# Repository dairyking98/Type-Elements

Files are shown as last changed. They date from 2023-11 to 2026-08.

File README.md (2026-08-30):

# 3D Printed Type Elements for Typewriters

Type elements (shuttles, wheels, typeballs, slugs) for antique
typewriters, generated to order and 3D printed.

The project has three generations. **`v4/` is where active development
happens**; `v2/` and `v1/` are the OpenSCAD lineage it was ported from,
and both still open and render exactly as before.

## v4 (current): Python pipeline + interactive tuner

A Python/`manifold3d` pipeline rather than OpenSCAD - the draft taper is
a real Minkowski sum, every assembly step is a real boolean, and each of
the **15 supported machines** is driven by its own config YAML with an
interactive TUI (`tune.py`) for editing and live-previewing it.

- **[Live documentation site](https://type-elements.leonardchau.com)**
- [`v4/README.md`](v4/README.md) - setup, usage, architecture
- [`v4/LAYOUT_TRANSCRIPTION.md`](v4/LAYOUT_TRANSCRIPTION.md) - how the
  keyboard layouts were transcribed from real manufacturer type catalogs
- [`v4/SESSION_LOG.md`](v4/SESSION_LOG.md) - full development history
- [`v4/CLAUDE.md`](v4/CLAUDE.md) - the conventions and hard-won
  invariants that keep the pipeline correct

Machines: Blickensderfer, Postal, Mignon, Bennett, Helios Klimax,
Hammond, Hammond Split, Selectric I/II, Selectric III, Selectric
Composer, and the Type Slug family (Type Slug, Vogue Slug, Gauge Slug,
Oliver Slug, Lumi Slug).

## v1 / v2 (OpenSCAD): usage

The rest of this file covers the original OpenSCAD workflow. `v2/` is
the shared-library refactor of `v1/`; see
[CHANGELOG.md](CHANGELOG.md) for what moved where.

## Download OpenSCAD snapshot
Download a development snapshot of [OpenSCAD](https://openscad.org/downloads.html#snapshot).

## Open SCAD file
Open an OpenSCAD file. Use the Customizer on the right to create elements and adjust parameters.

## Creating a custom element
1. Install font for all users (right-click the font file > Install for all users).
2. Open an element file.
3. Preview the element and adjust parameters in the Customizer.

## Render and export
Preview → Render → Export STL.

### Meanings
- debug / no minkowski: render element without embossing (faster)
- preview / render / export: typical OpenSCAD workflow

## Documentation

- [Machine specifications](docs/machine-specs.md) — all dimensions and calibrated values per machine
- [Glyph pipeline](docs/glyph-pipeline.md) — how characters are rendered, draft angles, platen cutout, CharLegend
- [Text centering & dead space](docs/text-centering.md) — how `halign="center"` actually centers glyphs, why narrow characters can sit off-center in their slot, and options to correct it
- [Resin support systems](docs/resin-supports.md) — CutGroove, rod geometry, per-machine support placement
- [Resin selection](docs/resin-selection.md) — material choice: glyph fidelity, dimensional stability over time, current printer/slicer/profile setup
- [Calibration procedures](docs/calibration.md) — sweep tests, debugging symptoms, procedure order
- [IBM Composer](docs/ibm-composer.md) — proportional unit system, hemisphere mapping, Composer vs Selectric
- [Refactoring plan](docs/refactoring-plan.md) — shared library architecture, extraction order, old vs new code style (executed as of v2.0, see [CHANGELOG.md](CHANGELOG.md))

## License

Dual-licensed. Which license applies depends on whether a file is
software or design data — [`NOTICE`](NOTICE) has the full breakdown.

| | License | Covers |
|---|---|---|
| **Software** | [GPL-3.0-or-later](LICENSE) | All source — the v4 Python pipeline and tuner, the v1/v2/v3 OpenSCAD files, scripts, site templates |
| **Designs** | [CC BY-NC-SA 4.0](LICENSE-DESIGNS) | Machine dimension/calibration configs, published STLs, renders, documentation |

In plain terms:

- **Print type elements for yourself** — yes, freely. That's what this
  project is for. Give them to other people too, as long as no money
  changes hands.
- **Sell prints** — no. Commercial sale is reserved to the copyright
  holder. If you want to sell them, [ask](https://leonardchau.com) — a
  separate license can be granted.
- **Fork and modify the software** — yes. Keep it open, publish your
  changes under the GPL, keep the attribution.

The split is deliberate: the output of a GPL program isn't covered by
the GPL, so licensing only the code would let anyone regenerate the STLs
and sell them. Licensing the machine data separately is what actually
reserves that.

IBM Selectric geometry was developed jointly with **Otto Koponen**, with
reference material from **[Selectric Rescue](https://selectricrescue.org/)**.
See [`NOTICE`](NOTICE) for full attribution, third-party dependencies,
and a note on fonts.

Contributions are welcome — see [`CONTRIBUTING.md`](CONTRIBUTING.md).

## v2.0: shared library files
`v2/` holds the current, actively-developed set of machine files — a shared
`lib/` (glyph pipeline, resin support, core/shaft, layouts) plus one thin
file per machine. See [CHANGELOG.md](CHANGELOG.md) for what moved where and
which machines share the pipeline. Every v1 file below is untouched and
still opens/renders exactly as before.

- [lib/glyph_pipeline.scad](v2/lib/glyph_pipeline.scad)
- [lib/resin_support.scad](v2/lib/resin_support.scad)
- [lib/core_shaft.scad](v2/lib/core_shaft.scad)
- [lib/testing.scad](v2/lib/testing.scad) — shared calibration-sweep array generator
- lib/layouts/ — [blick](v2/lib/layouts/blick_layouts.scad), [bennett](v2/lib/layouts/bennett_layouts.scad), [mignon](v2/lib/layouts/mignon_layouts.scad), [ibm](v2/lib/layouts/ibm_layouts.scad), [hammond](v2/lib/layouts/hammond_layouts.scad) (postal.scad's single fixed layout stays inline, no separate file)
- [blickensderfer.scad](v2/blickensderfer.scad)
- [postal.scad](v2/postal.scad)
- [bennett.scad](v2/bennett.scad)
- [mignon.scad](v2/mignon.scad)
- [heliosklimax.scad](v2/heliosklimax.scad)
- [ibm.scad](v2/ibm.scad)
- [hammond.scad](v2/hammond.scad)
- [hammond_split.scad](v2/hammond_split.scad)

## v1 SCAD files by directory
The following directories (now under `v1/`) contain the original machine-specific type elements:
- Bennett
  - [BennettElement.scad](v1/Bennett/BennettElement.scad)
  - [BennettLayouts.scad](v1/Bennett/BennettLayouts.scad)
- Blickensderfer
  - [Blickensderfer2.scad](v1/Blickensderfer/Blickensderfer2.scad)
  - [BlickensderferElement.scad](v1/Blickensderfer/BlickensderferElement.scad)
  - [HebrewBlickensderferElement.scad](v1/Blickensderfer/HebrewBlickensderferElement.scad)
- Hammond
  - [GalgolicHammondShuttle.scad](v1/Hammond/GalgolicHammondShuttle.scad)
  - [HammondIndex.scad](v1/Hammond/HammondIndex.scad)
  - [HammondShuttle.scad](v1/Hammond/HammondShuttle.scad)
  - [HammondSplitShuttle.scad](v1/Hammond/HammondSplitShuttle.scad)
  - [HammondSplitShuttle2.scad](v1/Hammond/HammondSplitShuttle2.scad)
- HeliosKlimax
  - [HeliosKlimaxElement.scad](v1/HeliosKlimax/HeliosKlimaxElement.scad)
  - [HeliosKlimaxTester.scad](v1/HeliosKlimax/HeliosKlimaxTester.scad)
  - [imagetest.scad](v1/HeliosKlimax/imagetest.scad)
- IBM
  - [IBM2.scad](v1/IBM/IBM2.scad)
- Mignon
  - [MignonCylinder.scad](v1/Mignon/MignonCylinder.scad)
  - [MignonIndex.scad](v1/Mignon/MignonIndex.scad)
  - [MignonIndexLayouts.scad](v1/Mignon/MignonIndexLayouts.scad)
- Postal
  - [Postal.scad](v1/Postal/Postal.scad)

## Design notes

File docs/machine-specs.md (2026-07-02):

# Machine Specifications

All measured dimensions and calibrated values per machine. Values in the `.json` Customizer preset files are the authoritative source; this document is the summary reference.

---

## Coordinate conventions

**Z=0** is the drive-pin / reference face (seats against machine stop). `charBaselines` and `platenBaselines` are **negative offsets from Z=cylHeight** (the clip end). Absolute Z from reference = `cylHeight + charBaselines[row]`.

> Warning: the scad files are inconsistent. Blick/Postal use negative-from-clip-end. Bennett stores baselines as positive values from the bottom face. Helios stores them as positive from bottom. Reconcile when refactoring into shared library.

---

## Blickensderfer No. 5/7/9

**Active file:** `Blickensderfer/Blickensderfer2.scad`

| Parameter | Value | Notes |
|---|---|---|
| Element OD (`cylOD`) | 34 mm | Fixed |
| Text OD | 35 mm | Fixed |
| Element height (`cylHeight`) | **17.15 mm** | Evolved: 16.75→17.05→17.15 |
| Shaft ID (1/8" nominal) | 3.175 mm | Fixed |
| Shaft bore offset (`coreIDOffset`) | **0.14 mm** | Calibrated |
| Platen OD | 32.258 mm | Fixed |
| Rows × cols | 3 × 28 | Fixed |
| Char baselines from clip end | **[-4.0, -10.3, -16.1] mm** | Stable |
| Platen baselines from clip end | **[-2.55, -8.66, -14.45] mm** | See history below |
| Speed holes | 8 × ⌀5.568 mm at r=11.25 mm | Fixed |
| Drive pin width | 3.737 mm + offset 0.15 mm | New style |
| Drive pin radial | 10.9 mm | Calibrated (from 11.25 mm) |
| Drive pin style | 0 (new) | 1 = old style for early machines |
| Clip height | 3 mm, bite 0.7 mm | Settled |
| Clip wire OD | 0.554 mm | Fixed |
| Wall min thickness | 1.5 mm | Fixed |
| Char protrusion | 0.5 mm | Fixed |
| Draft angle | 55° | Fixed |
| Core grooves | 16 × ⌀0.6 mm | Toroidal bore grooves |

**Platen baseline calibration history:**

| Preset | Row 0 | Row 1 | Row 2 |
|---|---|---|---|
| jan 18 (first) | -2.60 | -8.66 | -14.60 |
| hebrew jan21 | -2.55 | -8.66 | -14.60 |
| MMS2 4/5 | -2.55 | -8.66 | -14.55 |
| MMS3 4/6 / 4/6 Leo | -2.55 | -8.66 | -14.50 |
| **tmp 4/12 → current** | **-2.55** | **-8.66** | **-14.45** |

**Fonts used:** FreeMono (3.0mm), Alma Mono (2.4mm), Souvenir Mono Rg (2.6mm), Clack (3.0mm), True_Vogue (3.3mm), Comic Mono (3.0mm), LTCRemingtonTypewriterW10 (2.6mm), custom scripts.

**Layouts:** DHIATENSOR (default), QWERTY, SCANDI, HEBREW_ENGL, CHARIENSTU_DE.

**CharLegend** (keyboard→element column mapping):
```
[13,12,11,10,9,8,7,6,5,4,3,2,1,0, 27,26,25,24,23,22,21,20,19,18,17,16,15,14]
 ← right half, reversed →          ← left half, reversed →
```

---

## Postal Model 3 (SN 14550)

**Active file:** `Postal/Postal.scad`

| Parameter | Value | Notes |
|---|---|---|
| Element OD | 32.8 mm | Fixed |
| Text OD | 34.1 mm | Fixed |
| Element height | 17.4 mm | Fixed |
| Shaft ID | 3.175 mm (1/8") | Fixed |
| Shaft bore offset | **0.20 mm** | Higher than Blick |
| Platen OD | 31.9 mm | Fixed |
| Rows × cols | 3 × 28 | Fixed |
| Char baselines from clip end | **[-3.6, -10.0, -15.7] mm** | Evolved from [-3.8,-10.2,-15.7] |
| Platen baselines from clip end | **[-2.65, -9.1, -14.5] mm** | Evolved from [-3.4,-9.8,-15.3] |
| Speed holes | 8 × ⌀5.2 mm at r=10.3 mm | Fixed |
| Drive pin width | 2.5 mm | Fixed |
| Drive pin radial | 11.5 mm | Calibrated |
| Clip bite | 0.7 mm | Calibrated |
| Char protrusion | 0.65 mm | Fixed |
| Draft angle | 55° | Fixed |
| Core grooves | 16 × ⌀0.6 mm | Same as Blick |

**Platen baseline history:** [-3.40,-9.80,-15.30] → [-3.00,-9.50,-14.50] → **[-2.65,-9.10,-14.50]**

---

## Bennett

**Active file:** `Bennett/BennettElement.scad`

| Parameter | Value |
|---|---|
| Element OD | 31.9 mm |
| Element height | 18.65 mm |
| Shaft dia | 3.483 mm |
| Platen OD | 30 mm |
| Min char OD | 32.9 mm |
| Rows × cols | 3 × 28 |
| Baselines (**from bottom**) | [15.35, 9.2, 2.75] mm |
| Platen baselines (**from bottom**) | [16.35, 10.65, 4.50] mm |
| Speed holes | 8 × ⌀6.1 mm at r=10.801 mm |
| Countersink top | ⌀23.4 mm, depth 1.85 mm |
| Countersink bottom | ⌀23.4 mm, depth 0.9 mm |
| Positioner pin | ⌀2.6 mm at r=4.813 mm |
| Alignment holes | ⌀2.0 mm, depth 2.4 mm (at every char position on OD) |
| Shell thickness | 1.0 mm |

**Unique:** alignment holes at every character position on the outer diameter face.

---

## Mignon (AEG Mignon 2/3/4)

**Active file:** `Mignon/MignonCylinder.scad`

| Parameter | Value |
|---|---|
| Cylinder OD | 18.64 mm |
| Cylinder height | 40.5 mm (43.5 mm Tallen/Plakatschrift variant) |
| Top shaft OD | 7.3 mm |
| Bottom mounting boss OD | 14.6 mm |
| Platen OD | 26.5 mm |
| Min char OD | 19.4 mm |
| Rows × cols | 7 × 12 |
| Baselines | [2.25, 7.55, 12.75, 17.8, 22.8, 28, 32.8] mm |
| Platen baselines | [2.7, 8.25, 13.6, 18.7, 23.7, 28.7, 33.6] mm |
| Top chamfer | ⌀10.5 mm at offset 3 mm |
| Pin | 1.8 mm height × 1.7 mm wide × 1.0 mm depth |

Layouts: 32+ languages via `MignonIndexLayouts.scad`.

---

## Helios Klimax

**Active file:** `HeliosKlimax/HeliosKlimaxElement.scad`

| Parameter | Value |
|---|---|
| Element OD | 27.15 mm |
| Element height | 18.7 mm |
| Shaft dia | 4.16 mm |
| Platen OD | 30 mm |
| Min char OD | 28.19 mm |
| Rows × cols | 4 × 21 |
| Baselines (**from bottom**) | [3.0, 7.8, 12.5, 17.3] mm |
| Platen baselines (**from bottom**) | [2.5, 7.3, 12.0, 16.8] mm |
| Square shaft hole | 4.10 × 2.88 mm at r=8.92 mm |
| Clip | height 3 mm, dia 7 mm |
| Indicator hole | ⌀2.0 mm at r=10 mm |

Layout: GERMAN (WERTUION keyboard, 4 rows).

---

## Hammond Multiplex

**Active file:** `Hammond/HammondSplitShuttle2.scad`

Prints in two mirror-image halves that slide onto a central folder tube.

| Parameter | Value |
|---|---|
| Anvil OD | 75 mm |
| Arc thickness | 1.6 mm |
| Arc height | 13.26 mm |
| Arc height offset | -2.62 mm |
| Glyph height | 0.8 mm |
| Rows | 3 (Normal), 4 (Math) |
| Chars per row | 30 |
| Degrees per char | 3.75° (=360/96) |
| Folder OD | 21 mm |
| Folder ID clearance | 12 + 0.4 mm |
| Folder thickness | 9.525 mm |
| Pin hole dia | 1.92 mm |
| Pin holes at | 68.27°, 109.97° |
| Pin radial | 7.95 mm |
| Rib OD | 46.8 mm, thickness 2.6 mm |
| Spoke count | 5, extent 45° |
| Left tube OD | 6.6548 mm |
| Right tube OD | 5.842 mm |
| Baselines from rib | [-1.9, 2.825, 7.55] mm |

Layouts: Ideal (default), QWERTY.

---

## IBM Selectric I/II and Composer

**Active file:** `IBM/IBM2.scad` (collaborative with Otto Koponen)

| Parameter | Value |
|---|---|
| Sphere OD | 33.4 mm |
| Max char OD | 34.9 mm |
| Sphere center to top flat | 11.0 mm |
| Top flat thickness | 3.5 mm |
| Inside ID | 28.15 mm |
| Shaft ID | 8.8 mm |
| Boss OD | 11.6 mm |
| Rows | 4 (at ±0°, ±16.4°, ±32.8° longitude) |
| Chars per row | 22 per hemisphere = 44 total |
| Char spacing | 16.36°/char |
| Drive notch | 1.06 mm wide × 2.2 mm tall |
| Platen OD (Composer) | 43 mm |
| Platen OD (Selectric I/II) | 36 mm |
| Snoot droop compensation | 0.42 mm |

**Modes:** `RENDER_MODE=0` = IBM Composer 88-char; `RENDER_MODE=1` = Selectric I/II 88-char.

**Calibrated values:** `PLATEN_LONGITUDE_OFFSETS=[-1.05, -1.05, -1, -1.05]` (one per row).

See `docs/ibm-composer.md` for the proportional spacing system.

---

## Type Slugs

**Files:** `Type Slugs/TypeSlug.scad` and variants (Vogue, Oliver, Lumitype).

Flat individual slugs for conventional typebar machines (not type elements). Two characters per slug (upper/lower case). Parametric wing curve for typebar slot, platen cutout, Minkowski draft angle on glyph faces. Default body: 2.75 × 12.0 × 5.0 mm.

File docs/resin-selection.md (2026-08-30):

# Resin Selection

Notes on resin material choice for printing type elements, as distinct from
`resin-supports.md` (which covers support *geometry*, not material). Kept here
because the choice is really a legibility/durability tradeoff specific to
glyph faces, not a general printing note.

---

## Priorities for this use case

Type elements are graded on one thing above all: **glyph face fidelity**.
Sharp serifs, clean stroke edges, and legible small type at the scale these
elements print at matter more than surviving a drop or a hard strike. The
elements sit in a machine and take repeated but low-energy impact against a
ribbon/platen — not the kind of abuse a handled miniature takes. That reframes
the usual "detail vs. durability" resin tradeoff: durability past a fairly low
bar is wasted margin here, and buys real fidelity loss.

The exception is thin structural features that aren't glyph faces — support
necks, drive pins, boss walls (see `resin-supports.md`) — which take bending/
torque loads, not impact, and can still snap if a resin is too brittle at a
thin cross-section. Detail-vs-durability trades off against glyph sharpness;
it doesn't excuse ignoring wall thickness at those specific spots.

**Dimensional stability over time is a co-equal priority**, added after the
fact — see its own section below. It is not in tension with fidelity; both
point away from the same family.

---

## Current setup

Recorded 2026-08-29 by reading the actual installed state, not from memory.
The rig lives on the **laptop's Windows partition** (`/media/lchau/Windows`,
user `leona`), not in this repo and not on the Windows desktop box.

| | |
|---|---|
| Printer | Anycubic Photon Mono 4K — 3840x2400, 35 um pixel pitch, 132.9 x 80 x 165 mm |
| Slicer | Anycubic Photon Workshop 4.1.8 |
| Also installed | UVtools (generated the exposure tests below); Bambu Studio (FDM, unrelated) |
| Rejected | Lychee Slicer — requires an account and network access; installed 2026-07-26, uninstalled the same day |

**Active resin profile** (`active_resins` in Photon Workshop's `.pwsp`):

    Elegoo ABS-Like 3.0
    0.05 mm layer - 3.0 s exposure - 30 s bottom x 6 layers
    lift 5 mm @ 1.33 mm/s - retract 3.5 mm/s - 0.5 s rest

Sourced from Elegoo's official settings spreadsheet, **Mars 3 row** — Elegoo
publishes no Anycubic rows at all, and the Mars 3 is the closest analog
(also 4K mono at 35 um). The 3.0 s figure is corroborated by a second
cross-brand chart; the 30 s bottom is the top of Elegoo's verified band
rather than the 35 s an unverified PDF gave. These are **vendor-chart
starting values, not measured on this machine** — see the open exposure
test below.

Profile files, for anyone repeating this:

- `%LOCALAPPDATA%\ANYCUBIC\AnycubicPhotonWorkshop_V4.1.8\machine_type\Anycubic Photon Mono 4K.pwsp`
  — the real parameter sets (`user_resins`, `active_resins`)
- `...\resin_type\custom_resin_names.json` — the picker's index; name/brand/
  density/price only, no exposure values
- Backups: `Documents\PhotonWorkshop_profile_backup` (2026-07-26)

Siraya Tech's full 37-profile catalog is imported alongside the Elegoo entry
(38 custom profiles total). That was a bulk vendor-pack import for
convenience, **not** a shortlist of considered resins — don't read the
contents of that picker as a selection history.

---

## Resins tried

| Resin | Verdict | Notes |
|---|---|---|
| Generic ABS-like | Reasonable middle ground | Good general toughness, but not what maximizes satisfaction here — leaves detail on the table without buying anything this use case needs. |
| Siraya Tech Blu (tough/ABS-like family) | Too strong for this purpose | Genuinely tough, cool resin to work with, but that same toughness (added elastomeric content, higher viscosity) made it hard to get fine glyph details right — soft/blurred edges on small type. |
| Siraya Tech ABS-Like Gray ("Fast" line) | Owned; no results recorded | Official values 1.6 s / 20 s bottom. Was the original target of the 2026-07-26 profile work before switching to the Elegoo. |
| Elegoo ABS-Like 3.0 | Owned; **currently active**; no results recorded | Profile above. No print results, measurements, or glyph-fidelity notes exist for it yet. |

**Takeaway:** the strength these tough resins add isn't spent on anything the
type elements need, and it's actively traded against the one thing that is
needed (sharp glyphs). Note that **every resin in the table is ABS-like** —
including both currently owned. The family has never actually been left.

---

## Dimensional stability over time

Added 2026-08-29. Prior resin work here optimized entirely for exposure
accuracy and plate adhesion; long-term dimensional drift was never
considered, and the resins on hand are the worst available choice for it.

Why it matters for this project specifically: character pitch on a ball or
wheel is a hard constraint. On a 33.4 mm Selectric sphere, 0.5 % of drift is
~0.17 mm of position error — enough to visibly misalign a strike.

### Two distinct phenomena, often conflated

**Cure shrinkage** — 1–8 % volumetric, during print plus post-cure. One-time
and compensable with a scale factor. This is what a `shrinkage_multiplier`
is for.

**Long-term drift** — the actual concern. Three mechanisms:

1. **Dark cure.** Unreacted monomer keeps polymerizing for weeks to months.
   The largest contributor, and mostly a *process* problem rather than a
   material one — under-cured parts keep shrinking.
2. **Physical aging and creep.** The glassy network relaxes. Strongly
   dependent on service temperature *relative to Tg*: a resin with Tg near
   room temperature creeps continuously; one with Tg well above it barely
   moves.
3. **Residual monomer as plasticizer.** Incompletely washed parts stay soft
   and creep for their whole service life.

### What resists it

The two specs that predict stability are **glass transition temperature
(Tg/HDT)** and **filler content**. High Tg plus filler is stable. This
inverts the usual intuition:

- **"Tough" / "ABS-like" / flexible resins are the worst case.** They buy
  toughness by lowering crosslink density and Tg — exactly the properties
  that produce creep. This is the family both currently-owned resins belong
  to.
- **Filled resins** (glass/ceramic) shrink and creep proportionally less
  because the filler does neither. Formlabs Rigid 10K / Rigid 4000 and
  Forward AM Ultracur3D RG are the engineering-grade examples.
- **High-Tg engineering resins** — e.g. Liqcreate Strong-X, Phrozen's
  high-temp lines — are marketed on exactly this property.
- **Cationic epoxy / epoxy-acrylate hybrids** shrink ~1–2 % instead of 5–8 %
  and age far better, but are slow-curing, humidity-sensitive, and largely
  industrial.

Treat specific product names as leads to verify rather than settled facts —
vendors reformulate under unchanged product names, and datasheets rarely
disclose that shrinkage is anisotropic (Z differs from XY).

### Process matters at least as much as brand

Wash thoroughly (residual monomer is the enemy), dry fully before curing,
post-cure warm (40–60 °C) and long — ideally water-submerged to defeat oxygen
inhibition — then store away from UV and heat. Ambient UV keeps crosslinking
parts for years: they shrink and embrittle on the shelf.

### How this interacts with the fidelity-first framing above

It mostly **agrees**. Standard/high-detail resins have higher crosslink
density, higher Tg, and no elastomeric content, so moving off the
ABS-like/tough family improves sharpness *and* stability together. The
"Resins to try next" list below is not in conflict with this section.

The one genuine tension is **filled** resins: filler is the strongest lever
on creep, but raises viscosity and scatters light, which is the exact
mechanism that blurs small type. If a filled resin is ever tried here, glyph
fidelity has to be re-checked from scratch rather than assumed.

### Compensation support in the codebase

Only Hammond has a shrinkage-compensation knob —
`config/hammond.yaml`'s `element.shrinkage_multiplier` (a v2 inheritance,
currently `1.00`, i.e. off). **No other machine has any global scale
compensation.** If a real per-resin shrinkage figure is ever measured, there
is currently nowhere to apply it on the cylinder or spherical families; that
is an open design decision, not an oversight to silently patch.

---

## Direction: trade strength for detail

Standard/high-detail resins are lower-viscosity and scatter less light during
cure, which is what actually produces sharp small-scale type — not a
side effect but the direct mechanism. Moving off the ABS-like/tough family
into this category should be a straight upgrade for glyph fidelity, at a
durability cost this use case mostly doesn't need to pay.

**Resins to try next:**

- **Phrozen Aqua-Gray 8K** — formulated specifically for high-res 8K/12K mono
  LCD screens rather than repurposed general-use resin. Matte grey finish is
  a practical bonus: glyph legibility is easy to inspect straight off the
  plate, no primer needed.
- **Phrozen TR250 LV** ("Low Viscosity") — same high-resolution-screen intent
  as Aqua-Gray, explicitly marketed for fine engraved text. Also a high-Tg
  formulation, so it is the one entry on this list that serves both the
  fidelity and the stability priority.
- **Siraya Tech Fast** (or a plain "Standard", non-ABS) — if the jump to
  full detail-resin brittleness feels too far, this is the middle-ground
  fallback: tougher than Aqua-Gray/TR250, softer edges than either, but
  still meaningfully sharper than the ABS-like/Blu family. **Caveat:** Siraya
  markets its ABS-Like Grey *as* the "Fast" line, so this entry and the
  Siraya ABS-Like Gray in the table above may be the same product. Confirm
  the exact SKU before treating this as a change of family rather than a
  relabel.

---

## Open items

- **The exposure calibration was generated but never run.** Five sliced
  files at 2.0 / 2.5 / 3.0 / 3.5 / 4.0 s sit in
  `Desktop\ExposureTest_ABSLike3\` (2026-07-26): ~0.62 mL and ~13 min each,
  40 layers at 0.05 mm, carrying a glyph strip, a bullseye target, graded
  bar grids, and the settings embossed on the part. Read them by picking the
  *lowest* exposure where the glyph strip stays crisp and the bullseye rings
  stay separated. **Do this before any shrinkage measurement** —
  over-exposure causes its own dimensional bloat and would confound the
  result.
- **No shrinkage baseline exists.** A coupon with known-length features,
  printed per candidate resin and measured at 24 h / 1 week / 1 month /
  6 months, would beat any datasheet — and would give the anisotropy that
  datasheets omit. The calibration infrastructure in v4
  (`CalibrationElement` / `CalibrationTextRing`, see `calibration.md`) is
  the obvious place to build it from.
- Does Aqua-Gray/TR250 brittleness cause snapping at the support-neck /
  boss-wall features documented in `resin-supports.md`, given those already
  take bending load rather than impact? Watch the IBM boss two-tier support
  and Hammond fence joints specifically — thinnest cross-sections in the
  current support systems.
- Record actual glyph-edge results here once a batch is printed in
  Aqua-Gray/TR250, alongside which printer/pixel-size it was printed on
  (see machine notes on printer shortlist — pixel geometry and resin
  viscosity both affect edge sharpness, worth separating the two variables).
- Older resin profiles from before this rig ("profiles ive used in the
  past") were wanted for cross-reference on 2026-07-26 but were not
  accessible then, and have not been located since. If they turn up, the
  "Resins tried" table is where they belong.

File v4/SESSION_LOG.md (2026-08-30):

# v4 session log

Chronological record of this session's work, for resuming later. See
`README.md` for the architecture/usage reference of the *current* state;
this file is the history and the "what's next."

## Where things stand right now (latest session, branch `v4-tui`)

- **`tune.py`, an interactive `textual` TUI, was built essentially from
  scratch this session** and now covers the entire config: Font &
  Alignment, Type Test, Resin, Gauge, Build, Layout, Quality, Logo,
  Element tabs, a master/running/saved config-tier system, a real file
  browser (`textual-fspicker`) for font paths and Save, and an f3d
  auto-launch/raise integration for live preview. See README's
  "Interactive tuner" section for the current-state reference; this log
  section (part 7 below) has the blow-by-blow.
- **Critical correctness fix: struck characters were never mirrored.** A
  struck type element must carry a mirror image of the printed glyph
  (same reason a stamp/slug is cut reversed) - v2's `TwoDText` does this
  (`mirror([1,0,0])`), v4 never did until this session. Fixed in
  `build_glyph()`; also resolved the previously-reported "x offset wrong
  direction" bug as a side effect (same missing mirror). See README's
  "Character mirroring" section.
- **Shaft Gauge Test ported from v2** (`GaugeTestSet` and its whole
  supporting cast) - a standalone calibration print for finding
  `element.core_id_offset`, plus its own Gauge config section and tuner
  tab. See README's "Shaft Gauge Test" section.
- **Draft angle is now config-driven** (`build.draft_angle_deg`, default
  55 - the real machine value) instead of a fixed `glyph_poc.py` constant.
  Exposed on tune.py's Font & Alignment tab.
- Everything from the previous session (the real-Minkowski-sum draft
  rewrite, the real platen cutout, the facet-count/preview config
  expansion) is unchanged and still the current mechanism - see "Where
  things stood" below (renamed from "right now") and parts 1-6 for that
  history.

## Where things stood at the end of the previous session

- **Branch at the time: `v2-refactor`.** The draft taper mechanism had
  just been completely rewritten: `build_glyph` in `lib/glyph_poc.py`
  builds it via a real Minkowski sum (`manifold3d.Manifold.
  minkowski_sum`), replacing the per-vertex outline-offset approach (and
  its self-union patch, added and then removed again that same session -
  see below) entirely. That old code is gone, not kept behind a flag.
- Every character that was broken at any point that session - `H`, `e`,
  `m`, `^`, `M`, `A`, `i`, `o`, `0` - was confirmed clean: watertight,
  winding-consistent, `is_volume=True`, no self-intersection possible by
  construction, correct platen scallop on both curvy and straight-stroke
  letters.
- **Real cost accepted: generation time.** A boolean CSG call replaces
  plain coordinate math. ~60-70s for the full 84-character ring + assembly
  at the config's default quality (`points_per_mm=15`, `cone_segments=16`),
  ~16-35s at faster settings (`--points-per-mm 8 --cone-segments 12` or
  lower) with only minor visual quality loss - see README's "Performance"
  section.
- **Known-accepted, still open, unrelated to the draft mechanism:** 61
  inter-character collisions at `separation_mm=2.0` (confirmed real via
  direct boolean intersection, sitting at the embedded root end - not
  visible from outside), and the `HollowSpace` margin flag (flickers
  `True`/`False` run to run from floating-point noise at a razor-thin
  boundary - documented, not new).
- **`separation_mm=1.0` still NOT reapplied.** Earlier in that session it
  was found to eliminate the inter-character collisions entirely (at the
  cost of less embedding-depth margin) - undone by the full revert (see
  "The detour" below) and never reintroduced. Config still has
  `separation_mm=2.0`, still 61 collisions. `logo.radial_offset_mm` WAS
  reapplied (see part 6 below), but at the real v2 value (1.5), not the
  earlier session's tuned value for the now-reverted `separation_mm=2.0`
  near-miss investigation - re-check if that near-miss matters again.
- **Real platen cutout + facet-count/preview config expansion (part 6,
  most recent work) landed on top of all of the above** - see that
  section for the current state of `quality.*`/`logo.radial_offset_mm`/
  `build.minkowski_enabled`.

## 1. Started from last session's resume point: the naive-offset baseline

Picked up with the per-vertex draft offset (`make_back`/
`orthogonal_offset_vertex`/`join_front_back`) still in its accepted,
detection-only state (self-intersection on tight glyphs, not repaired).
Investigated a visible artifact on the ring: the `H` self-intersecting
fold, first suspected to be caused by `LogoText`'s "Leonard Chau 2025"
engraving crossing the DHIATENSOR `k`/`K`/`_` column (a real, separate,
near-miss - the logo character `a` in "Leonard" landed within 0.17deg of
that column's angle, only 0.37mm of Z clearance) - fixed by adding a
`logo.radial_offset_mm` knob and re-sweeping it against both the character
band and `SpeedHoles` clearance.

But the fold on `H`/`k`/`K` turned out to be a separate, pre-existing
issue: the same self-intersecting-draft-offset limitation documented in
`README.md`, just grown large enough to be visually obvious once
`DEFAULT_SEPARATION_MM` had been bumped from the real 0.5mm to 2.0mm in an
earlier session (for embedding-depth margin - see the code comment history
for why). Swept `separation_mm` from 0.5 to 2.0 and confirmed the fold's
*magnitude* scales with it (expansion width = `separation_mm *
tan(27.5deg)`), even though the underlying self-intersection is present at
every value tested, even the real 0.5mm.

This led to checking the actual physical tradeoff directly:
`embedding_depth_mm = separation_mm - Char_Protrusion` - at the real
0.5mm value, the character root lands EXACTLY on the main cylinder's own
surface radius, zero embedding. Confirmed the self-intersecting fold
becomes visually obvious somewhere between `separation_mm=0.6` and `0.7`.

## 2. Gated self-union repair - implemented, then found to be unsafe

Implemented a loop-type-aware self-union repair in `build_glyph`:
classify each outline loop as outer-island vs. hole using the *un-offset
front loop's* signed area (a severely self-intersecting hole, like `e`'s,
can flip its own post-offset signed area, so classification has to happen
before the offset is applied) - self-union only when every non-simple loop
is an outer island, never a hole (confirmed earlier: self-union caps a
hole with a spurious flat membrane instead of fixing it). This cut
unresolved self-intersection from 71/84 to 11/84 at `separation_mm=0.5`.

User found this had NOT actually fixed everything - `^` still showed a
visible artifact. Investigation found the real problem: `manifold3d`'s
`mesh.union(mesh)` on a MULTI-ISLAND glyph (a disjoint dot separate from
its stem - `i`, `j`, `;`, `?`) doesn't reliably keep the islands separate;
it can weld them together and lose real volume (confirmed on `i`:
12.47+3.25=15.72mm3 of real islands before repair, only 10.85mm3 survived
after, replaced by zero-volume debris). Also found manifold3d's boolean
routinely produces dozens of disconnected zero-volume debris slivers even
on genuinely single-island repairs (36/48 repaired characters, up to 94
slivers on `8`) - harmless to `watertight`/`is_volume` checks but real
debris in the final STL.

Fixed both: gated self-union to single-island glyphs only (multi-island
non-simple glyphs, 4/84, stay detection-only), and stripped near-zero-
volume components after any self-union. Net result at that point: 44
auto-repaired, 27 genuinely unrepaired (down from 71 broken originally).

## 3. The detour: "completely reapproach this at a different angle"

Tried `separation_mm=2.0` (the original, most-broken setting) with the
gated self-union repair active - 48 auto-repaired, 23 still unrepaired,
watertight throughout. But then `m` still showed a visible fold even with
the repair in place, and the user called for a full stop: "characters
still fucking up... undo all measures we did." Reverted `config/
blickensderfer.yaml`, `lib/blickensderfer.py`, `lib/glyph_poc.py` to the
last commit (`67ea8d4`) - back to the naive-offset baseline, detection-
only, no self-union, none of the separation/logo-radius tuning above.

Discussed real alternatives instead of continuing to patch the per-vertex
technique: (1) resume the unfinished `shapely.buffer()`-based lofted taper
on the (still-preserved) `v4-real-offset` branch, or (2) check whether a
REAL Minkowski sum via `manifold3d` (which this whole project originally
avoided for performance reasons) is viable now. Checked - `manifold3d`
exposes `Manifold.minkowski_sum`/`Manifold.cylinder` directly. Prototyped
it on `H`/`e`/`m`/`o`/`i`/`^` (the hardest failures): all watertight,
winding-consistent, `is_volume=True`, zero self-intersection by
construction - including `e` and `m`, which nothing in the naive-offset
line of work had ever fully resolved. Measured cost: ~16-66s for the full
ring depending on quality settings, vs. ~3-6s before. Decided to build
this in as the real replacement.

## 4. Building the real Minkowski-sum draft mechanism

Rewrote `build_glyph` in `lib/glyph_poc.py`: extrude the flat glyph into a
thin prism, `Manifold.cylinder()` for the draft cone, `minkowski_sum()`,
convert back to `trimesh`. Removed the now-dead `back_loops_are_simple`/
`classify_back_loops`/self-union machinery entirely (kept `make_back`/
`orthogonal_offset_vertex`/`join_front_back`/`make_front`, since
`build_flat_text` - `LogoText`'s flat-engrave pipeline - still uses them
with zero offset, which never had a self-intersection problem). Wired a
new `cone_segments` knob through `TextRing`/`Additive`/`FullElement`/
`ResinPrint`/`generate.py`/the config, alongside `points_per_mm`. Updated
`TextRing`'s reporting to drop the now-impossible self-intersection
checks, keeping only inter-character collision detection (a genuinely
separate, placement-driven issue).

Found and fixed three real, separate bugs while building this, in order:

**Bug 1 - doubled depth.** First version extruded the prism to the full
`separation_mm` height AND gave the cone its own full `separation_mm`
height. Minkowski sum ADDS extents in each dimension, so the result came
out `[0, 2*separation_mm]`, not `[0, separation_mm]` (confirmed: `H`'s
z-range was `[0, 4.0]` at `separation_mm=2.0`). Fixed by shrinking the
prism to a thin sliver (`tip_h`, ~0.01mm) sitting at the tip end, letting
the cone alone carry (almost) the full depth.

**Bug 2 - cone origin/dilation direction reversed.** User caught this:
"the minkowski cone shape origin is wrong, the origin should be at the
tip." `manifold3d`'s `cylinder()` places its local origin at the
`radius_low` end - the first fix attempt flipped `radius_low`/
`radius_high` AND translated, which canceled out and put the dilation
back at the TIP instead of the root (confirmed directly: tip came out
wider than root, exactly backwards - `watertight`/`is_volume` don't catch
a reversed-but-still-valid draft, only checking cross-section width at
`z=0` vs. `z=separation_mm` does). Fixed by keeping the cone's original
wide-at-bottom/apex-at-top construction and only translating the whole
cone by `-cone_height`, landing the apex exactly at the origin. Verified:
root width minus tip width = exactly `2*expansion_width_mm`.

**Bug 3 - manifold3d's raw triangulation noise.** User spotted "facet
angles are inconsistent... like a poorly done minkowski" on straight
edges (`M`'s strokes). Confirmed: a single straight wall came out as ~24
near-coplanar micro-triangles with normals wobbling by a fraction of a
degree - real CSG-algorithm noise, not a geometry error (face-normal
check on the wall showed the wobble directly; `Manifold.simplify()`
collapsed 2918 triangles down to 182 at even 0.0005mm tolerance, into a
single flat face per straight run). Added `simplify_tolerance_mm` (default
0.005mm, config + CLI knob) applied to the `minkowski_sum` result.

User also asked whether reducing the prism's height ("just do a slice of
the curved part") would speed up the Minkowski call. Tested directly:
face count (and timing) is unaffected by `tip_h` - a straight extrusion's
face count depends on its 2D cross-section, not its Z-thickness. The real
cost driver is `points_per_mm` (already exposed), and the cap
triangulation is already minimal (`triangle_args='p'`, no added Steiner
points) - no free win available there.

## 5. Bug 4 - platen curve applied in the wrong order

User: "are you doing minkowski first, then adjusting the top surface for
platen curvature? ... the draft angle loses angle spec after adjustment."
Correct diagnosis. The version at that point warped only the SWEPT
RESULT's top ring into the platen parabola, after the Minkowski sum -
meaning the cone's own geometry (and therefore the realized draft angle)
was only ever valid for a flat tip; nudging just the final ring left the
walls built as if the tip were still flat. Visible specifically on
horizontal runs far from `radius_y_offset` (the platen's tangent point) -
`M`/`A`'s bottoms, not `L`/`I`'s mostly-vertical runs which stay close to
it. Confirmed this also matches how the real `v2/lib/glyph_pipeline.scad`
avoids the problem: `PlatenCutout()` is subtracted from the base
extrusion BEFORE the `minkowski()` call there, never patched onto the
result after.

Fixed by moving the platen Z-warp to the PRISM's top cap, before the
Minkowski sum, instead of the swept result's top ring after. Verified
numerically (root width minus tip width still exactly
`2*expansion_width_mm` - the warp doesn't disturb the dilation amount)
and visually (`M`/`A`'s bottoms now match `L`/`I`'s clean quality, no
faceting).

Also had to re-verify the earlier `simplify()`-before-warp ordering bug
from step 4 didn't reappear: `simplify()` must run on the CURVED result
now (after the prism warp + Minkowski sum), not on a still-flat
intermediate, or it aggressively over-collapses large flat regions before
they're curved (confirmed: straight-stroke letters lost platen-curve
fidelity while curvy letters looked fine only because their outline's own
curve-driven vertex density happened to survive). Final order per
character: warp prism top cap -> Minkowski sum -> simplify.

## 5.5. Checkpoint, then a real assembly bug found by inspection

Committed and pushed the Minkowski rewrite (README/SESSION_LOG rewritten
to match). Then, from exporting every character to its own STL for visual
inspection (`export_glyphs.py`, new this round - real per-row config
values, not generic defaults, so what you see matches the actual
element), user noticed no clean edge forms where a character meets the
main cylinder in their viewer.

Root cause: `TextRing()`/`Additive()` were the only two assembly functions
in `lib/blickensderfer.py` using `trimesh.util.concatenate()` to combine
parts - everything else (`Subtractive`, `SpeedHoles`, `DrivePin`,
`ResinSupport`, ...) already used `sp.union_all()` (a real `manifold3d`
boolean). `concatenate()` just merges vertex/face arrays with zero
boolean resolution, so wherever a character's embedded root overlapped
the main `Cylinder()` (by design - that's what "embedded" means) or two
characters overlapped each other (61 confirmed pairs), both surfaces
stayed fully intact and superimposed - no new edge formed at the actual
intersection. Confirmed via volume: concatenating measured 1148mm3 MORE
than a real union of the same parts (the double-counted overlap).

Fixed both call sites to use `sp.union_all()`. Also switched
`union_all()`'s own implementation from a sequential `trimesh.union()`
fold to `manifold3d`'s native `Manifold.batch_boolean()` - ~30x faster on
the real 86-part case (2.43s -> 0.08s, identical volume), since the fix
now unions far more parts than `union_all`'s original ~12-part use cases.
Committed and pushed separately from the Minkowski rewrite.

## 6. Real platen cutout + facet-count/preview config expansion

User: "the parabola should be a cylinder like blickensderfer" - confirmed
the platen mechanism was still taking the flat glyph's top-face vertices
and moving each one's Z by the small-angle-approximation formula (a
vertex nudge, not a real swept surface), and asked for the real thing.
Also asked for several new config knobs: `logo.radial_offset_mm` back
(reverted in "the detour", never reapplied), a `minkowski_enabled`
toggle for fast previews, and separate facet-count (`_fn`) knobs per
surface family instead of the existing `surface_fn` catch-all - clarified
in conversation: inner shaft (`cyl_fn`, unchanged) and outer cosmetic
body should be SEPARATE knobs (not merged), both may be set to 360; the
platen cutout needs its own `platen_fn` once it's a real cylinder.

**Real platen cutout**: `platen_radius_mm` (the existing small-angle
approximation coefficient, `1/(2*Rp)`) is inverted to recover the real
platen radius `Rp` - no new parameter needed. Built as an actual
`Manifold.cylinder()` (axis along X via `.rotate([0,90,0])`, tangent to
the tip plane at `y=radius_y_offset`), boolean-subtracted
(`Manifold.__sub__`) from the glyph block BEFORE the Minkowski sum - same
ordering lesson as part 5, just with a real cylinder instead of a warp
now. Verified the construction directly (cylinder bounds/tangent-point
sampled and checked against the exact circle formula, then a synthetic
carved-block test checked point-by-point against `z = sep + Rp -
sqrt(Rp^2-(y-off)^2)`) before wiring it into `build_glyph` - a synthetic
test with too-small margin caught a real design requirement along the
way: the block must be tall enough, PER GLYPH, that the cylinder reaches
every Y this specific glyph spans, or the corners farthest from
`radius_y_offset` survive uncut (still flat) instead of following the
real curve. Margin is now computed per-glyph from the exact bulge formula
(`Rp - sqrt(Rp^2 - dy_max^2)`), not a fixed guess.

Confirmed the real cylinder's own axis position/radius depend only on
`radius_y_offset`/`Rp` - both per-ROW constants - so it's identical for
every character in a row by construction, addressing a design question
raised mid-session about keeping node/curve consistency across a row
without needing to explicitly force it.

Verified: `z_max` values match the old parabola approximation to within
0.0006mm (expected - the parabola IS that circle's small-angle
approximation), same watertight/`is_volume`/volume figures as before,
visually clean on `H`/`M`/`A`/`e` (the platen-order failure cases from
part 5). Per-character timing actually improved slightly (no more
per-vertex Python loop).

**`minkowski_enabled` toggle**: when `false`, `build_glyph` skips the
Minkowski sweep entirely and returns the scalloped-but-undrafted block -
correct platen curve and placement, no taper. Full ring + assembly in
~3s vs. ~22-70s depending on quality settings - verified end-to-end via
`generate.py --no-minkowski`.

**Facet-count reorganization** (`quality:` in the config): added `body_fn`
(main visible cylinder body - `Cylinder`/`ClipCylinder`, was incorrectly
sharing `surface_fn` with unrelated detail surfaces), `platen_fn` (the
new real cutout cylinder), and renamed the Minkowski cone's segment count
from `build.cone_segments` to `quality.minkowski_fn` (grouped with the
other four `_fn` knobs now) - old `build.cone_segments` key still works
as a fallback for configs that haven't been updated. `cyl_fn` (inner
shaft/core) and `surface_fn` (other structural detail) are unchanged.

**`logo.radial_offset_mm` reapplied** at the real v2 value (1.5mm) - NOT
the earlier session's tuned value (which was specific to the
now-reverted `separation_mm=2.0` near-miss investigation in part 1). Real
value confirmed via the config comment to still land within ~0.4mm of a
DHIATENSOR column at this exact text/spacing - not currently an issue,
worth re-checking if either changes.

## 7. Building `tune.py`, an interactive config TUI (new session, branch `v4-tui`)

Started from a request to stop hand-editing YAML between test renders.
Built `tune.py` (`textual`) incrementally, tab by tab, fixing real bugs
found along the way:

**Core structure.** A generic `SECTIONS`/`FIELDS` table drives most tabs
(`(yaml_key, [path, into, cfg], type, label, help_text)` tuples), so most
new config fields only need one table entry to get compose/collect/
save/reload behavior for free - used for the later Gauge and draft-angle
additions. A few tabs (Layout, Build, Type Test) are bespoke since they
need dropdowns/switches/multi-line text rather than plain fields.

**Config tiers.** Editing the master YAML directly risked losing the
"known-good, matches v2" reference file to exploratory tuning. Built a
three-tier scheme instead: master is read-only from the TUI's
perspective; all edits/saves go to a gitignored `*.running.yaml` scratch
copy, auto-created and auto-migrated (`_migrate_running_config` backfills
missing top-level AND nested keys from master into a stale running copy
without touching customizations) on load; an explicit Save writes the
running copy out to wherever you choose via a real file browser
(`textual-fspicker`'s `FileSave`/`FileOpen`, added after a plain
`Input`-based path field proved error-prone for font paths especially).

**Workflow buttons and f3d integration.** Iterated through several designs
for "how do I see what I just changed": an initial manual "launch f3d"
button, then auto-launch/raise on Render (`_ensure_f3d_after_build()` -
starts f3d fresh if not running, or `wmctrl -a f3d` to raise an existing
window), then a dedicated Top View camera for text preview specifically
(`f3d_top_view_cmds.txt`'s `set_camera top`, via f3d's `--command-script`
flag - found by `strings`-ing `libf3d.so` for camera-related command
names after a hand-derived `--camera-direction=0,0,-1` guess came out
rotated 90° wrong, confirmed by direct user testing) plus
`--camera-orthographic`. f3d is killed on quit/terminal-close so it
doesn't accumulate zombie windows across tuning sessions.

**Type Test tab.** A flat, non-cylindrical CPI/LPI-spaced text preview
(`type_test.py`) for instant font/legibility iteration, independent of
the real element pipeline - persists its own text/CPI/LPI to
`type_test:` in the config. Later given the same modified-left/right
alignment handling as the real `TextRing`, so what you see here actually
matches final placement.

**Bug: quit didn't save.** Plain `q` never fires while any Input/TextArea
has focus (Textual consumes it as literal typed text, not a binding) -
easy to hit by accident after typing in a field and hitting `q` out of
habit. Fixed by adding `ctrl+q` as a second, reliable binding (needed
`loop.add_signal_handler`, not plain `signal.signal()` - the latter was
found to leave signals unfired for seconds while the event loop is
blocked) and having both quit paths save first (`_save_before_exit`).

**Bug: `Select.BLANK` crashes on mount.** In the installed `textual`
version, `Select.BLANK` is aliased to the plain boolean `False`, not the
real "no selection" sentinel (`Select.NULL`) - using it as a value
crashes `Select`'s own mount-time validation. All usages (Layout tab's
preset dropdown) fixed to `Select.NULL`. Discovered while testing the
Gauge tab, only surfaced once the real config's `layout.rows` first
became genuinely "custom" (non-matching any preset).

**Layout tab: preset editor with a live read-only preview + unlock.** A
dropdown of presets (QWERTY, DHIATENSOR, ...), 3 read-only rows previewing
whichever preset is currently selected, and a "Modify glyphs" switch that
reveals 3 editable rows (seeded from whichever preset was showing when
unlocked) whose hand-edited content is what actually gets saved to
`layout.rows` - not the preset dropdown's value - whenever the switch is
on (`layout.modify_glyphs: true` in the config, matching how the running
config already looked from earlier hand-editing).

**Bug: Layout tab's read-only preview stopped updating on dropdown
change.** Root cause: the preview-row helper
(`_display_rows_for_preset()`) derived "the current preset" from
`self.cfg` (disk state, only refreshed on save/reload), not the
dropdown's own live in-widget value - so browsing the dropdown without
saving left the preview frozen on whatever was last saved. Fixed by
adding a second helper, `_rows_for_layout_select_value(value)`, that
takes the live value directly and is used by both `on_select_changed`
(browsing) and `on_switch_changed` (seeding the editable rows on unlock)
instead of the disk-state-based one - `_display_rows_for_preset()` itself
is unchanged and still correct for its own remaining callers
(`compose()`/`_refresh_widgets_from_cfg()`, where `self.cfg` and the
dropdown are legitimately in sync). Verified via direct headless tests; a
first test run gave a false negative from a `True -> True` no-op Switch
reassignment (the real config already had `modify_glyphs: true`), which
looked like the fix hadn't worked until re-tested with a genuine
`False -> True` transition.

**Build tab: iterated to a dropdown + independent checkbox.** First pass
was a 3-option dropdown (Element Only / Element Resin Print / Shaft
Gauge, `build.target` string) added alongside the new Gauge tab port
(next item). Simplified per direct feedback to a 2-option dropdown
(Element / Shaft Gauge) plus a separate "Resin supports" checkbox,
independent of which target is selected - Element uses the checkbox to
choose `FullElement()` vs `ResinPrint()`; Shaft Gauge always builds with
its own resin supports built in regardless of the checkbox, since a gauge
print can't stand on its own. `_refresh_widgets_from_cfg` maps any stale
`target: "resin"` value (from the first-pass 3-option version) back to
`"element"` for backward compatibility with configs saved during that
window.

**Gauge tab: ported v2's `[Shaft Gauge Test]` feature.** `GaugeTestSet`
and its supporting module (`CylinderGauge`, `GaugeResinSupport`,
`GaugeResinSupportsRaft`, `RevolverSolid`, `GaugeText`,
`GaugeTestSubtractive`) added to `lib/blickensderfer.py`, ported closely
from `blickensderfer.scad`. `RevolverSolid()` (hull of the 6 gauge-pocket
cylinders) uses `trimesh.util.concatenate(...).convex_hull`, matching the
existing `CoreEllipses()` pattern, since trimesh has no hull-of-solids
primitive. Found and fixed a real porting bug: `GaugeText()`'s
`sp.scad_transform` had rotate/translate in the wrong order relative to
v2's source (`translate() rotate([0,90,0])`, translate outermost) -
caught because the text mesh's own Z-center bounds came out at ~-2.57
instead of the expected 11.325; fixed by reordering to
`("translate", [...]), ("rotate", [0, 90, 0])`. New tuner tab added with
`Gauge_Offset_Start`/`Gauge_Offset_Int` fields and an explanatory banner
about the calibration workflow (print, test-fit each numbered pocket on
the real machine, set `core_id_offset` to whichever fits).
Tab order was also changed to Font & Alignment, Type Test, Resin,
**Gauge**, Build, Layout, Quality, Logo, Element per direct request.

**Progress output during Render.** `generate.py`'s stdout is piped (not a
TTY) when run as a subprocess from `tune.py`'s Render button, so Python
defaults to full block buffering - without explicit `flush=True`,
progress wouldn't appear live in the TUI's log pane at all until the
whole process finished. Added `flush=True` throughout the pipeline's
prints, plus new per-character progress lines in `TextRing()`
(`"TextRing: [n/total] building 'x' (row R, col C)... 0.42s"`) so a ~60s
render shows visible incremental progress instead of a long silent pause.

**Critical fix: struck characters were never mirrored.** User noticed
printed characters were coming out backwards. Root cause: v2's
`TwoDText` wraps every struck glyph in `mirror([1,0,0])` (a struck type
element must carry a mirror image of the printed glyph, the same reason
a rubber stamp or hot-metal slug is cut in reverse) - `build_glyph()`
never did this. Fixed by negating X on the already-shifted contours,
applied AFTER `x_shift` (matching v2's translate-then-mirror order):
`contours_mm = [c * np.array([-1.0, 1.0]) for c in contours_mm]`. This
also mathematically resolved the previously-reported "x offset applied in
the wrong direction" bug as a side effect (verified:
`printed_x = -(-(x_local + x_shift)) = x_local + x_shift`, matching Type
Test's already-correct convention) - both bugs were the same missing
mirror. Deliberately scoped to `build_glyph()` (struck characters) only -
`build_flat_text()` (`LogoText`, Type Test) is untouched, since that text
is read directly and must never be mirrored.

**Draft angle made configurable.** `glyph_poc.py`'s `MINK_DRAFT_ANGLE`/
`DRAFT_HALF_ANGLE_RAD` were fixed module constants with no override.
Added `DEFAULT_DRAFT_ANGLE_DEG` + a `draft_angle_deg` parameter to
`build_glyph()`, threaded through `configure()`/`TextRing`/`Additive`/
`FullElement`/`ResinPrint`, a new `build.draft_angle_deg: 55.0` config
field, a `--draft-angle-deg` CLI flag, and a tuner field on Font &
Alignment (right after the modified-left/right offset fields). Verified
via a direct `build_glyph()` comparison (55° vs 30° producing correctly
different, both-watertight geometry), a save round-trip test, and a full
`generate.py` regression run.

**Investigated but found to already be correct:** a report that "Render
Test Text" wasn't persisting past the Font/Type Test tabs turned out to
already work as intended (the button lives outside `TabbedContent` in the
`#buttons` panel, visible from every tab) - likely a stale-process
artifact on the reporting end, not a real bug; left as-is.

**Explored but not yet started: shared-module split + Postal port.**
Research phase complete - an Explore agent compared `postal.scad` against
`blickensderfer.scad` and confirmed Postal is a strict simplification of
the same cylinder-machine family (same `TextRing`/`LetterPlacement`
radial-wrap scheme, same four shared v2 lib includes); the only
code-level (not just parameter-value) divergence found is the
`HollowSpace`/`DrivePin`/`ResinSupport` "drive pin trio" - Blickensderfer
has 2 selectable drive-pin styles plus a countersink, Postal has one
plain rectangular extrude, no countersink. Everything else differs only
in parameter values (many already config-driven in v4). Design sketched
but not validated or implemented: a new `cylinder_machine.py` shared
module that each machine's `configure()` populates via a globals-dict
sync (`cylinder_machine.__dict__.update({k: v for k, v in g.items() if
not k.startswith("__")})`) so shared functions can call
machine-overridden functions (like `HollowSpace`) as ordinary bare
names - directly mirroring OpenSCAD's own dynamic
redefinition-across-includes behavior. Per this project's established
refactor convention (see memory: build new files, don't edit originals
in place), the plan is `cylinder_machine.py` + `postal.py` as new files
alongside `blickensderfer.py`, not edits to it. Not started.

## 8. Shared-module split + Postal port, implemented

Validated the part-7 design via a Plan agent before writing code (see
that agent's report for the full reasoning) - core verdict: the
globals-sync dispatch mechanism is sound (a function's `__globals__` is a
live reference to its defining module's dict, not a snapshot, so
`cylinder_machine.__dict__.update(...)` really does reproduce OpenSCAD's
"last include wins"), with two refinements: filter the sync to
uppercase-leading keys only (`k[:1].isupper()`, avoiding leaking stray
imports like `np`/`trimesh` into `cylinder_machine`'s namespace - plus one
explicit exception, the lowercase epsilon constant `z`, found the hard
way when `ClipCylinder()` immediately `NameError`'d on first test run),
and an `_active_machine` guard against a future script configuring two
machines in one process (not a real risk today - `generate.py`/
`export_glyphs.py` each configure exactly once and exit; `tune.py` never
imports these modules, only shells out to `generate.py`). The validation
pass also caught a second real code-level divergence the original
research had missed: `BottomSlopedSpace()`'s floor-Z literal is `0` in
Blickensderfer, `-z` in Postal (both files' own comment: "to help with z
fighting") - added as a third machine-set global,
`Bottom_Sloped_Space_Floor_Z`.

**Extraction**: moved everything structurally shared (`Cylinder`,
`ClipCylinder`, `TextRing`, `Additive`, `Core`, `SpeedHoles`,
`BottomSlopedSpace`, `TopMinkCleanup`, `WireBite`, `SecondaryCore`,
`CoreGrooves`, `CoreChamfer(Shape)`, `CoreEllipses`, `LogoText`,
`Subtractive`, `FullElement`, the whole resin-support helper family,
`ResinPrint`, the whole Gauge family) into new `lib/cylinder_machine.py`.
`lib/blickensderfer.py` now holds only `configure()` and its own
`HollowSpace`/`DrivePin`/`ResinSupport` (the countersink versions),
re-exporting `FullElement`/`ResinPrint`/`GaugeTestSet` from
`cylinder_machine` so `generate.py`'s existing `bd.FullElement(...)` etc.
calls needed zero changes.

**Regression-verified the extraction didn't change Blickensderfer's
output at all**: ran `generate.py config/blickensderfer.running.yaml
--no-minkowski --no-core-groove` before the refactor (via `git stash`) and
after - byte-identical vertex/face counts, volume, and watertight/
winding/is_volume flags in both the plain-element and `--gauge` build
paths.

**Postal port**: `lib/postal.py` ports v2/postal.scad's `HollowSpace()`
(plain revolve, no countersink at all), `DrivePin()` (a single centered
box, no sink cylinder unioned on - v2's `DrivePin(Offset)` takes an
unused `Offset` param, dropped in the port since nothing calls it with
one), and `ResinSupport()` (no per-style ternary, plain-pin half-extents).
`config/postal.yaml` populated from `v2/postal.scad`'s own values -
`layout.rows` computed programmatically from v2's
`Keyboard_Layout_Array`/`Element_Layout_Array_Map` (`Physical_Layout`,
postal.scad:271-274) rather than hand-transcribed, to avoid a 28-character
transcription error. Two known placeholders flagged in the config's own
comments: font paths (v2's real Postal fonts, "Alma Mono"/"FreeMono:
style=Bold", are system font family names, not `.ttf` file paths v4
needs - reusing Blickensderfer's font files until real replacements are
sourced) and `quality.body_fn` (v2's Postal uses DIFFERENT Fn values for
`Cylinder()` vs `ClipCylinder()` - `Cyl_Fn`/`Surface_Fn` respectively -
but v4's shared `Body_Fn` knob only has one value; set to Postal's
`Cyl_Fn`, making `Cylinder()` exact and `ClipCylinder()` harmlessly
over-faceted).

Added a `machine:` config key (`generate.py`/`export_glyphs.py` peek it
before import, default `"blickensderfer"` for zero-touch backward compat
with existing configs) and dispatch via `importlib.import_module`.

**Verified end-to-end**: `generate.py config/postal.yaml` (plain element,
`--gauge`, and via `export_glyphs.py`) all produce watertight/
winding-consistent/`is_volume` output with no code errors (one character,
'%', skipped for a missing glyph in the placeholder font - expected, not
a bug). Also directly verified the `_active_machine` guard fires
(`RuntimeError`) when a test script configures Blickensderfer then Postal
in the same process.

**Explicitly out of scope for this pass, flagged as follow-up**:
`tune.py` support for Postal - its `SECTIONS` table is hardcoded to
Blickensderfer's exact field set (e.g. the "Element" tab's
`drive_pin_countersink_depth`/`drive_pin_style`/etc, none of which exist
in Postal's schema) and would `KeyError` immediately if pointed at
`config/postal.yaml`. Needs a per-machine `SECTIONS` variant chosen from
the config's `machine:` key - orthogonal UI work, not started. Sourcing
real Postal font files is also a prerequisite content task, not a code
problem.

## 9. `tune.py` support for Postal

Closed out part 8's flagged follow-up. Split the module-level `SECTIONS`/
`FIELDS`/`LAYOUT_PRESETS` into `SECTIONS_BY_MACHINE`/`LAYOUT_PRESETS_BY_MACHINE`
(Postal's Element field list drops the 5 drive-pin-countersink keys that
don't exist in its config, everything else shared) and made
`TuneApp.SECTIONS`/`.FIELDS`/`.LAYOUT_PRESETS` instance attributes, fixed
once at startup from the launch config's `machine:` key. All method-level
references updated to `self.SECTIONS`/etc (a bulk regex pass, then fixed
a `self.self.` double-prefix bug the regex introduced on the two lines it
was defining, caught immediately via `grep`).

Deliberately scoped to NOT support hot-swapping between machines within
one running session - `compose()` only builds each tab's widgets once, so
a config for a different machine has a structurally different Element tab
(different KEYS, not just different values) that would need real widget
teardown/rebuild, not just repopulation. Added a guard in
`_switch_master_config` that peeks the target config's `machine:` key and
refuses the switch (clear log message pointing at relaunching directly)
if it doesn't match the machine tune.py was launched for.

Fixed `config/postal.yaml` missing a `type_test:` section (tune.py's Type
Test tab unconditionally reads `self.cfg["type_test"]["text"/"cpi"/"lpi"]`
- crashed on first boot test with a real `KeyError`, not a hypothetical
one). Also fixed a real hardcoded-machine-name bug found in the same
pass: `action_save`'s suggested STL filename was always
`f"blickensderfer_{timestamp}.stl"` regardless of which machine was
actually being tuned - now `f"{self.machine}_{timestamp}.stl"`.

Postal's Layout tab has an empty preset dropdown (v2/postal.scad has only
one physical layout, no preset-switching menu like Blickensderfer's 6) -
confirmed Textual's `Select` tolerates a genuinely empty options list
fine (tested directly, no crash) with `allow_blank=True` and a
machine-aware prompt string ("no named presets for this machine" instead
of "custom - not a known preset").

**Verified via headless `App.run_test()` boot tests** (not just visual
screenshots) against both configs: correct per-machine field counts (73
total/32 Element fields for Blickensderfer, 68/27 for Postal), correct
initial values, a save round-trip on a Postal-only-relevant field
(`drive_pin_radial`), and the cross-machine switch guard actually
refusing (confirmed `app.machine` stays `"postal"` and
`app.master_config_path` stays on `postal.yaml` after attempting to
switch to `blickensderfer.yaml`).

**Investigated the Postal font placeholders**: the user's local font
library DOES have real `Alma Mono.otf` and `FreeMono-Bold.otf` files
(found via `find`) - but checking their outlines directly via FreeType's
point tags confirmed both use CFF/cubic curves, not TrueType/quadratic -
exactly the silent-failure case documented in README's "Known
limitations" (`FreeMono-Bold.otf` was literally named there as the
confirmed example). Flagged this to the user rather than silently wiring
in known-broken fonts or guessing a substitute.

## 10. Cubic-curve (CFF/OpenType) outline support

User asked directly: "wait so my thing is not otf support?" - clarified
that OTF is just a container (can hold either TrueType/quadratic `glyf`
outlines, which already worked, or CFF/cubic outlines, which didn't) and
that the real gap was cubic Bezier support in `contour_to_points`
(`lib/glyph_poc.py`), not anything about the `.otf` extension itself.
User asked for the real fix rather than a font substitute.

**Root cause**: `contour_to_points` only checked FreeType's on-curve bit
(`tag & 1`) - every off-curve point was treated as a lone quadratic
control point via the TrueType "implied midpoint" convention. A CFF
outline's off-curve points come in PAIRS (two consecutive cubic control
points before the next on-curve point) - misreading them as quadratic
produced a plausible-looking but geometrically wrong curve, with no error
raised (the exact bug already documented, now actually understood at the
curve-math level instead of just observed as an OTF/TTF divide).

**Fix**: added `cubic_bezier()` (mirrors the existing `quadratic_bezier()`)
and a second per-point classification, `is_cubic = (tag & 0x3) == 2`
(FreeType's `FT_CURVE_TAG` macro - 0=quadratic off-curve, 1=on-curve,
2=cubic off-curve), checked before falling through to the existing
quadratic path. Cubic spans consume 3 points (this control + the
guaranteed-paired second control + the on-curve endpoint) instead of 1-2.

**Verified in layers**: (1) raw contour extraction against real
`Alma Mono.otf` - every character's contours are valid simple polygons
with sane, character-distinct ink dimensions (e.g. 'e' 1.5x1.53mm, 'M'
1.5x2.1mm, '.' 0.43x0.38mm at 3mm font size - not a degenerate
all-identical artifact); (2) full `build_glyph()` through the real
Minkowski pipeline on both the CFF font and a TrueType font side by side -
both watertight/winding-consistent/`is_volume`, different (correct)
per-character bounds; (3) `generate.py config/blickensderfer.running.yaml`
re-run to confirm the TrueType/quadratic path is completely unaffected -
byte-identical vert/face/volume numbers to before this change; (4) the
full `generate.py config/postal.yaml` pipeline (element and `--gauge`,
both fonts - `Alma Mono.otf` for the element, `FreeMono-Bold.otf` for
`LogoText`/`GaugeText`) end-to-end, watertight/winding-consistent/
`is_volume`, 0 characters skipped (previously 1, on the placeholder
font's missing glyph).

`config/postal.yaml`'s font paths were then switched from the TrueType
placeholders to the real `Alma Mono.otf`/`FreeMono-Bold.otf` files, since
the limitation blocking them is now fixed.

## 11. Machine picker on startup + Postal's QWERTY-only layout

User's explicit request: a machine-picker screen shown on startup
(closing out part 9/resuming-item-6's deferred "master GUI"), plus a
"Change Machine" button on the tuner form's status row that returns to
it, and Postal's Layout tab restricted to a single "QWERTY" preset (its
one real physical layout) instead of the empty dropdown from part 9.

**Considered a full Textual `Screen`-stack rewrite** (separate
`MachineSelectScreen`/`TunerScreen` classes, `push_screen`/
`switch_screen`) and rejected it as far more invasive than needed - nearly
every one of `TuneApp`'s ~40 methods reference `self.query_one(...)`,
and moving compose() to a Screen subclass raises real ambiguity about
whether `self.query_one` on the App still resolves against the active
screen's content (untested assumption, not worth risking on a 1200-line
file). Used Textual's `App.recompose()` instead (confirmed available in
the installed 8.2.8 - removes all mounted children and re-runs
`compose()`): `compose()` now branches on `self.machine is None` (picker)
vs. not (the existing tuner form, extracted unchanged into
`_compose_tuner_ui()`), and switching states is just setting
`self.machine`/calling `_load_machine()` then `await self.recompose()`.
Zero changes needed to any of the ~40 existing action/query methods -
they all still just call `self.query_one(...)`, now finding whichever
widgets the current `compose()` branch actually built.

**`_load_machine(config_path)`**: the master/running config bootstrap +
per-machine `SECTIONS`/`FIELDS`/`LAYOUT_PRESETS` setup that used to be
inline in `__init__` (part 9) is now its own method, callable both from
`__init__` (backward-compat direct CLI launch, `python3 tune.py
config/x.yaml` - still supported, skips the picker) and from the new
`_select_machine(machine_key)` (the picker's button handler). `MACHINES`
(new module dict, `{"blickensderfer": (label, config_path), "postal":
(...)}`) is the picker's source of truth and the only place a future
third machine needs to be registered.

**"Change Machine" button**: saves the current form first (reused
`_save_before_exit()` - same courtesy as quitting, so in-progress edits
aren't silently lost on a machine switch), then `self.machine = None;
await self.recompose()` - which is exactly what shows the picker again.
`_switch_master_config`'s existing cross-machine guard (part 9) is now
pointed at this button in its log message instead of "relaunch tune.py",
since there's now a proper in-app path for that.

**Postal's QWERTY preset**: `LAYOUT_PRESETS_POSTAL = {"QWERTY": [...]}`
(the same 3 rows already computed for `config/postal.yaml` from v2's
`Keyboard_Layout_Array`/`Element_Layout_Array_Map` in part 8 - reused
verbatim, not recomputed) replaces part 9's empty `{}` for Postal in
`LAYOUT_PRESETS_BY_MACHINE`. `_compose_layout_tab`'s help text made
properly machine-aware (checks `self.machine` directly now, not just
"are there any presets") since the old "no presets" branch no longer
applies but the Blickensderfer-specific "Ported from
v2/lib/layouts/blick_layouts.scad" text would have been wrong for
Postal's one preset too.

**Verified via headless `App.run_test()` + `pilot.click()`** (clicking
real buttons, not just calling methods directly): picker shows both
machines on a no-arg launch; clicking Postal recomposes into a
Postal-scoped form with the Layout tab's dropdown correctly
auto-selecting "QWERTY" (matches `config/postal.yaml`'s rows exactly, via
the existing `_current_layout_preset()` match-detection); clicking
"Change Machine" returns to the picker; picking Blickensderfer afterward
correctly rebuilds with its own full field set; direct CLI launch still
skips the picker entirely; a save round-trip works correctly on
freshly-recomposed widgets (confirming `self.inputs` isn't holding stale
references from a previous machine's form). Also confirmed visually via
screenshot (converted SVG->PNG with `convert`) - centered picker layout,
correct status text ("machine: Postal | master: config/postal.yaml"), all
three status-row buttons fit on one row.

## 12. Unified `resin.raft` toggle (was a silent per-machine divergence)

User caught a real issue: Postal's resin support didn't look "damn near
identical" to Blickensderfer's like everything else in the shared module -
Postal was growing one big continuous raft plate. Root cause: v2's two
machines genuinely differ here - Blickensderfer's `CutGroove()` ring sits
right at the wall (`Cut_Groove_Inner_X=0`) and each rod grows its own
small raft (`Resin_Rod_Raft=true`); Postal's `Cut_Groove_Inner_X=-14.9`
pushes the ring's inner profile point all the way to the element's center
axis, forming one continuous plate, and its rods grow no individual raft
of their own (`Resin_Rod_Raft=false`) - this was ported faithfully in
part 8, correctly reproducing each machine's real v2 behavior, but never
surfaced as an intentional *choice* - just two silently-diverging
per-machine config defaults.

User's fix, exactly as specified: a single "Continuous raft" checkbox on
the Resin tab - off (now the default for BOTH machines) = Blickensderfer's
original individual-raft behavior, on = Postal's original continuous-plate
behavior - available for EITHER machine now, not Postal-exclusive.

**Implementation**: added `cylinder_machine.resin_raft_config(
element_diameter, wall_min_thickness, raft_enabled)` - a real shared
function (not per-machine copy-paste) that derives both
`Resin_Rod_Raft`/`Cut_Groove_Inner_X` from the one boolean, called from
both `blickensderfer.py` and `postal.py`'s `configure()`. Removed the raw
`resin.rod_raft`/`resin.cut_groove_inner_x` YAML keys entirely (fully
derived now, not independently settable) and replaced with `resin.raft:
false` in both config files - `config/blickensderfer.yaml` and
`config/postal.yaml`'s `resin:` sections are now identical in shape.
tune.py's Resin tab field table (already shared between machines, part 9)
swapped its `cut_groove_inner_x` float field for a `raft` bool field
(automatic `Switch` widget via the existing generic FIELDS mechanism, no
special-casing needed).

**Verified all 4 combinations** (each machine x both settings) via direct
`generate.py --resin-support` runs: Blickensderfer `raft:false` (default)
reproduces the EXACT pre-change `ResinSupport` vert/face counts
(13648/27196); Postal `raft:true` reproduces Postal's exact pre-change
numbers (15851/31698) - confirming the derivation is mathematically
exact, not just visually similar; Postal `raft:false` (new default) and
Blickensderfer `raft:true` (a combination that never existed in v2) both
produce new, watertight/winding-consistent/`is_volume` geometry. Also
verified the new checkbox in tune.py (`Switch` widget, correct initial
value, save round-trip) via headless `App.run_test()`.

**Self-caught mistake**: an early headless test instantiated `TuneApp`
directly against the user's REAL master config paths (`config/
blickensderfer.yaml`) to check the new checkbox's default value, then
saved during the same test - this went through the real master/running
migration + save path and actually flipped `raft: true` in the user's
live, gitignored `config/blickensderfer.running.yaml` scratch file
(their real working config, with real customizations). Caught immediately
by checking `git status`/grepping the file after the test, fixed by hand
(set `raft: false` back, and removed the now-dead migrated-in
`rod_raft`/`cut_groove_inner_x` lines the same migration had left
behind) - the user's actual settings were otherwise untouched. Lesson for
future headless tests that exercise save paths: use a scratch copy of a
config, not the user's real master/running files, even for read-only-
seeming checks - `TuneApp.__init__` itself performs a real migration
side-effect on the running file as soon as it's constructed.

## 13. Matched Blickensderfer's and Postal's remaining resin values

Follow-up to part 12's `raft` unification - user asked to go further and
match the actual remaining resin VALUES too, not just the raft toggle.
First pass (wrong direction, corrected same turn): changed `config/
blickensderfer.yaml`'s `min_rod_height`/`raft_od`/`raft_thickness`/
`bottom_support_fractions`/`bottom_support_inner_angle_offset` to
Postal's values, on the assumption "match A to B" meant "make A become
B" without a stated target. User corrected immediately: "you made it
match up to postal, i wanted blickensderfer to be the standard" -
Blickensderfer's ORIGINAL v2 values are the standard both machines
unify against, not Postal's. Reverted `config/blickensderfer.yaml` back
to its original v2 numbers (`min_rod_height: 4.0`, `raft_od: 2.0`,
`raft_thickness: 1.0`, `bottom_support_fractions: [0.2]`,
`bottom_support_inner_angle_offset: 0.5`) and instead changed `config/
postal.yaml`'s values to match THOSE. The two files' `resin:` sections
are still byte-identical when parsed (`yaml.safe_load(...)['resin'] ==`
the other's) - just anchored to the opposite machine's original numbers
than the first pass.

Regression-verified both directions against the master config files
directly (not the user's real running copies - see part 12's lesson,
applied both times): fully watertight/winding-consistent/`is_volume` in
both passes. Final state's `ResinSupport` counts: Blickensderfer
13648/27196 (exactly its original pre-any-of-this-session's-changes
number, confirming the revert is exact), Postal 13719/27322 (now close
to Blickensderfer's, small remaining gap expected from the two machines'
different `Element_Diameter`/`Wall_Min_Thickness`/etc, not a bug).

## Resuming later

1. **Reapply or re-decide on `separation_mm=1.0`** (see "Where things
   stood" above) - `logo.radial_offset_mm` is back (part 6), but
   `separation_mm` is still the reverted `2.0`, still 61 collisions.
2. **Inter-character collisions** (61 at `separation_mm=2.0`) - no
   automatic fix short of redoing placement/size, or accepting the
   `separation_mm=1.0` tradeoff (verified to eliminate them, at the cost
   of embedding-depth margin).
3. **Performance** - if ~60-70s at full quality becomes annoying,
   `points_per_mm`/`quality.minkowski_fn` are the main levers, or
   `build.minkowski_enabled: false` for a ~3s undrafted preview - all
   wired through config + CLI (`--no-minkowski`).
4. Alignment offsets - the mechanism is built and now in real use (see
   the running config's `modified_left_offset_mm`/
   `modified_right_offset_mm`), but the base `center_offset_mm`/
   `left_offset_mm` knobs are still untouched at their 0.0 defaults.
5. `platen_fn`/`body_fn` are both set to 360 right now (per earlier
   direction, "may both be set at 360") - 720 was floated for `platen_fn`
   if the scallop needs to be smoother; not tested.

## 14. Roadmap: branch merged to main, next is Calibration then Mignon/Bennett/Helios

`v4-tui` was fast-forward merged into `main` and pushed (40 commits,
clean linear history, no divergence). New branch `v4-models` created off
`main` for the next phase: user's stated order is Mignon next (should
reuse a lot from `cylinder_machine.py`), then Bennett, then Helios (both
also cylinder-machine-family) - but the **Calibration feature** needs to
land FIRST, before diving into more machine ports, since every future
machine will want it too.

**Explicitly NOT started yet** - user is about to run out of credits,
asked for a plan only, will say "start" when ready to resume. This
section is that plan, written here specifically so it survives a
context/credit gap.

### What "Calibration" actually is (traced from v2, not guessed)

`v2/lib/testing.scad` (`testSweepArray(start, interval, count)` - a
trivial linear sweep, `[start + interval*n for n in 0..count-1]`) +
`v2/lib/glyph_pipeline.scad`'s `TextRing()`/`TextRingDebug()` (~line
407-451) implement a real, already-designed mechanism, not something to
invent from scratch:

- `Test_Layout` (bool): every position renders the same `Test_Char`
  instead of the real per-position character.
- `Cutout_Test` / `Baseline_Test` (bool, independent - test one variable
  at a time in practice): when on, adds a PER-COLUMN swept offset
  (`Cutout_Test_Array[col]` / `Baseline_Test_Array[col]`, each a 28-long
  `testSweepArray(start, interval, 28)`) onto that row's platen-cutout or
  character-baseline value - so each of the 28 physical positions around
  the ring gets a DIFFERENT offset of whichever variable is under test.
- Whenever any of the three is on, `TextRingDebug()` echoes one line per
  position: `"character keyboard key 'k' (rendered as 'X') on lowercase
  row at the 7 oclock position with platen cutout at 0.15mm and character
  baseline at 0mm"` - refChar (the real keyboard key physically at that
  slot) vs char (what's actually rendered, `Test_Char` under
  `Test_Layout`) are tracked separately for exactly this reason.
- Blickensderfer/Postal both default `Cutout_Test_Start=0`/
  `Cutout_Test_Int=.05` (Blick) or `.7`/`-.05` (Postal) - `testing.scad`'s
  own comment notes Bennett/Mignon/Helios/Hammond use a fixed literal
  offset array instead of a uniform sweep for this, since they already
  have measured values - not a blocker for v4's first pass (a uniform
  start+interval sweep, matching what the user asked for: "specified
  intervals of adjustment").

### v4 implementation shape (design, not yet built)

- **Shared, not per-machine**: `TextRing`/placement already live in
  `lib/cylinder_machine.py` (see part 8) - a `CalibrationElement()`-style
  function belongs there too, so it's automatically available to
  Mignon/Bennett/Helios the moment they're configured, not something
  reimplemented per machine.
- **Config**: new `calibration:` section (parallel to the existing
  `gauge:` section) - `test_char` (str), `variable` ("baseline" |
  "cutout"), `start` (float), `interval` (float). Both
  `config/blickensderfer.yaml` and `config/postal.yaml` need it added
  (shared schema, like `resin:`/`gauge:` already are).
- **Build dispatch**: extends the existing Build tab pattern (Element /
  Shaft Gauge) with a third option, Calibration - mirrors how Gauge was
  added (part 8's `GaugeTestSet`/`--gauge` precedent): a
  `--calibrate` flag on `generate.py`, a `CalibrationTextRing()` (or a
  `test_layout`/`test_variable` kwarg threaded through the existing
  `TextRing()`) that applies the swept per-column offset and forces
  `Test_Char` everywhere.
- **Console output**: reuse the already-established
  `print(..., flush=True)` pattern (part 7/8) - one line per position,
  same content as v2's `TextRingDebug` echo (keyboard key, row label,
  o'clock position, the actual cutout/baseline value used at that
  position).
- **tune.py**: new "Calibration" tab (test char field, a variable
  dropdown "baseline"/"cutout", start/interval fields) - added to
  `SECTIONS_COMMON` (shared between machines, like Resin/Gauge already
  are) so it's free for every future machine too. Build tab's dropdown
  gains "Calibration" as a third option.
- **Saved `.txt` mapping**: user's explicit ask - "when saving a test
  element, it also outputs a .txt of the keyboard mapping to set
  variable." `action_save()` (tune.py) already writes an STL + a `.yaml`
  sidecar per save (see the module docstring's Save explanation) - add a
  third sidecar, a `.txt` with the same per-position lines the console
  already printed, when `self._last_build_info["kind"] == "calibration"`
  (mirrors the existing `_last_build_info` tracking used for the STL/YAML
  metadata header).
- **No new "reference layout" abstraction needed** - v2's
  `Reference_Physical_Layout` (a keyboard-key-labels-vs-content-layout
  split, used by Blickensderfer/Bennett/Mignon for language/layout
  testing) has no v4 equivalent yet and isn't needed for a first pass -
  the "keyboard key at this position" in the console/`.txt` output can
  just be whatever `layout.rows`/`DHIATENSOR` currently has configured at
  that row/col (same source TextRing already reads), matching what
  Postal/Helios/Hammond do in v2 anyway (no reference override - refChar
  == char's position source).

### After Calibration lands

Mignon, then Bennett, then Helios, each following the extraction
playbook already proven twice (part 8's Blickensderfer/Postal split,
part 9's tune.py per-machine SECTIONS, part 12/13's shared resin
config) - read the real v2 file, diff it against `cylinder_machine.py`'s
existing shared functions to find genuine code-level divergences (not
just parameter values, per part 8's methodology), port only the
machine-specific pieces, add `config/<machine>.yaml`, regression-verify
against the master configs directly (not the user's running copies - see
part 12's lesson).

## 15. Calibration feature implemented (per part 14's plan)

User said "start plan" - implemented part 14's design as written, no
deviations from the mechanism (v2's `Cutout_Test`/`Baseline_Test`/
`Test_Layout` traced through `lib/testing.scad` + `lib/glyph_pipeline.
scad`'s `TextRing`/`TextRingDebug`).

**`lib/cylinder_machine.py`** (shared, per part 14's reasoning - free for
Mignon/Bennett/Helios later): `place_on_cylinder()` gained an optional
`baseline_mm=None` param (overrides `BASELINE_ROW[row]` when calibrating
that variable; `None`, every other caller, preserves the exact prior
behavior - zero risk to the real element path). New
`CalibrationTextRing()`/`CalibrationAdditive()`/`CalibrationElement()`
(mirroring `TextRing`/`Additive`/`FullElement`'s structure exactly) sweep
`start + interval*col` onto either `Cutout_Row[row]` or `Baseline_Row[row]`
per physical column, force `calibration.test_char` everywhere, and print
one line per position - keyboard key, o'clock-equivalent, and the exact
cutout/baseline values used.

**One deliberate deviation from v2, explained in both the code comment
and README**: the position label uses the REAL physical placement angle
(`PLACEMENT_MAP[col]` * `LATITUDE_INT`, matching `place_on_cylinder`'s own
angle formula) instead of v2's raw content-order `col`. Traced why: v2's
`TextRingDebug` computes o'clock from the loop's raw `col` (content-order
index into `Physical_Layout`), which only equals the true physical
position for machines with an IDENTITY `Placement_Map` (Postal - "no
Placement_Map override... the lib defaults Placement_Map to identity").
Blickensderfer's real `placement_map` is NOT identity
(`[13,12,11,...]`), so porting v2's formula literally would have
mislabeled every position for Blickensderfer specifically - decided this
was worth deviating on (with the reasoning documented) rather than
faithfully reproducing what looks like a latent v2 quirk.

**Config**: new `calibration:` section (`test_char: "X"`,
`variable: "cutout"`, `start: 0.0`, `interval: 0.05`) added to both
`config/blickensderfer.yaml` and `config/postal.yaml` identically (shared
schema, matching `gauge:`/`resin:`).

**`generate.py`**: `--calibrate` flag (+ `--calibration-char`/
`-variable`/`-start`/`-interval` overrides), mirrors `--gauge`'s
early-return structure. Writes the STL, then a `<stem>_mapping.txt`
sidecar with the same per-position lines the console printed - the
user's explicit ask ("when saving a test element, it also outputs a .txt
of the keyboard mapping").

**`tune.py`**: new shared "Calibration" tab (`test_char` input,
`variable` dropdown - added as a second special-cased Select alongside
the existing `mode` one, `start`/`interval` inputs), Build tab dropdown
gained a third "Calibration" option, `_run_build` dispatches `--calibrate`
(Minkowski forced the same way as a normal element build, since
Calibration DOES go through the real draft/placement pipeline unlike
Gauge). `action_save` now copies the `_mapping.txt` sidecar alongside the
saved STL too, gated on `self._last_build_info.get("target") ==
"calibration"` (reusing the existing `_last_build_info` tracking, same
pattern as the `.yaml` metadata sidecar).

**Verified thoroughly, at every layer**: direct `generate.py --calibrate`
on both machines (Blickensderfer default cutout-sweep AND Postal with
`--calibration-variable baseline`) - all 84 positions built, fully
watertight/winding-consistent/`is_volume`, `.txt` sidecar content spot-
checked (clean, correctly formatted, matches console output exactly).
Headless `tune.py` tests against SCRATCH COPIES of the configs (not the
user's real master/running files - part 12's lesson applied from the
start this time): Calibration tab fields/values, Build dropdown's third
option, a full save round-trip, AND the complete `_run_build` worker path
(real subprocess `generate.py` invocation via the Preview button) -
confirmed the STL and mapping `.txt` both get written and
`_last_build_info["target"] == "calibration"` is set correctly for
`action_save`'s new logic to key off.

## Resuming later

1. **Mignon, then Bennett, then Helios** - see part 14's extraction
   playbook. Calibration (this part) is done, so all three get it for
   free via `cylinder_machine.py`.
2. Everything in part 14's own original "Resuming later" list (the
   pre-existing backlog: `separation_mm`, inter-character collisions,
   performance, alignment offsets, `platen_fn`/`body_fn`) is still
   open - unrelated to Calibration, not touched this pass.

## 16. Two Calibration follow-up fixes from real usage

**Bug: Calibration Element ignored `--minkowski`/`--no-minkowski`.**
User: "right now, pressing preview renders it with minkowski." Root
cause: `generate.py`'s `--calibrate` branch parsed
`--minkowski`/`--no-minkowski` (and every other build-quality flag -
`--points-per-mm`/`--separation-mm`/`--cone-segments`/
`--simplify-tolerance-mm`/`--platen-fn`/`--draft-angle-deg`) but never
actually passed any of them to `CalibrationElement()` - so tune.py's
Preview button (which sends `--no-minkowski`) had zero effect; every
calibration build silently used the config's default (minkowski on),
the same ~36s path as Render regardless of which button was pressed.
Fixed by threading all of them through, matching the normal
`build_fn(...)` call exactly. Confirmed: `--no-minkowski` now takes
~1.4s (was ~36s regardless of the flag before the fix) - verified both
via direct CLI timing AND through `tune.py`'s actual `_run_build` worker
path (a real subprocess call, not just unit-testing the arg parsing).
Also renamed the Build tab's "Calibration" dropdown option to
"Calibration Element" (all UI text/docstrings quoting the old label
updated to match).

**Redesign: `calibration.variable` (single baseline-or-cutout choice)
replaced with two independent checkboxes.** User: "have checkboxes for
vary baselines, and vary cutouts. usually youll only have 1 checked at a
time." This is actually a MORE faithful port of v2 than the original
single-choice design - v2's `Cutout_Test`/`Baseline_Test` really are two
separate booleans (confirmed by re-reading part 14's own research), not
a single enum; the original single-`variable` implementation was an
unnecessary simplification. Replaced `calibration.variable: "cutout"`
with `calibration.vary_baseline: false`/`vary_cutout: true` (same net
default) in both config files, in `CalibrationTextRing`/`Additive`/
`Element`'s signatures (`vary_baseline`/`vary_cutout` bools instead of a
`variable` string), in both machines' `configure()`, and in
`generate.py`'s CLI (`--calibration-vary-baseline`/
`--calibration-no-vary-baseline` + the `-cutout` pair, mirroring the
`--minkowski`/`--no-minkowski` tri-state pattern). tune.py's Calibration
tab: the `variable` field's Select special-case removed entirely (two
plain `bool` fields get `Switch` widgets automatically via the existing
generic FIELDS mechanism - no special-casing needed, simpler than what
it replaced). Both CAN be checked together (moves baseline and cutout by
the same shared offset simultaneously) or both off (no sweep, every
position identical) - not just the "usually 1" case, though that's still
the expected normal usage the user described.

Verified all four on/off combinations (default cutout-only, baseline-only
override, both-on, both-off) via direct `generate.py --calibrate` runs -
all watertight/winding-consistent/`is_volume`, `.txt` mapping output
spot-checked to confirm baseline/cutout values actually move independently
per combination (both-on: both columns' values change together;
both-off: cutout stays pinned to its row's fixed value across every
column). tune.py's two `Switch` widgets verified via headless test
against a scratch config (not the user's real files) - correct initial
values, save round-trip.

## 17. `layout.baseline_row`/`cutout_row` exposed on the Element tab

User asked why calibration's cutout/baseline values print negative -
explained the coordinate convention (these arrays are "distance below the
clip end," not absolute Z - `place_on_cylinder`'s
`BASELINE_Z_OFFSET (=Element_Height) + baseline_mm` is what converts them
into an absolute position; the console/`.txt` output deliberately mirrors
the raw config value so it can be pasted straight back in). Immediate
follow-up: "missing the values to place baselines and cutouts in the
Element tab" - the whole point of Calibration is finding a number to dial
in, and there was no dial to turn without hand-editing the YAML.

`layout.baseline_row`/`cutout_row` are 3-element inline numeric arrays
(one per row) - list-valued, so they never fit the generic FIELDS
mechanism's one-scalar-per-key assumption (same reason `layout.rows`
needed its own bespoke block-list patcher back in the original tune.py
build-out). Added a matching bespoke mechanism for INLINE (not block)
lists: `patch_yaml_list_item(text, key, index, value)` - regex-matches
`key: [...]`, splits on commas, replaces just the one element, rejoins -
leaves everything else in the file untouched, same "surgical patch, not a
round-tripped YAML dump" philosophy the other patchers already use.

6 new bespoke `Input` fields (`baseline_row_0/1/2`, `cutout_row_0/1/2`,
labeled "Baseline row 0 (lowercase)" etc.) appended to the bottom of the
Element tab specifically (`_compose_section_tab` calls
`_compose_baseline_cutout_fields()` when `section == "Element"`) - not
folded into `SECTIONS_COMMON["Element"]` since they need
`patch_yaml_list_item` instead of `patch_yaml_value`, same reasoning
`BASELINE_CUTOUT_KEYS` (a module-level set of their 6 `self.inputs` keys)
exists for: `_collect_values`/`_save_to_yaml` both check membership to
route them to the list-item patcher instead of the generic scalar one,
and `_refresh_widgets_from_cfg` repopulates them explicitly (same pattern
Layout's custom rows and Type Test's fields already use for their own
bespoke widgets).

Verified: `patch_yaml_list_item` unit-tested directly against a
representative YAML snippet (patches only the targeted index, leaves
surrounding keys/formatting untouched); full headless round-trip against
a scratch config (initial values populate correctly, edit+save persists
correctly, a genuinely invalid value is rejected with an error log and
`None` return, matching every other field's error-handling convention);
visually confirmed via screenshot (renders cleanly at the bottom of the
scrollable Element tab, correct labels/values); `generate.py`'s normal
build path re-confirmed unaffected (byte-identical `ResinPrint` output).

## 18. Fixed Calibration's reference sourcing (was a real moving-target bug) + sweep defaults

User: "what is the reference baseline/cutout, is it sourced from the
running config, or default/master config - we would want to use a fixed
value, probably master because if we change config and use that as
reference, we could be chasing a value that is always changing after we
updated our config." Checked: `CalibrationTextRing` used the module
globals `BASELINE_ROW`/`CUTOUT_ROW`, set by `configure()` from whatever
config the process was given - for a real tune.py Preview/Render, that's
`self.config_path`, the RUNNING copy. Combined with part 17's new Element
tab fields (which write to that same running copy), this was a genuine
bug the user caught before it bit anyone: dial in a value from one
calibration pass, hit Preview again, and the sweep would silently
re-center on your just-saved edit instead of staying anchored - each
pass chasing the previous one's result instead of converging on a fixed
target.

**Fix**: `CalibrationTextRing`/`Additive`/`Element` gained
`reference_baseline_row`/`reference_cutout_row` parameters, defaulting to
the `BASELINE_ROW`/`CUTOUT_ROW` globals when not given (preserves exact
prior behavior for direct/CLI callers with no override). New
`generate.py --calibration-reference-config PATH` flag loads
`layout.baseline_row`/`cutout_row` from a SEPARATE file and passes them
in explicitly; `tune.py`'s `_run_build` always passes
`self.master_config_path` here for calibration builds. Also added a
summary print at the start of every `CalibrationTextRing` run
(`test_char=... vary_baseline=... vary_cutout=... start=...mm
interval=...mm - reference baseline_row=[...] cutout_row=[...]`) so which
reference is actually in effect is never ambiguous from the log - this
was as much the user's real question ("what is the reference... sourced
from") as it was a bug report, so making it visible closes the loop
properly instead of just fixing the code silently.

**Verified the fix is real, not just plausible**: built a scratch
"running" config with `baseline_row[0]` hand-edited to `-4.5` (simulating
an already-dialed-in value) against the real unmodified master
(`baseline_row[0]=-4`) - confirmed via direct CLI that
`--calibration-reference-config <master>` reports `reference
baseline_row=[-4, ...]` and produces `baseline=-4.7mm` at column 0
(`-4 + start(-0.7)`), NOT `-5.2mm` (what `-4.5 + -0.7` would give);
confirmed the opposite (no reference flag) correctly falls back to
whatever config was passed, for backward compat. Then reproduced the
exact real-world scenario end-to-end through `tune.py`'s actual
`_run_build` worker (real subprocess, scratch config, not the user's
real files): set `baseline_row_0` to `-4.5` via the Element tab widget,
ran Preview (which saves the running copy first, confirmed via `grep` -
the running file really did get `-4.5`), and the resulting `.txt` mapping
still showed `baseline=-4.0000mm` at column 0 (master's original,
untouched value) - the moving-target bug is gone.

**Sweep default changed**: user also asked for `calibration.start`'s
default to be `-0.7` (was `0.0`) "so we tet above and below the set
reference" - `0.0` only ever swept upward from the reference (0 to
`+interval*27`); `-0.7` (interval unchanged at `0.05`) now spans -0.7mm
to +0.65mm across the 28 columns, testing both directions. Changed in
both config files and both machines' `configure()` fallback defaults.

## 19. Mignon ported (first non-"cylinder machine")

User: "lets proceed with the roadmap. the next elements. slightly
different in that theres no gauge for them but there is calibration."
Dispatched an Explore agent for the same function-by-function comparison
methodology used for Postal (part 8) - the result was a much bigger
divergence than expected: unlike Postal (one drive-pin-trio difference),
**Mignon shares almost nothing structural with `cylinder_machine.py`** -
only the glyph placement pipeline (`TextRing`) and the Calibration
mechanism are genuinely reusable as-is. Confirmed directly from
`v2/mignon.scad`: no `Core`/`ClipCylinder`/`WireBite`/`SpeedHoles`/
`core_shaft.scad` family at all (plain `rotate_extrude()` shaft bore), a
12-sided polygon body instead of round, a stepped-boss+chamfer top
instead of a wire clip, a plain cut-through alignment keyway instead of a
countersunk drive pin, top+bottom Minkowski cleanup instead of top-only,
and fully bespoke resin-support placement (raft ring + rods at two radii,
none of `CutGroove`/`SpeedHoleSupport`/`DrivePinSupport`/
`BottomSupports`). Also: 7 physical rows/12 columns, not 3/28 - and no
Shaft Gauge Test at all (confirmed via `v2/mignon.scad:30`'s own comment,
also true for Bennett/Helios Klimax per their own files).

**Two shared, backward-compatible `cylinder_machine.py` changes** (both
regression-verified byte-identical against Blickensderfer/Postal):
1. `TextRing`/`CalibrationTextRing`'s hardcoded `for row in (0,1,2):` ->
   `range(len(DHIATENSOR))` - Mignon's 7-row `Baseline_Regular`/`Cutout`
   arrays needed this; reduces to the identical 3-row loop for the
   existing machines' configs.
2. `place_on_cylinder()` gained optional `placement_protrusion`/
   `angle_half_step` params (`None` = the exact prior hardcoded
   `Char_Protrusion`/`0.5` behavior) - v2's own documented optional-
   override mechanism (`lib/glyph_pipeline.scad`'s
   `Letter_Placement_Protrusion`/`Angle_Half_Step`, already designed for
   exactly this - Bennett/Mignon/Helios override both to 0). Verified
   `build_glyph()` itself needs NO Mignon-specific changes -
   `Letter_Extrude_Offset`/`Letter_Extrude_Depth` (v2's manual per-vertex
   depth tuning) have no v4 equivalent, since v4's real-Minkowski-sum
   architecture already auto-computes margin per-glyph.

**`lib/mignon.py`** (~380 lines, new file) reimplements the rest locally:
`PolygonCylinder`/`ElementChamfer`/`ElementLabel`/`MinkCleanup`/
`CenterShaft`/`HollowBody`/`AlignmentPin`/`ResinSupport`, plus its own
`Additive`/`FullElement`/`ResinPrint`/`CalibrationAdditive`/
`CalibrationElement` (can't reuse `cylinder_machine.CalibrationElement` -
it unconditionally builds `Cylinder()+ClipCylinder()`, which would crash
outright on Mignon's missing `Body_Fn`/`Clip_OD` globals). `ElementLabel`
reuses the same "flat, non-drafted" simplification `LogoText()` already
established for Blickensderfer/Postal's logo (v2's real version gets a
small sphere-minkowski rounding, cosmetic only, not the big draft-cone
struck characters get) - explicitly flagged as a known simplification,
not silently. `ResinPrint()` faithfully ports a genuine v2 quirk that
looked surprising at first: it FLIPS the whole element upside-down before
adding supports (`translate([0,0,Element_Height]) rotate([0,180,0])`,
`v2/mignon.scad:438-439`) - the label/chamfer end ends up facing the
build plate, the shaft/mechanical end faces away from supports.

`config/mignon.yaml`: real font found locally (`Iosevka Etoile.ttf` -
already genuine TrueType, no cubic-curve concern). Physical layout
(German 4 / `Layouts[5]`, 7 rows x 12 columns) computed programmatically
from `v2/lib/layouts/mignon_layouts.scad`'s `DEUTSCH4` array through
`Char_Legend`'s remap, same as Postal's `layout.rows` derivation - not
hand-transcribed. `resin.support_height`/`support_thickness` and several
`element:` keys are Mignon-only, not shared with Blickensderfer/Postal's
schema.

**`generate.py`**: the `HollowSpace()` character-root-containment check
was Blickensderfer/Postal-specific (Mignon has no `HollowSpace()` at all -
its hollow-out, `HollowBody()`, is a structurally different taper with no
equivalent diagnostic question) - changed to `if hasattr(bd,
"HollowSpace")` instead of assuming every machine has one.

**`tune.py`**: `SECTIONS_COMMON` trimmed to only the two genuinely-
universal tabs (Font & Alignment, Calibration) - Logo/Quality/Resin
split into `*_BLICKPOSTAL` and `*_MIGNON` variants (Mignon's schemas
diverge in all three, not just Element), and Gauge became fully optional
(`GAUGE_FIELDS`, only in `SECTIONS_BY_MACHINE["blickensderfer"/"postal"]`
- `compose()`'s Gauge tab and `_compose_build_tab()`'s "Shaft Gauge"
dropdown option both check `"Gauge" in self.SECTIONS` now instead of
assuming presence). Added `"mignon"` to `MACHINES`.

**One real bug found and fixed via direct visual verification** (not
just numeric watertight checks - rendered actual screenshots at multiple
angles, since a plausible-but-wrong character/column arrangement can
still be watertight): `v2/mignon.scad:120`'s `Latitude_Int=-360/
len(Layout[0])` is NEGATIVE - missed on the first implementation pass
(copied Blickensderfer/Postal's positive `360/columns` formula
literally). Caught by rendering the built element from multiple angles
and cross-checking against a rigorous, non-visual confirmation: exported
a single isolated glyph ('F') and inspected it from the exact "print
face" viewing direction, confirming `build_glyph()`'s existing struck-
character mirror (verified correct for Blickensderfer earlier this
session, and 100% shared/unchanged code - not something Mignon-specific
config could affect) was working exactly as intended the whole time; the
actually-wrong thing was column wrap direction, fixed by hardcoding the
sign flip in `mignon.py`'s own `configure()` (a real, sourced,
machine-specific value, not a `cylinder_machine.py` change).

**Verified thoroughly**: all 84 positions (7x12) build successfully with
`--no-minkowski` (fast path, ~0.7s) AND `--minkowski` (real full-quality
draft, ~53s) - fully watertight/winding-consistent/`is_volume` in both,
plus the resin-support/flip path and the Calibration path (including
`--calibration-vary-baseline` forcing BOTH sweep variables on
simultaneously). Visually confirmed via multiple `f3d` renders (isolated
single-glyph, plain element, full `ResinPrint` with supports) - real
12-sided body, correctly placed/legible-when-struck characters, working
resin support raft+rods. `tune.py` regression-verified for both existing
machines (identical field counts to before: 78/73 total fields including
Calibration's 5, matching the pre-restructuring 73/68 + 5 exactly) and
newly verified for Mignon (50 fields, no Gauge tab mounted, correct
Element/Resin values, save round-trip) via headless `App.run_test()`
against scratch config copies throughout - never the user's real files.
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

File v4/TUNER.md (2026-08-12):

# Interactive tuner (`tune.py`)

Split out of `README.md` to keep it direct - see
[`README.md`](README.md) for setup, usage and the machine list.

## Interactive tuner (`tune.py`)

```
python3 tune.py                              # machine picker first
python3 tune.py config/blickensderfer.yaml   # skip the picker, load directly
```

A `textual` TUI for iterating on the config without hand-editing YAML or
re-running the CLI. Sections are listed down the left-hand side of the
form - **Font & Alignment**, **Type Test**, **Resin**, **Gauge**,
**Build**, **Font Coverage**, **Layout**, **Quality**, **Logo**,
**Element** (the last flagged as advanced - core geometry, not usually
touched), plus whichever of **Character**, **Ticks**, **Calibration**,
**Label**, **Rib** and **Legend** the loaded machine has. Click one, or
arrow through the list, to switch. Every section a machine has is visible
at once; the list is a vertical column rather than a row of tabs because
a machine can have up to 14 of them, and a horizontal bar showed about
five with no hint the rest existed.

A persistent **RENDER TEST TEXT** button (below the sections, always
visible) launches/raises `f3d` in orthographic Top View
(`f3d_top_view_cmds.txt`, `set_camera top` - reverse-engineered from
`libf3d.so`'s own command strings after a hand-derived
`--camera-direction` guess came out rotated 90°) to preview the flat
Type Test text.
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

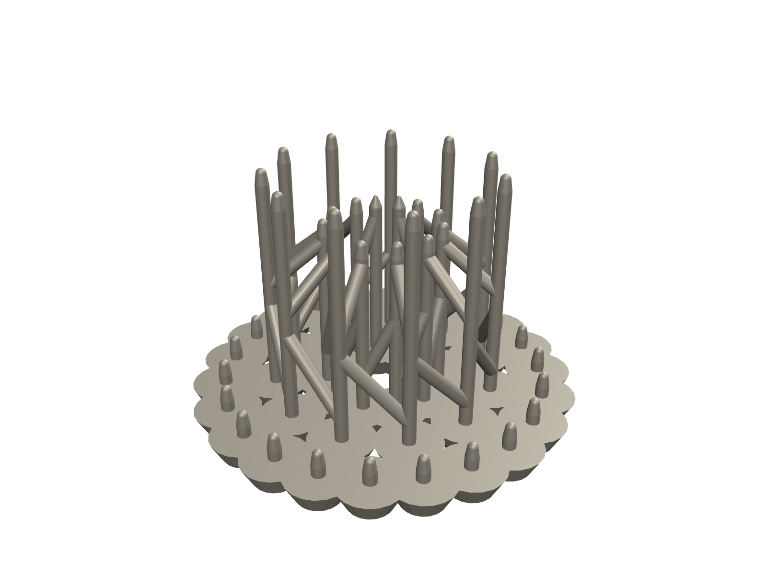
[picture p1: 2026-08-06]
v4/site/assets/thumbnails/resin_support_renders/selectric12_supports.png

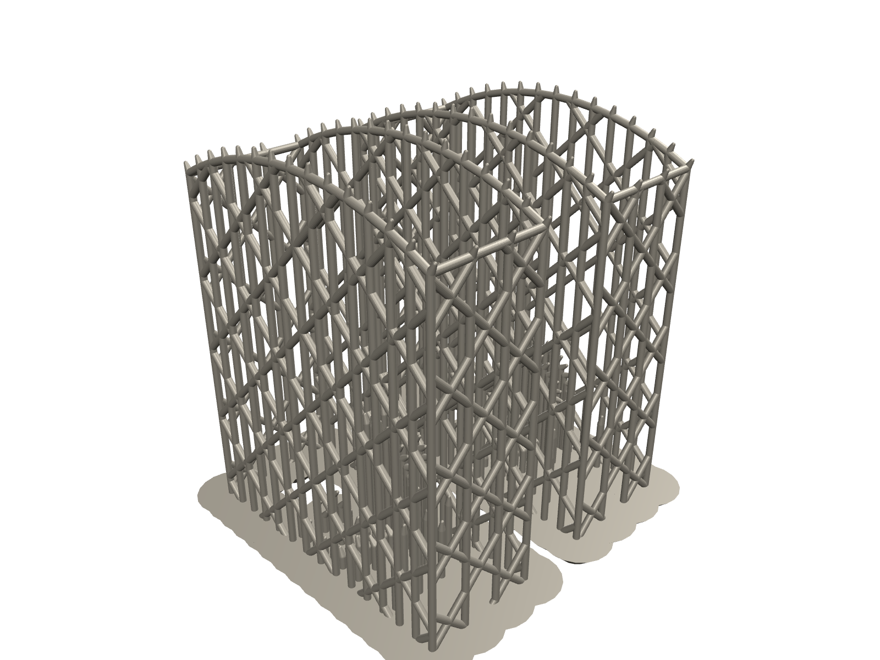
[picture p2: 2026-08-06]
v4/site/assets/thumbnails/resin_support_renders/hammond_split_supports.png

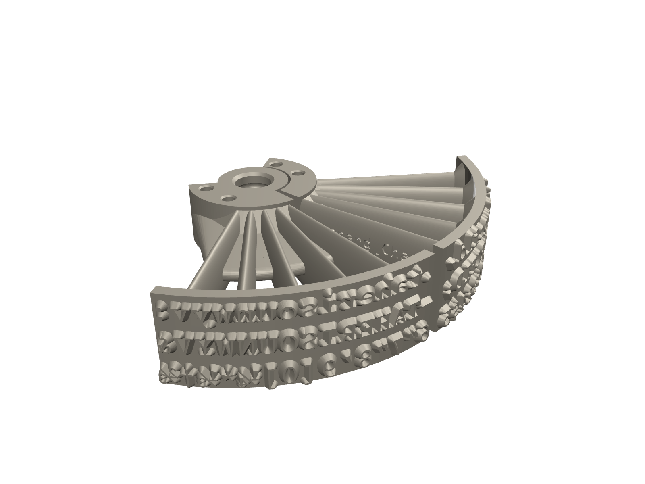
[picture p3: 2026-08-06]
v4/site/assets/thumbnails/hammond-split-shuttle.png

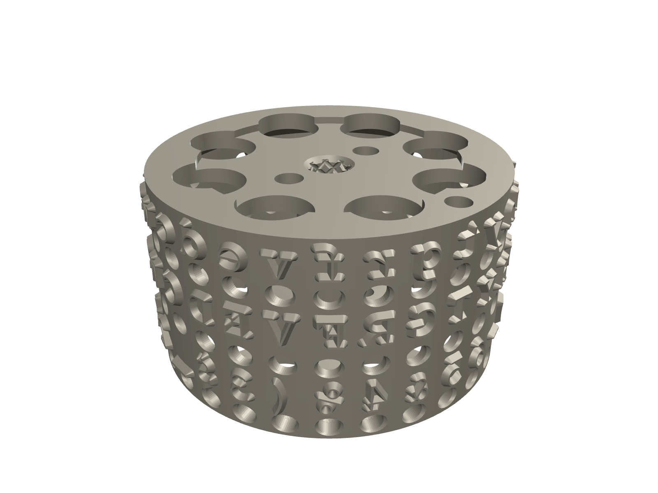
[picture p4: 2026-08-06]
v4/site/assets/thumbnails/bennett.png

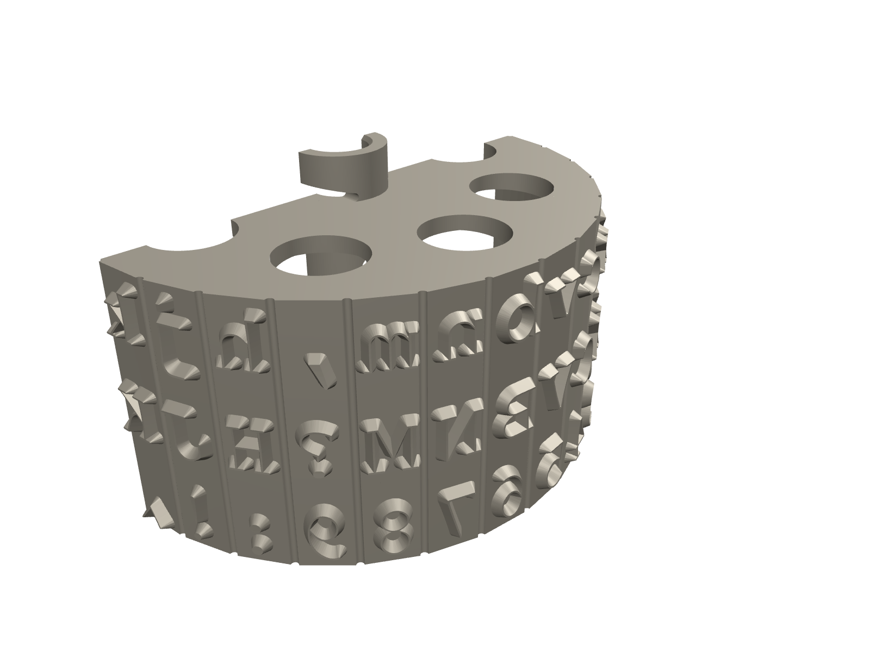
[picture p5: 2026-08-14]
v4/site/assets/thumbnails/blickensderfer_xsection.png

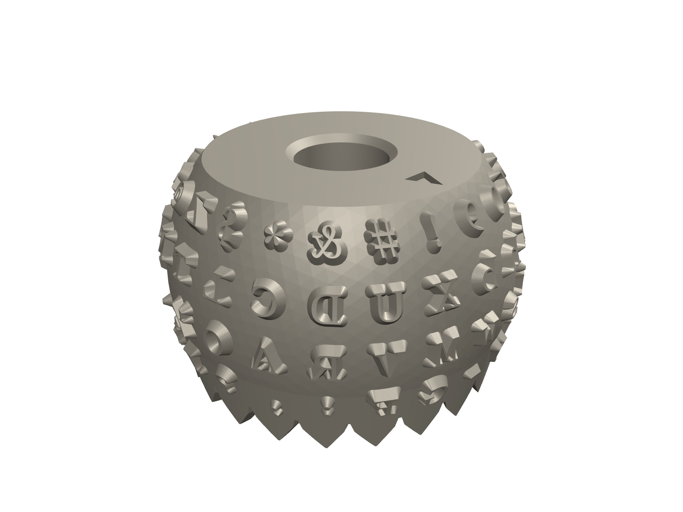
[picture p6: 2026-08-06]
v4/site/assets/thumbnails/selectric-standard.png

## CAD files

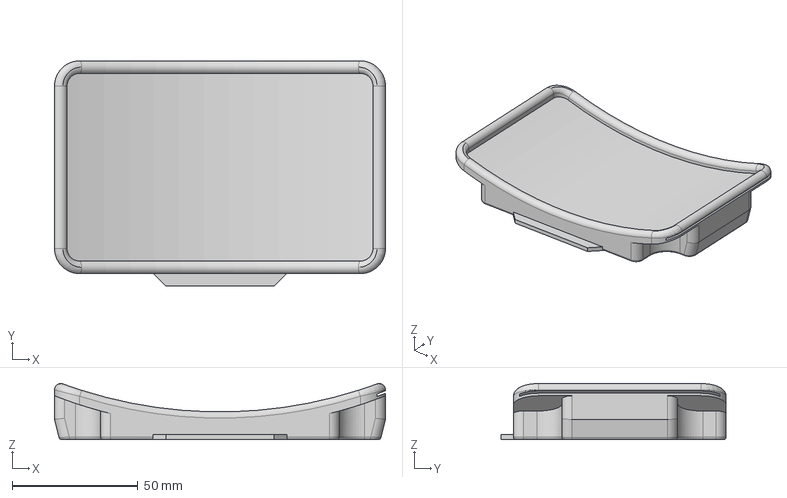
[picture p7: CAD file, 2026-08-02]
v4/docs/mignon_index_holder/Mignon Index Holder v16.stp
131.6 x 89.6 x 22.3 mm

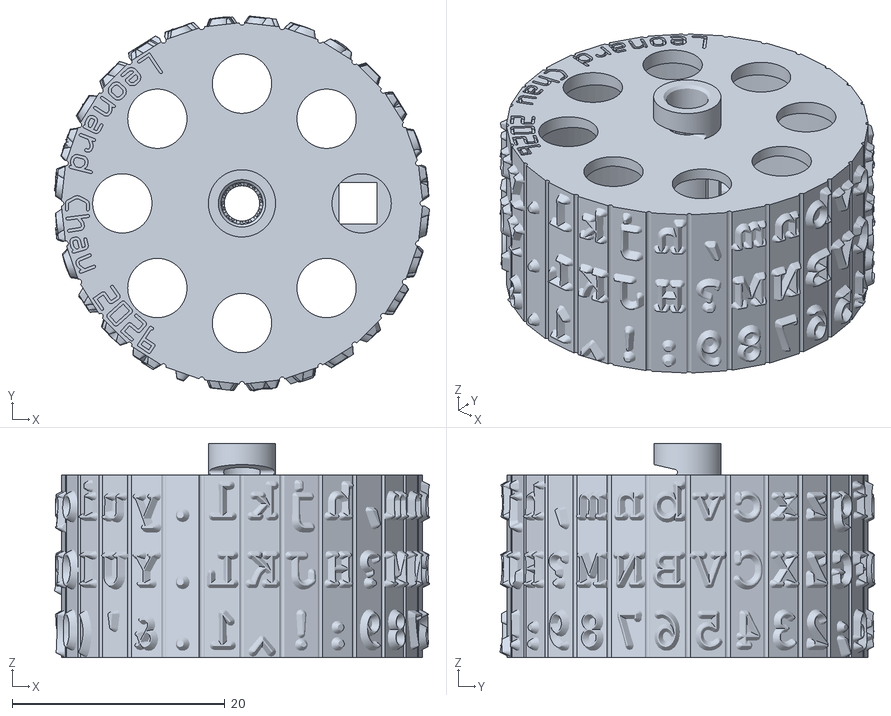
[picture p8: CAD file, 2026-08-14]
v4/example_renders/blickensderfer.stl
35.3 x 35.2 x 20.1

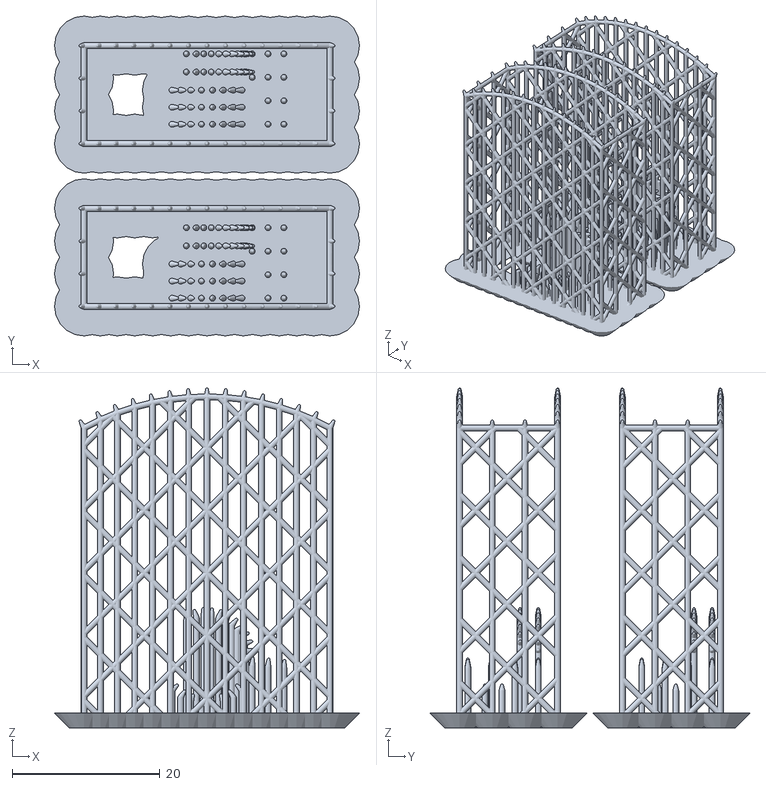
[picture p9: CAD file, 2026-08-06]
v4/example_renders/resin_support_renders/hammond_split_supports.stl
41.3 x 43.3 x 46.0

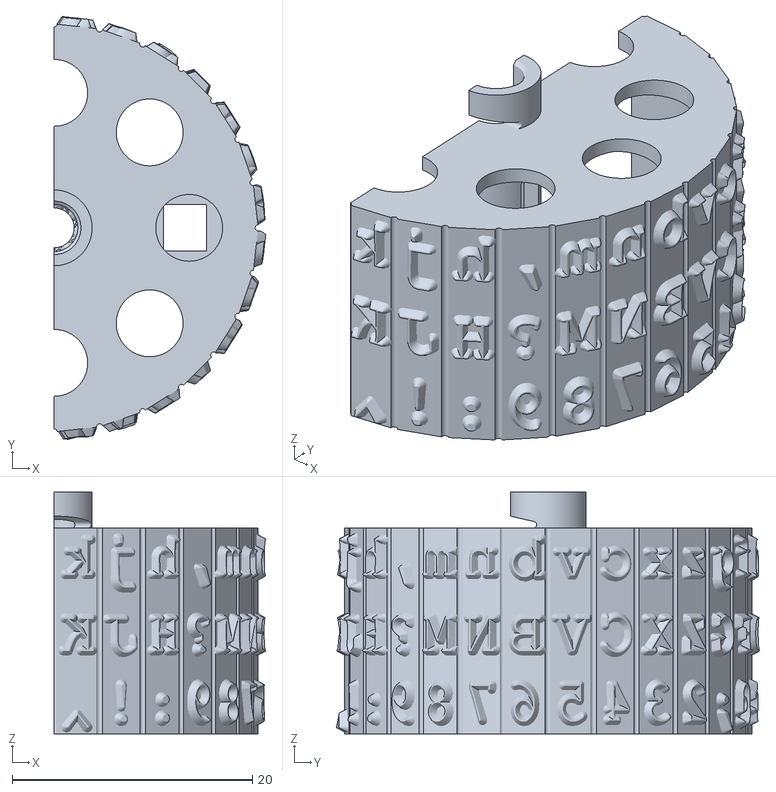
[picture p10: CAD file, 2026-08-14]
v4/example_renders/blickensderfer_xsection.stl
17.6 x 35.2 x 20.1

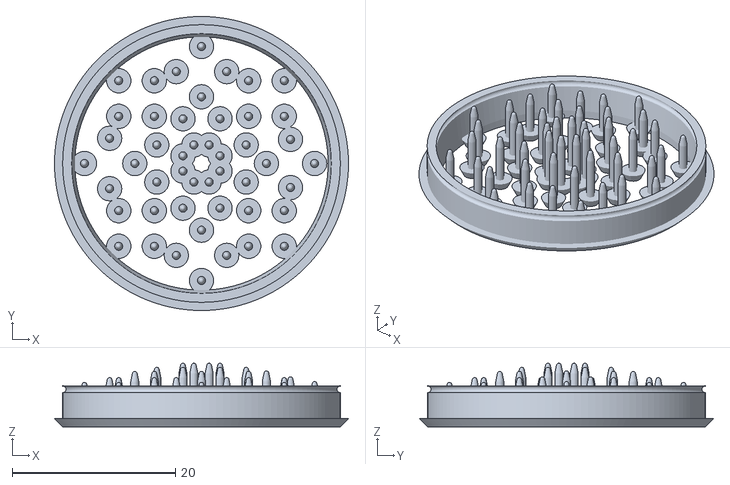
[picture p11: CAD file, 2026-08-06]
v4/example_renders/resin_support_renders/blickensderfer_supports.stl
36.0 x 36.0 x 7.80

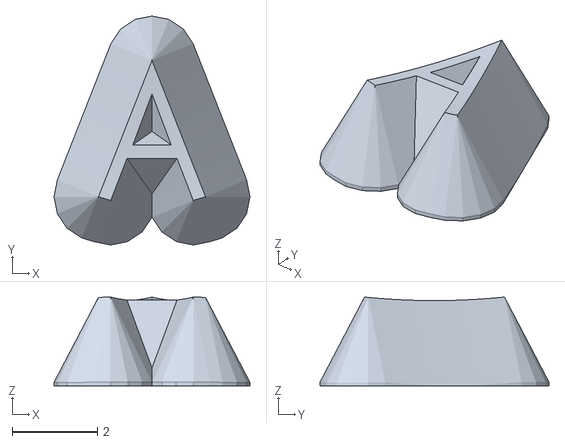
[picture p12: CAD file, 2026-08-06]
v4/example_renders/glyph_A_minkowski.stl
4.59 x 5.36 x 2.08

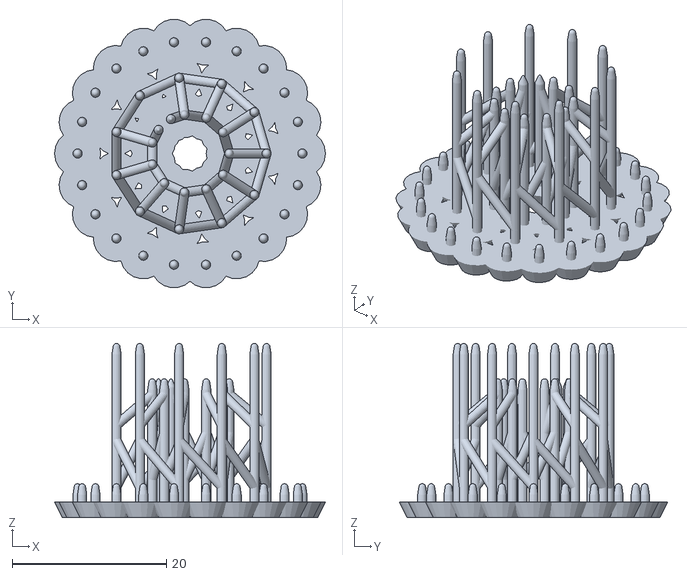
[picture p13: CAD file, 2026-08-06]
v4/example_renders/resin_support_renders/selectric12_supports.stl
35.2 x 34.8 x 22.6

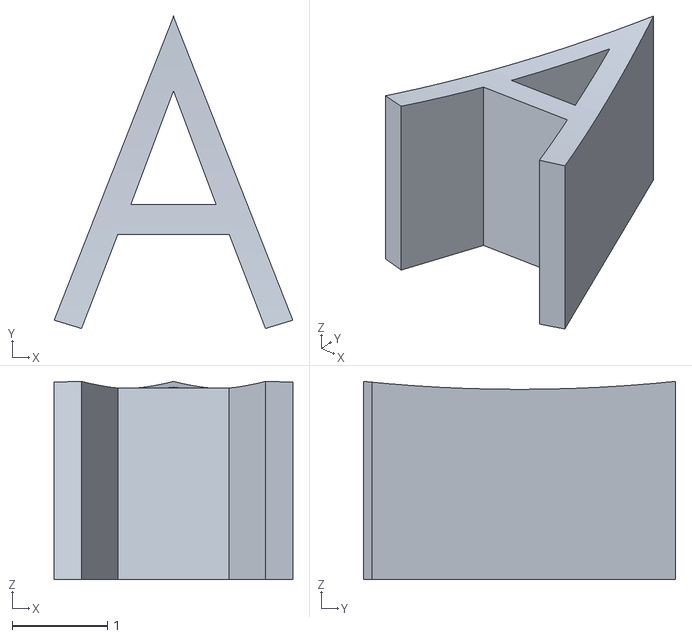
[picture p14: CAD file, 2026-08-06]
v4/example_renders/glyph_A_no_minkowski.stl
2.51 x 3.28 x 2.08

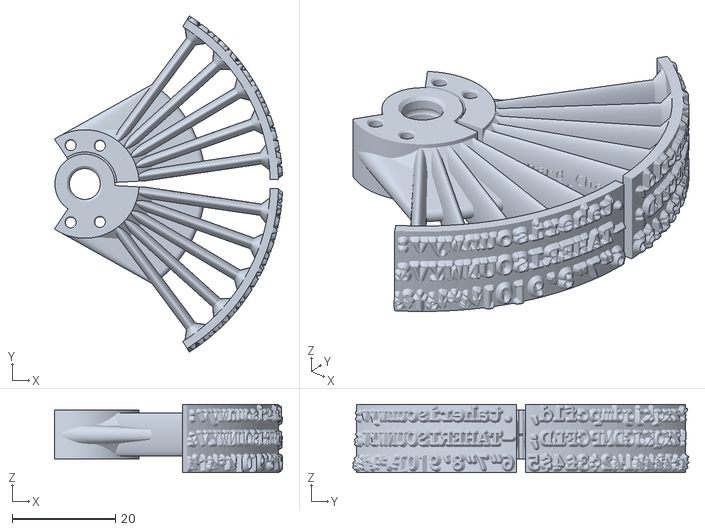
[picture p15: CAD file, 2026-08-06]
v4/example_renders/hammond-split-shuttle.stl
44.2 x 65.1 x 13.3

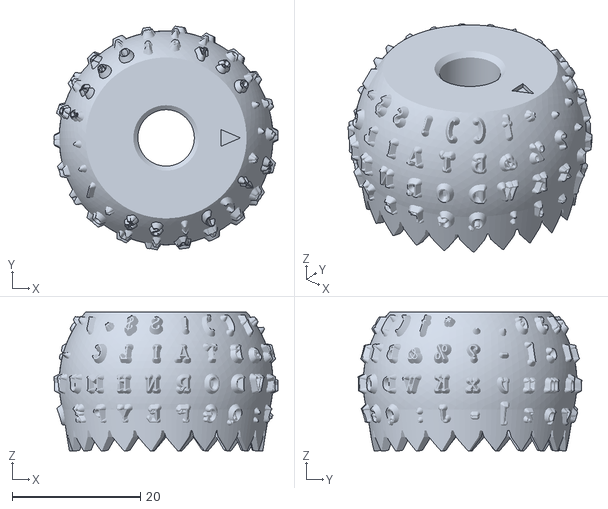
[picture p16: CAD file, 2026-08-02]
v4/example_renders/selectric-composer.stl
35.0 x 34.9 x 21.7

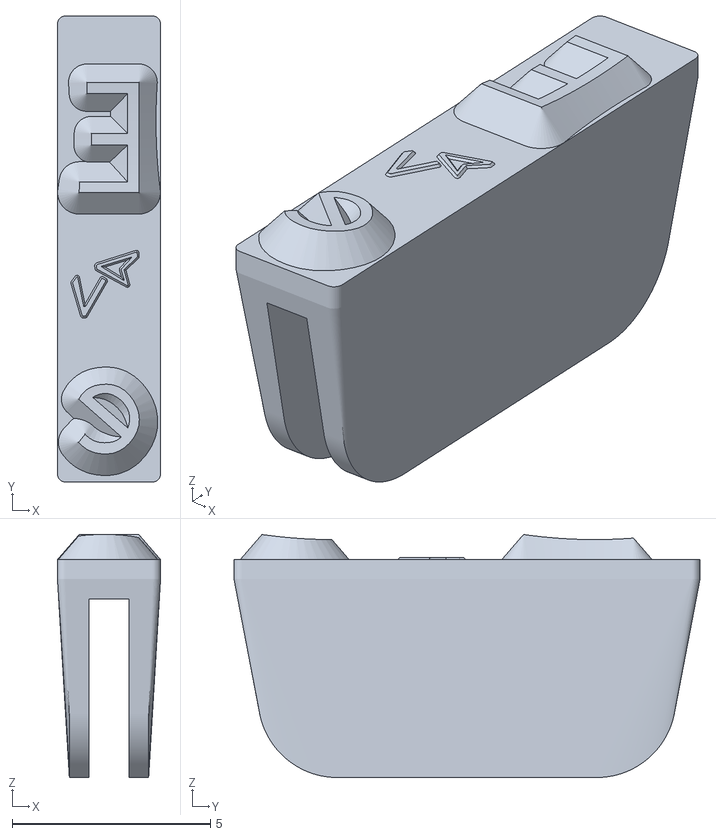
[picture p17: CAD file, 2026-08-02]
v4/example_renders/vogue-slug.stl
2.60 x 11.8 x 6.13

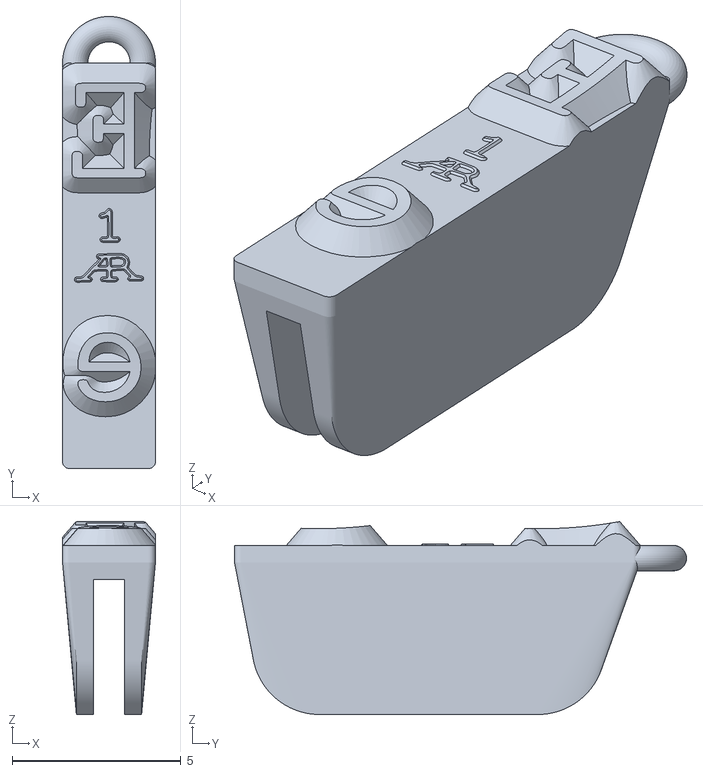
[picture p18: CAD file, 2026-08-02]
v4/example_renders/type-slug.stl
2.75 x 13.4 x 5.71

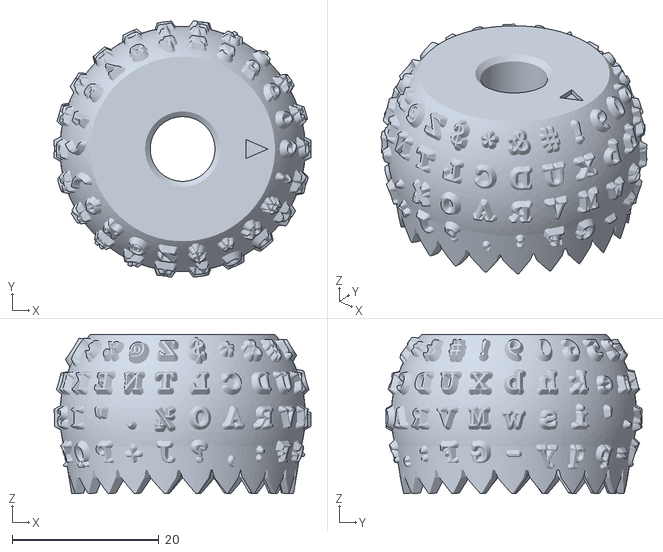
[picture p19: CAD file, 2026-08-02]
v4/example_renders/selectric-standard.stl
35.0 x 34.9 x 21.7

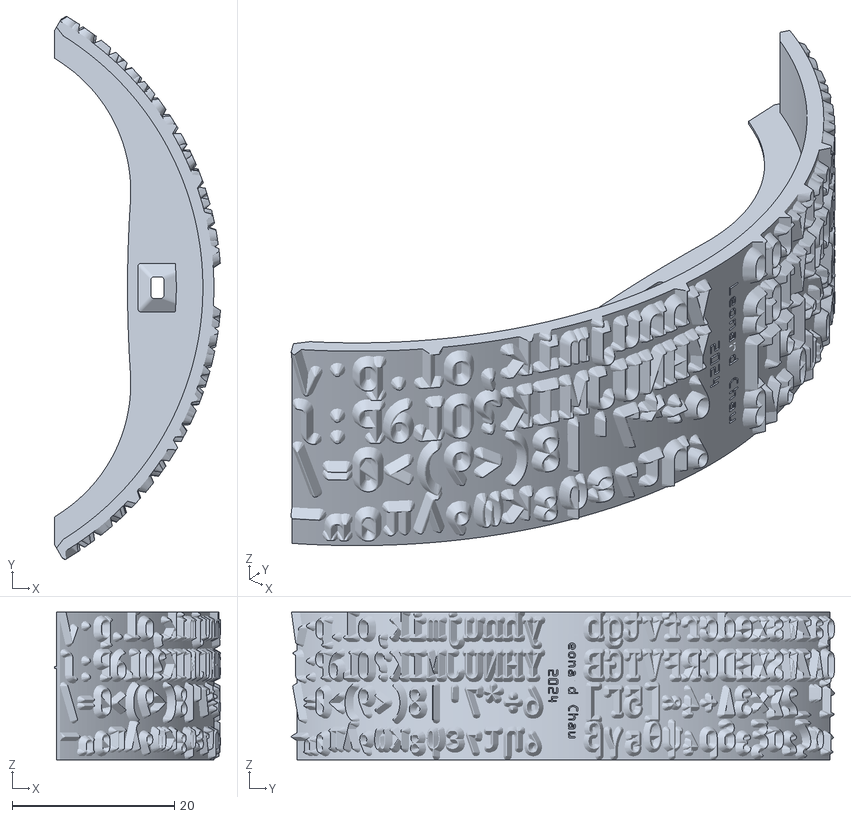
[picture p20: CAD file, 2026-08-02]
v4/example_renders/hammond-shuttle.stl
20.5 x 67.0 x 18.2

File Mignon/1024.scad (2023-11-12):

//Mignon 2, 3, 4 Type Cylinder
//September 13, 2023
//Leonard Chau


//ADD RESIN SUPPORT
/* [Character Details] */
//As Seen on Legend
/*LAYOUT=["'\"%&(£$);:,.",
          "?PFUGQpfugq¼",
        "!VINABvinab½",
        "_LDETMldetm¾",
        "JKOSRZkosrzj",
        "/YCHWXychwx@",
        "#1234567890-"];
LAYOUT=["&():\"!?'äöü_",
        "§PFUGQpfugq;",
        "JVINABvinabj",
        "/LDETMldetm,",
        "%KOSRZkosrz=",
        "¾YCHWXychwx+",
        "½¼23456789.-"];
*/
//Custom Layout
1st_Row="";
2nd_Row="";
3rd_Row="";
4th_Row="";
5th_Row="";
6th_Row="";
7th_Row="";
CUSTOMLAYOUT=[1st_Row,2nd_Row,3rd_Row,4th_Row,5th_Row,6th_Row,7th_Row];
include <IndexLayouts.scad>
CharLegend=[7,8,9,10,11,0,1,2,3,4,5,6];
Layout_Selection=0; //[0:English Unknown, 1:Custom Layout, 2:Deutsch 4, 3:English 4, 4:French 3, 5:International Schreibschrift, 6:Schwedisch 2]
Layout=Layouts[Layout_Selection];
Tallen=false;
//Element Height Increase
Height_Increase=3;


Typeface_="Consolas";//As Installed on PC
Type_Size=3.3;//[1:.05:6]
Debug_No_Minkowski=true;//Speedy Preview and Render with No Minkowski
Horizontal_Weight_Adj=.001;//[.001:.001:.2]
Vertical_Weight_Adj=.001;//[.001:.001:.2]
//0 For subtractive, 1 for additive
Weight_Adj_Mode=0;//[0:None, 1:Subtractive, 2:Additive]
//Individual Character Height Adjustments
Character_Modifieds="_";
Character_Modifieds_Offset=0;//[-.1:.05:.5]
Scale_Multiplier_Text=".";
Scale_Multiplier=1.5;

//Label Text
Cylinder_Label="Label";
//Label Size
Cylinder_Label_Size=0.51*Type_Size;
//Label Font
Cylinder_Label_Font=Typeface_;
//Label Height Offset From Chamfer Base
Cylinder_Label_Height_Offset=.5;
//Spacing Between Characters (Degrees)
Cylinder_Label_Spacing=15;
//Label Offset From Pin (Degrees)
Cylinder_Label_Offset=0;

/* [Cylinder Details] */
//Total Cylinder Height
Cylinder_Height_=40;
Cylinder_Height= Tallen==true ? Cylinder_Height_+Height_Increase : Cylinder_Height_;
//Main Cylinder Diameter
Cylinder_Diameter=16.5; //GET NEW VALUE
//Height Drop From Top
Cylinder_Top_Height_Offset=3;
//Height Drop Chamfer Radius
//Cylinder_Top_Radius=2;
//Height Drop Chamfer Size
Cylinder_Top_Chamfer=1.75;
//Height Drop Diameter
Cylinder_Top_Diameter=10.5;
//Inner Shaft Diameter
Cylinder_Top_Shaft_Diameter=7.3;
//Inner Mounting Diameter
Cylinder_Bottom_Shaft_Diameter=14.6;
//Max Pin Height
Pin_Height=1.8;
//Max Pin Width
Pin_Width=1.7;
//Max Minimum Diameter Across 2 Concave Characters
Min_Final_Character_Diameter=17.4; //GET NEW VALUE
//Platen Diameter
Platen_Diameter=26.5;

/* [Character Placement Details] */
//[1st, 2nd, 3rd, 4th, 5th, 6th, 7th] Baseline Height
Baseline=[2.4, 7.55, 12.7, 17.7, 22.7, 27.7, 32.55];
Baseline_Offset=[0, 0, 0, 0, 0, 0, 0];
Cutout=[3.3, 8.55, 13.7, 18.7, 23.7, 28.7, 33.4];
Cutout_Offset=[0, 0, 0, 0, 0, 0, 0];
echo(Baseline+Baseline_Offset);

echo (Cutout+Cutout_Offset);


/* [Resin Print Support] */
//Generate Print Support?
Generate_Support=true;
//Resin Support Cut Groove Thickness
Resin_Support_Cut_Groove_Thickness=.1;
//Resin Support Height
Resin_Support_Height=4;
//Resin Support Chamfer Size
Resin_Support_Thickness=2;
//Resin Support Cut Groove Diameter
Resin_Support_Cut_Groove_Diameter=.75;
//Resin Support Wire Thickness
Resin_Support_Wire_Thickness=.6;
//Resin Support Contact Point Diameter
Resin_Support_Contact_Point=.2;
Cylinder_fn = $preview ? 360 : 360;
$fn = $preview ? 22 : 44;


module LetterText (SomeElement_Diameter,SomeBaseline,SomeBaseline_Offset,SomeCutout,SomeCutout_Offset, SomeTypeface_,SomeType_Size,SomeChar,SomeTheta,SomePlaten_Diameter,SomeMin_Final_Character_Diameter,SomeCharacter_Modifieds, SomeCharacter_Modifieds_Offset, SomeDebug, SomeHorizontal_Weight_Adj, SomeVertical_Weight_Adj, SomeWeight_Adj_Mode, SomeScale_Multiplier, SomeScale_Multiplier_Text){
    $fn = $preview ? 22 : 44;
    x=search(SomeChar, SomeScale_Multiplier_Text);
    minkowski(){
        difference(){
            translate([cos(SomeTheta)*SomeElement_Diameter/2,sin(SomeTheta)*SomeElement_Diameter/2,SomeBaseline+SomeBaseline_Offset])
            translate([0,0,SomeChar==SomeCharacter_Modifieds ?  SomeCharacter_Modifieds_Offset : 0])
            rotate([90,0,90+SomeTheta])
            mirror([1,0,0])
            linear_extrude(2)
            scale([x==[] ? 1: SomeScale_Multiplier, x==[] ? 1: SomeScale_Multiplier, 1])
            if (SomeWeight_Adj_Mode==2)
                minkowski(){
                    text(SomeChar,size=SomeType_Size,halign="center",valign="baseline",font=SomeTypeface_);
                    scale([SomeHorizontal_Weight_Adj, SomeVertical_Weight_Adj])
                    circle(r=1);
                }
            else if (SomeWeight_Adj_Mode==1)
                difference(){
                    text(SomeChar,size=SomeType_Size,halign="center",valign="baseline",font=SomeTypeface_);
                minkowski(){
                    difference(){
                        square([10, 10], center=true);
                        text(SomeChar,size=SomeType_Size,halign="center",valign="baseline",font=SomeTypeface_);
                    }
                    scale([SomeHorizontal_Weight_Adj, SomeVertical_Weight_Adj])
                    circle(r=1);
                    }
                }
                 else if (SomeWeight_Adj_Mode==0)
            text(SomeChar,size=SomeType_Size,halign="center",valign="baseline",font=SomeTypeface_);
                    
                
            translate([cos(SomeTheta)*(SomePlaten_Diameter/2+SomeMin_Final_Character_Diameter/2),sin(SomeTheta)*(SomePlaten_Diameter/2+SomeMin_Final_Character_Diameter/2),SomeCutout+SomeCutout_Offset])
            rotate([90,0,SomeTheta])
            cylinder(h=5,d=SomePlaten_Diameter,center=true,$fn=$preview ? 60 : 360);
        }
        if (SomeDebug!=true)
            rotate([0,-90,SomeTheta])
            cylinder(h=1.5,r2=.75,r1=0);
    }
}

 module regular_polygon(order,SomeCylinder_Diameter){
     angles=[ for (i = [0:order-1]) i*(360/order) ];
     coords=[ for (th=angles) [SomeCylinder_Diameter/2*cos(th), SomeCylinder_Diameter/2*sin(th)] ];
     polygon(coords);
 }
//Module Cylinder (SomeCylinder_Height,SomeCylinder_Top_Height_Offset,SomeCylinder_Diameter,SomeCylinder_Top_Radius,SomeCylinder_Top)
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

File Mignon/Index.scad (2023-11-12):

//Custom Layout
1st_Row="";
2nd_Row="";
3rd_Row="";
4th_Row="";
5th_Row="";
6th_Row="";
7th_Row="";
CUSTOMLAYOUT=[1st_Row,2nd_Row,3rd_Row,4th_Row,5th_Row,6th_Row,7th_Row];
include <IndexLayouts.scad>

CharLegend=[7,8,9,10,11,0,1,2,3,4,5,6];
//Layout Selection
Layout_Selection=2; //[0:American?, 1:Custom Layout, 2:Deutsch 4, 3:English 4, 4:French 3, 5:International Schreibschrift, 6:Schwedisch 2]
Layout=Layouts[Layout_Selection];
//Index Length
Length=133;
//Index Width
Width=83;
//Fill in Circles on Left
Left_Side_Circle_Fill=true;
//Fill in Background on Right
Right_Side_Background_Fill=true;
//Fill in Background on Left
Left_Side_Background_Fill=false;
//Fill in Circles on Right
Right_Side_Circle_Fill=false;
//Circle Diameter
Circle_Diameter=8;
//Circle Height Offset
Circle_Height_Bump=.8;
//Line Thickness
Line_Width=.3;
//Index Corner Radius
Corner_Radius=9;
//Edge of Index to Column Center
Edge_to_Column=10.5;
//Edge of Index to Row Center
Edge_to_Row=9.5;
//Square Hole Size
Square_Pattern_Size=.5;
//Square Hole Pitch
Square_Pattern_Pitch=.8;
//Apply Checker Border? (slow - do last)
Checker=false;
//Font Name
Typeface_="Consolas";
//Font Size
Type_Size=5;//Type Size
//Horizontal Weight Adjustment
Horizontal_Weight_Adj=.001;//[.001:.001:1]
//Vertical Weight Adjustment
Vertical_Weight_Adj=.001;//[.001:.001:1]
//Weight Adjustment Mode
Weight_Adj_Mode=1;//[0:Subtractive, 1:Additive];
//Weight Adjustment Shape
Weight_Adj_Shape=0;//[0:Circle, 1:Square]
//Individual Character Height Adjustments
Character_Modifieds="_pgqjy()fbldtkh";
//Circle Center to Text Baseline Height
Height_Offset=2.1;
//Underscore Height Offset
Underscore_Offset=1;
//Descenders Height Offset
Descenders_Offset=.4;
//Parentheses Height Offset
Parentheses_Offset=.4;
//Ascenders Height Offset
Ascenders_Offset=-.5;
Character_Modifieds_Offset=[Underscore_Offset,Descenders_Offset,Descenders_Offset,Descenders_Offset,Descenders_Offset,Descenders_Offset,Parentheses_Offset,Parentheses_Offset, Ascenders_Offset, Ascenders_Offset, Ascenders_Offset, Ascenders_Offset, Ascenders_Offset, Ascenders_Offset, Ascenders_Offset];//[-.1:.05:2]
mid_x=(Edge_to_Column+(Edge_to_Column+1*(Length-2*Edge_to_Column)/11))/2;
mid_y=(Edge_to_Row+Edge_to_Row+1*(Width-2*Edge_to_Row)/6)/2;
half_line=Line_Width/2;
mid_xl=Length-2*mid_x;
mid_yw=Width-2*mid_y;

$fn=$preview?30:60;


//for (r=[0:1:6]){
//    for (c=[0:1:11]){
//        xpos=Edge_to_Column+c*(Length-2*Edge_to_Column)/11;
//        ypos=Edge_to_Row+r*(Width-2*Edge_to_Row)/6;
//        translate([xpos, ypos])
//        text(text=Layout[r][c], size=Type_Size, halign="center", valign="center");
//    }
//}
//}

module Text (Length, Width, r, c, Edge_to_Row, Edge_to_Column, Layout, Character_Modifieds, Character_Modifieds_Offset, Height_Offset, Type_Size, Typeface_, Weight_Adj_Mode, Horizontal_Weight_Adj, Vertical_Weight_Adj, Weight_Adj_Shape){
    xpos=Edge_to_Column+c*(Length-2*Edge_to_Column)/11;
        ypos=Edge_to_Row+(6-r)*(Width-2*Edge_to_Row)/6-Height_Offset;
        x=search(Layout[r][c],Character_Modifieds);
        translate([xpos, ypos])
        translate([0, x==[]?0:Character_Modifieds_Offset[x[0]]])
        //text(text=Layout[r][c], font=Typeface_, size=Type_Size, halign="center", valign="baseline");
        if (Weight_Adj_Mode==1)
                minkowski(){
                    text(Layout[r][c],size=Type_Size,halign="center",valign="baseline",font=Typeface_);
                    scale([Horizontal_Weight_Adj, Vertical_Weight_Adj])
                    if (Weight_Adj_Shape==0)
                    circle(r=1);
                    else
                    square([Horizontal_Weight_Adj*2, Vertical_Weight_Adj*2], center=true);
                }
            else if (Weight_Adj_Mode==0)
                difference(){
                    text(Layout[r][c],size=Type_Size,halign="center",valign="baseline",font=Typeface_);
                minkowski(){
                    difference(){
                        square([10, 10], center=true);
                        text(Layout[r][c],size=Type_Size,halign="center",valign="baseline",font=Typeface_);
                    }
                    scale([SomeHorizontal_Weight_Adj, SomeVertical_Weight_Adj])
                    circle(r=1);
                    }
                }
}
//projection()
translate([0,0,-1])
linear_extrude(1)
union(){
    difference(){
        hull(){
            translate([Corner_Radius, Corner_Radius])
            circle(r=Corner_Radius);
            translate([Length-Corner_Radius, Corner_Radius])
            circle(r=Corner_Radius);
            translate([Length-Corner_Radius, Width-Corner_Radius])
            circle(r=Corner_Radius);
            translate([Corner_Radius, Width-Corner_Radius])
            circle(r=Corner_Radius);
        }
        //FIRST CUT:
        //CUT BACKGROUND
        if (Checker==true){
        for (x=[0:Square_Pattern_Pitch:Length]){
            for (y=[0:Square_Pattern_Pitch:Width]){
                translate([x,y])
                rotate([0,0,45])
                square(Square_Pattern_Size);
            }
        }
        }
        //CUT CENTER RECTANGLE
        translate([mid_x, mid_y])
        square([Length-2*mid_x, Width-2*mid_y]);
        
        
        for (r=[0:1:6]){
            for (c=[0:1:11]){
                xpos=Edge_to_Column+c*(Length-2*Edge_to_Column)/11;
                ypos=Edge_to_Row+r*(Width-2*Edge_to_Row)/6;
                translate([xpos, ypos])
                scale([1, (Circle_Diameter+2*Circle_Height_Bump)/Circle_Diameter])
                circle(d=Circle_Diameter);
            }
        }
    }//END CUTTING
    
    //BEGIN LINEWORK
    //BOLDING OUTER CIRCLES
    for (r=[0:1:6]){
        for (c=[0:1:11]){
            xpos=Edge_to_Column+c*(Length-2*Edge_to_Column)/11;
            ypos=Edge_to_Row+r*(Width-2*Edge_to_Row)/6;
            translate([xpos, ypos])
            scale([1, (Circle_Diameter+2*Circle_Height_Bump)/Circle_Diameter]){
            difference(){
            circle(d=Circle_Diameter+Line_Width);
            circle(d=Circle_Diameter-Line_Width);}
            }
        }
    }
    //BORDERING CENTER RECTANGLE
    
    translate([Length/2, Width/2]){
        difference(){
            square([mid_xl+Line_Width, mid_yw+Line_Width], center=true);
            square([mid_xl-Line_Width, mid_yw-Line_Width], center=true);
        }
    }//END LINEWORK
    
    //BEGIN PLACING CHARACTERS
    //PLACE BORDERING CHARACTERS
    for (r=[0,6]){
        for (c=[0:1:11]){
            Text(Length, Width, r, c, Edge_to_Row, Edge_to_Column, Layout, Character_Modifieds, Character_Modifieds_Offset, Height_Offset, Type_Size, Typeface_, Weight_Adj_Mode, Horizontal_Weight_Adj, Vertical_Weight_Adj, Weight_Adj_Shape);
        }
    }
    for (r=[1:1:5]){
        for (c=[0,11]){
        Text(Length, Width, r, c, Edge_to_Row, Edge_to_Column, Layout, Character_Modifieds, Character_Modifieds_Offset, Height_Offset, Type_Size, Typeface_, Weight_Adj_Mode, Horizontal_Weight_Adj, Vertical_Weight_Adj, Weight_Adj_Shape);
        }
    }//END BORDERING CHARACTERS
    
    //FILL HANDLING
    //IF LEFT SIDE FILL = FALSE
    if (Left_Side_Circle_Fill==false){
        for (r=[1:1:5]){
            for (c=[0:1:5]){
                Text(Length, Width, r, c, Edge_to_Row, Edge_to_Column, Layout, Character_Modifieds, Character_Modifieds_Offset, Height_Offset, Type_Size, Typeface_, Weight_Adj_Mode, Horizontal_Weight_Adj, Vertical_Weight_Adj, Weight_Adj_Shape);
            }
        }
    }
    else //IF LEFT SIDE FILL = TRUE
        for (r=[1:1:5]){
            for (c=[1:1:5]){
                xpos=Edge_to_Column+c*(Length-2*Edge_to_Column)/11;
                ypos=Edge_to_Row+(6-r)*(Width-2*Edge_to_Row)/6;
                difference(){
                translate([xpos, ypos])
                scale([1, (Circle_Diameter+2*Circle_Height_Bump)/Circle_Diameter])
                circle(d=Circle_Diameter-Line_Width); 
                Text(Length, Width, r, c, Edge_to_Row, Edge_to_Column, Layout, Character_Modifieds, Character_Modifieds_Offset, Height_Offset, Type_Size, Typeface_, Weight_Adj_Mode, Horizontal_Weight_Adj, Vertical_Weight_Adj, Weight_Adj_Shape);}
            }
        }
    //IF RIGHT SIDE FILL = FALSE
    if (Right_Side_Circle_Fill==false){
        for (r=[1:1:5]){
            for (c=[6:1:11]){
                Text(Length, Width, r, c, Edge_to_Row, Edge_to_Column, Layout, Character_Modifieds, Character_Modifieds_Offset, Height_Offset, Type_Size, Typeface_, Weight_Adj_Mode, Horizontal_Weight_Adj, Vertical_Weight_Adj, Weight_Adj_Shape);
            }
        }
    }
    else //IF RIGHT SIDE FILL = TRUE
        for (r=[1:1:5]){
            for (c=[6:1:10]){
                xpos=Edge_to_Column+c*(Length-2*Edge_to_Column)/11;
                ypos=Edge_to_Row+(6-r)*(Width-2*Edge_to_Row)/6;
                difference(){
                translate([xpos, ypos])
                scale([1, (Circle_Diameter+2*Circle_Height_Bump)/Circle_Diameter])
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

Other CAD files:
v4/example_renders/helios-klimax.stl
v4/example_renders/oliver-slug.stl
v4/example_renders/mignon.stl
v4/example_renders/postal.stl
Mignon/MignonIndex.scad
v1/Template.scad
v1/Bennett/BennettElement.scad
v1/Bennett/BennettLayouts.scad
v1/Blickensderfer/Blickensderfer2.scad
v1/Blickensderfer/BlickensderferElement.scad
v1/Blickensderfer/HebrewBlickensderferElement.scad
v1/FontTester.scad
v1/Hammond/GalgolicHammondShuttle.scad
v1/Hammond/HammondIndex.scad
v1/Hammond/HammondShuttle.scad
v1/Hammond/HammondSplitShuttle.scad
v1/Hammond/HammondSplitShuttle2.scad
v1/HeliosKlimax/HeliosKlimaxElement.scad
v1/HeliosKlimax/HeliosKlimaxTester.scad
v1/IBM/IBM2.scad
v1/Mignon/MignonCylinder.scad
v1/Mignon/MignonIndex.scad
v1/Mignon/MignonIndexLayouts.scad
v1/Postal/Postal.scad
v1/Type Slugs/GaugeTypeSlugSlug.scad
v1/Type Slugs/LumiSlug.scad
v1/Type Slugs/OliverSlug.scad
v1/Type Slugs/TypeSlug.scad
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

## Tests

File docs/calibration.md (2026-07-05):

# Calibration Procedures

**The core challenge:** A printed element must physically fit the machine shaft, engage the drive mechanism correctly, AND strike characters at exactly the right position on paper with the right contact area. Every physical machine is slightly different; values must be found empirically.

---

## Parameters requiring calibration (in order)

| # | Parameter | What it controls | Test |
|---|---|---|---|
| 1 | `coreIDOffset` | Shaft bore sliding fit | Gauge Set |
| 2 | `drivePinWidthOffset` | Drive pin slot fit | Manual fit |
| 3 | `charBaselines[row]` | Character height on element (vertical strike position on paper) | Baseline sweep |
| 4 | `platenBaselines[row]` / `PLATEN_LONGITUDE_OFFSETS[row]` | Platen cutout depth (contact area match) | Cutout sweep |
| 5 | `minkDraftAngle` / `MINKOWSKI_ANGLE` | Character taper angle (IBM only; others use fixed 55°) | Draft sweep |
| 6 | `fontSize` / `fontWeightOffset` | Character size and stroke weight | Type test |

Do not skip to step 4 if step 1 is not done. Each depends on the previous.

---

## Test modes (Blickensderfer2 / Postal)

### `testLayout=true` + `testChar="H"` — single character

Renders the same character at every column (0–27) across all 3 rows. Use `H` — symmetric, has verticals and horizontals, easy to judge impression evenness at any angle.

Use to verify element body geometry before worrying about character layout.

### `cutoutTest=true` — platen cutout depth sweep

```openscad
cutoutTestStart = 0        // starting offset
cutoutTestInt = 0.05       // mm increment per column
// Column n gets: platenBaseline + n * cutoutTestInt
// Column 0 = +0.00 mm, column 27 = +1.35 mm
```

`TestDebug()` prints a console table mapping column → offset.

**Reading result:** Install element, type by cycling through all character positions. The column with the most even ink coverage across the full character face = correct offset. Multiply best column × `cutoutTestInt`, add that to `platenBaselines[row]`.

### `baselineTest=true` — character height sweep

Same sweep pattern, offsets `charBaselines[row]` instead.

**Reading result:** Find column where characters fall at the correct vertical position relative to original element strike position. Apply correction.

### `renderMode=2` — Gauge Set (shaft tolerance)

Six shaft holes side by side, each 25 µm larger than the previous:
```openscad
gaugeOffsetStart = 0
gaugeOffsetInt = 0.025   // 25µm per slot
// Slots at: 0, 0.025, 0.050, 0.075, 0.100, 0.125 mm added to coreIDmm
```

Print, try each hole on shaft. Loosest hole with no lateral play = correct `coreIDOffset`. Typical: `0.14 mm` (Blick), `0.20 mm` (Postal).

### `renderMode=3` — Type Test (2D flat layout)

All characters flat at `testCPI` spacing. Use to verify font/size choices and catch missing characters before printing a full element.

---

## Test modes (IBM2)

IBM2 has 4 sweep tests, each mapping across the 22 latitude positions.

### `CUTOUT_TEST` — platen cutout angle offset sweep

```openscad
CUTOUT_TEST_START = 0
CUTOUT_TEST_ANGLE_INT = 0.05  // degrees per latitude
```

Sweeps the platen cutout longitude angle. `ConsoleCutout()` dumps a full table: character, row, latitude, cutout offset, draft angle. When `CUTOUT_TEST=true`, alignment is forced to center and position offsets are zeroed to isolate this variable.

Final calibrated values: `PLATEN_LONGITUDE_OFFSETS=[-1.05, -1.05, -1, -1.05]`.

### `DRAFTANGLE_TEST` — draft angle sweep

```openscad
DRAFTANGLE_TEST_START = 50
DRAFTANGLE_TEST_INT = 1    // 1° per latitude
```

Sweeps draft angle 50°–71°. Find angle giving clearest impression without smearing.

### `MINK_LONG_OFFSET_TEST` — longitudinal Minkowski offset

Tilts the draft cone longitudinally (toward/away from equator) per row. Final values: `MINKOWSKI_LONGITUDINAL_OFFSETS=[0, 0, 0, 0]`.

### `PLATEN_DIAMETER_TEST` — platen diameter sweep

```openscad
PLATEN_DIAMETER_TEST_START = 30
PLATEN_DIAMETER_TEST_INT = 1   // 1mm per latitude
```

Useful when a machine's platen has been re-covered with different diameter rubber.

### `SELECTIVE_RENDER="sine"` + `SELECTIVE_RENDER_CHARS`

Renders only specific characters. Speeds up render when debugging individual glyphs.

### `XSECTION=true` — cross-section view

Cross-sections the element at angle `XSECTION_THETA`. Verify platen cutout depth, wall thickness, and character protrusion before printing.

---

## Calibration procedure (new element design)

### Step 1: Shaft fit
1. `renderMode=2`, print gauge set
2. Find loosest slot with no play
3. Record and lock `coreIDOffset` in `.json`

### Step 2: Drive pin fit
1. Print test element with `Mink_On=false`
2. Check drive pin slot engages without forcing
3. Adjust `drivePinWidthOffset` (typically 0.10–0.20 mm)

### Step 3: Baseline height
1. `testLayout=true`, `testChar="H"`, `baselineTest=true`
2. Print with supports
3. Install, type across all positions against a ruled reference line
4. Find column with best vertical centering; compute `best_column × baselineTestInt`
5. Apply correction to `charBaselines[row]` for each row

### Step 4: Platen cutout depth
1. `cutoutTest=true`, `testChar="H"` (or all chars)
2. Print and install
3. Look for even ink coverage across character face
4. Find best column; apply `best_column × cutoutTestInt` to `platenBaselines[row]`

### Step 5: Font size and weight
1. `renderMode=3` (type test)
2. Compare against original element typeface sample
3. Adjust `fontSize`, `fontWeightOffset`, `xFontWeightAdj`, `yFontWeightAdj`

---

## Calibration procedure (existing design, new machine instance)

Shaft/drive pin offsets often don't change for the same machine model. Start at Step 3. Check platen diameter if the platen has been re-covered.

---

## Debugging by symptom

| Symptom | Likely cause | Fix |
|---|---|-----|
| Characters print too high | `charBaselines` too high | Baseline sweep, decrease |
| Characters print too low | `charBaselines` too low | Baseline sweep, increase |
| Uneven impression: heavy top, light bottom (or vice versa) | `platenBaselines` offset wrong | Cutout sweep |
| Faint in center, dark at edges | Cutout too deep (over-curved) | Cutout sweep, adjust |
| Faint at edges, dark in center | Cutout too shallow (under-curved) | Cutout sweep, adjust |
| Won't slide onto shaft | `coreIDOffset` too small | Gauge set, increase |
| Wobbles on shaft | `coreIDOffset` too large | Gauge set, decrease |
| Characters smear on upstroke | Draft angle too shallow | Increase draft angle |
| Characters blurry / too wide | Font weight too high or draft too steep | Decrease `fontWeightOffset` / draft |
| Specific character prints badly | Per-char modifier needed | `charMods`, `charModsBaselineOffset`, `Scale_Multiplier` |

---

## Saving calibrated values

**Current practice:** Values live in the `.json` Customizer preset file. Fragile — no machine serial, no date.

**Better practice:**
- One `.json` preset per machine instance (e.g. `Blickensderfer2_SN12345.json`)
- Comment block in the `.scad` listing locked values and their source date
- Include calibration history in comments when a value changes (see machine-specs.md for Blick platen baseline history as example)

Every new machine file should include all test modes from day one. Copy from Blickensderfer2. This costs nothing and prevents re-discovering calibration methodology on every new machine.

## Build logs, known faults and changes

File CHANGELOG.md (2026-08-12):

# Changelog

This file covers the **OpenSCAD generations only** (v1 → v2). v4, the
current Python pipeline, keeps its own far more detailed history in
[`v4/SESSION_LOG.md`](v4/SESSION_LOG.md) — nothing about v4 is recorded
here.

## v2.0 — Shared library refactor

Executes `docs/refactoring-plan.md`'s target architecture. All work lives in
`v2/`; nothing in the original per-machine directories (`Blickensderfer/`,
`Postal/`, `Bennett/`, `Mignon/`, `HeliosKlimax/`, `IBM/`, `Hammond/`) was
modified or deleted — every v2 file names its V1 original in its own header
comment.

### New: `v2/lib/`

- `glyph_pipeline.scad` — the shared `TwoDText`/`WeightAdjShape`/
  `PlatenCutout`/`LetterPlacement`/`LetterText`/`TextRing` pipeline used by
  every cylinder-family machine (Blickensderfer, Postal, Bennett, Mignon,
  Helios Klimax) plus `hammond.scad` (HammondShuttle). Every machine declares
  the full canonical variable set directly (same names, same Customizer
  section order) rather than relying on silent per-machine defaults — see the
  file's own header comment for the complete parameter list and the
  per-machine equivalence notes (numeric verification for Bennett's platen
  cutout, algebraic verification for Helios, structural-analogy verification
  for Hammond's placement/baseline axis mapping).
- `resin_support.scad` — Blickensderfer2/Postal's `CutGroove`/
  `SpeedHoleSupport`/`DrivePinSupport`/`BottomSupports` placement system
  (the single-rod primitive itself now lives in `resin_rod.scad`, see below).
  Not shared by Helios/IBM/Hammond, whose resin-support geometry is genuinely
  different (see `docs/resin-supports.md`) and stays local to each v2 file.
- `resin_rod.scad` — the universal single resin-support-rod shape (`hull()`
  tapered tip + `hull()` capsule shaft + optional raft frustum), split out of
  `resin_support.scad` so machines with their own placement pattern can still
  reuse the one rod primitive. `resin_support.scad` includes it internally,
  so Blickensderfer2/Postal need no changes. Bennett and Mignon now include
  it directly (see below) - see `docs/resin-supports.md`.
- `core_shaft.scad` — Blickensderfer2/Postal/Bennett's core-groove/chamfer
  system (`SecondaryCore`, `CoreGrooves`, `CoreChamfer`, `CoreEllipses`).
  Mignon and Helios Klimax have no equivalent groove system.
- `layouts/` — pure layout data extracted verbatim: `blick_layouts.scad`,
  `bennett_layouts.scad`, `mignon_layouts.scad`, `ibm_layouts.scad`,
  `hammond_layouts.scad`.
- `testing.scad` — `testSweepArray(start, interval, count)`, the linear
  sweep-array formula (`start + interval*n`) shared by Blickensderfer2/
  Postal's `cutoutTestArray`/`baselineTestArray` and IBM's four independent
  sweep arrays (`CUTOUT_TEST_ANGLE_ARRAY`/`DRAFTANGLE_TEST_ARRAY`/
  `MINK_LONG_OFFSET_TEST_ARRAY`/`PLATEN_DIAMETER_TEST_ARRAY`) — wiring IBM
  into it also removed `TEST_ARRAY_MAP`, a dead identity-map indirection.
  Bennett/Mignon/Helios Klimax/Hammond use a fixed literal array of
  already-measured offsets instead of a uniform sweep, so there's nothing of
  theirs to extract here — only per-machine data, not duplicated logic. Also
  removed the dead, never-referenced `testing_console` variable from Bennett/
  Mignon/Helios Klimax, and Mignon's unused `TESTING` legend-array leftover.

### New: `v2/` thin machine files

| v2 file | Was | Glyph pipeline | Notes |
|---|---|---|---|
| `blickensderfer.scad` | `Blickensderfer/Blickensderfer2.scad` | shared lib | reference implementation for the lib |
| `postal.scad` | `Postal/Postal.scad` | shared lib | |
| `bennett.scad` | `Bennett/BennettElement2.scad` | shared lib | verified numerically equivalent to V1 |
| `mignon.scad` | `Mignon/MignonCylinder2.scad` | shared lib | V1 `Assert` render gate converted to `Render` |
| `heliosklimax.scad` | `HeliosKlimax/HeliosKlimaxElement.scad` | shared lib | V1 had no render gate at all — added one |
| `ibm.scad` | `IBM/IBM2.scad` | local (spherical geometry) | layout data extracted to `lib/layouts/ibm_layouts.scad`; Global/Render Parameters aligned to the shared convention |
| `hammond.scad` | `Hammond/HammondShuttle.scad` | shared lib | V1 `Assert` render gate converted to `Render`; added `skipPlatenCutout` to the lib to support Hammond's flat-anvil strike (no curved platen) |
| `hammond_split.scad` | `Hammond/HammondSplitShuttle2.scad` | local (two-sided arc geometry) | structurally further from the shared pipeline than `hammond.scad` — flagged as a candidate for a follow-up pass unifying both Hammond machines together |

Not migrated (per `docs/refactoring-plan.md`'s own "unmaintained/reference-only"
table): `BlickensderferElement.scad`, `HebrewBlickensderferElement.scad`,
`HammondSplitShuttle.scad`, `GalgolicHammondShuttle.scad`, `HammondIndex.scad`,
`TypeHeightFinder.scad`, `imagetest.scad`. Note: the plan doc listed
`HammondShuttle.scad` as superseded by `HammondSplitShuttle2.scad` — that
turned out to be wrong (they're two distinct machine types still in use, not
sequential versions), so both were migrated.

### Verified vs. not-yet-verified

Verified by code-level equivalence review throughout (algebraic/numeric
checks for the trickier transform-composition cases, called out in each
file's own header comment). `openscad-nightly` became available mid-refactor
(2026.06.12 snap) and all 8 `v2/` files were confirmed to actually parse and
render to non-degenerate STL geometry with zero warnings/errors:
`blickensderfer.scad`, `postal.scad`, `bennett.scad`, `mignon.scad`,
`heliosklimax.scad`, `ibm.scad`, `hammond.scad`, `hammond_split.scad`.

That pass caught one real bug pre-dating this refactor's later files:
`blickensderfer.scad`/`postal.scad` (the two earliest "gold standard"
references) still used lowercase `render`/`xSection`/`xSectionTheta` with a
separate `module Render(){}` wrapper, never renamed to the `Render`/
`XSection`/`XSectionTheta` top-level-gate convention every machine migrated
afterward received - so `-D Render=true` silently did nothing on those two
files. Fixed to match every other machine.

It also caught a real bug in the shared lib itself: `TextRingDebug`'s console
echo (fires when `cutoutTest`/`baselineTest`/`testLayout` is enabled) had a
hardcoded 3-entry `["lowercase","uppercase","figs"]` row-label array that
only fit Blick2/Postal/Bennett's true 3-row shift-key machines - it silently
printed `"undef row"` for Mignon (7 rows) and Helios Klimax (4 rows), and
would have for Hammond's 4th (Math) row too. Fixed with an optional
`rowLabels` lib parameter (default: numeric `"row N"`); Blickensderfer2/
Postal/Bennett/Hammond set it to their real shift names, Mignon/Helios
Klimax use the numeric default since their rows have no such semantic name.

### Reference-keyboard identification for the console echo

`testLayout=true` collapses every physical position's rendered glyph to a
single `testChar`, on purpose - it makes different positions' print quality
directly comparable on the physical part. But that also collapsed the
console echo's character label to the same `testChar` everywhere, making it
impossible to identify which keyboard key/lever a good-impression position
corresponded to on the real machine.

Fixed by decoupling the echo's label from the rendered character:
`TextRingDebug` now takes a `refChar` alongside `char`, and `TextRing`
computes it from an optional `referencePhysicalLayout` (default: falls back
to `physicalLayout` itself, so it's already fixed for every machine even
without further wiring). Blickensderfer/Bennett/Mignon - the machines with
both multiple selectable content layouts and a fixed hardware
keyboard→physical remap (`elementLayoutArrayMap`/`CharLegend`) - additionally
wire in a dedicated `referenceLayoutSelection` dropdown (reusing each
machine's own layout preset list), independent of whatever content
`Layout_Selection` is currently being printed. The physical keyboard's key
labels are a hardware fact of the machine, not a function of what you're
currently engraving, so switching what you're printing never changes what
the echo calls a given physical position. Postal/Helios Klimax/Hammond don't
get a dedicated dropdown - either they have only one fixed layout, or (for
Hammond) the layout array is already in physical/lever order with no
separate keyboard remap step - so the default fallback already reports the
correct reference character.

Example echo line with `testLayout=true` and Bennett's default
`referenceLayoutSelection=0` (English): `character keyboard key 'g'
(rendered as 'H') on lowercase row at the 3oclock position with platen
cutout at ...` - press the g lever on the real machine, find the best
impression, then find "keyboard key 'g'" in the console log.

### Global/Render Parameters naming consistency

An audit (prompted by a direct check across all 8 files) found that Global
Parameters and Render Parameters weren't actually consistent, despite the
stated goal - some machines only *bridged* their old names to the canonical
ones deep in the "Glyph pipeline lib wiring" section rather than renaming the
declarations themselves, and the declared order silently diverged between
files:

- **Bennett/Mignon/Helios Klimax**: Global Parameters still declared
  `surface_fn`/`criticalcyl_fn`/`resin_fn`/`mink_fn`/`text_fn` (their original
  underscore-style names) and bridged them to `surfaceFn`/`cylFn`/`resinFn`/
  `minkFn`/`textFn` in a separate block further down. Renamed the
  declarations directly and removed the now-redundant bridging blocks.
  Helios's `minkFn` had no independent value at all (aliased to `text_fn`) -
  given its own literal (`minkFn=20`, matching every other machine's
  default; inert unless `minkOn` is enabled).
- **Render Parameters order**: Blickensderfer2/Postal declare `minkOn`/
  `minkDraftAngle` *before* `XSection`/`XSectionTheta`; Bennett/Mignon/Helios
  Klimax/IBM had drifted to the opposite order. Reordered the latter four to
  match Blickensderfer2/Postal (the original reference files).
- **IBM**: also had a leftover no-op `$fn=$preview?44:44;` (both ternary
  branches identical) - simplified to `$fn=44;`.
- **Hammond**: Global Parameters already used canonical camelCase names but
  in the wrong order - reordered to match.
- **Hammond split**: had no separate Global Parameters section at all
  (merged into a single `[Rendering]` block, its own original header before
  this refactor), and used `minkText`/`minkAngle` instead of `minkOn`/
  `minkDraftAngle`. Split the section and renamed both - confirmed a pure
  rename, not a behavior change: `minkRadius=tan(minkAngle/2)*minkHeight`
  reduces to exactly the shared lib's `minkTextR(angle)=2*tan(.5*angle)` once
  `minkHeight`'s default (2) is substituted in.

Re-verified after this pass: all 8 files still render to clean STL with zero
warnings/errors, and the reference-keyboard echo feature (Bennett tested
directly) still works correctly.

### Capital_Snake_Case naming convention across all 8 files

Converted every top-level variable in `v2/` (lib files + all 8 machine
files) from a three-way mix of conventions - camelCase (`minkFn`, `cutoutTest`),
underscore-style leftovers (`surface_fn`, `criticalcyl_fn`), and IBM's own
SCREAMING_SNAKE_CASE (`RENDER_MODE`, `MINK_FLAT`) - to a single
`Capital_Snake_Case` convention everywhere (`Mink_Fn`, `Cutout_Test`,
`Render_Mode`, `Mink_Flat`). Rationale: OpenSCAD's Customizer panel displays
variable names with underscores converted to spaces but preserves letter
case, so `Weight_Adj_Mode` reads as "Weight Adj Mode" in the sidebar while
`WEIGHT_ADJ_MODE` would read as "WEIGHT ADJ MODE" - full-caps for every field
in the panel, not just the handful that should stand out. Modules and
functions were deliberately left in their existing PascalCase/camelCase
forms (`TextRing`, `minkTextR`, `testSweepArray`) since they're never shown
in the Customizer and staying visually distinct from data variables is its
own useful signal.

Scope decisions:
- Data-preset arrays that function like named constants (layout content in
  `lib/layouts/*.scad` - `DHIATENSOR`, `LAYOUTS`, etc. - and each machine's
  own `CUSTOM*`-prefixed entry-point arrays, e.g. Bennett/Mignon's
  `CUSTOMLAYOUT`, IBM's `CUSTOMCASES88`) were left as ALL-CAPS, matching the
  precedent already set for `lib/layouts/`.
- Module-local temporary variables (leading-underscore convention, e.g.
  `_placementMap` inside `TextRing()`) and module/function parameter names
  (e.g. `TwoDText(char, font, size)`) were left alone - never Customizer-
  visible, changing them serves no part of the stated goal.
- IBM's own SCREAMING_SNAKE_CASE settings/dimensions were converted too
  (`RENDER_MODE`->`Render_Mode`, `BOSS_OD`->`Boss_OD`) for true consistency,
  keeping known dimension abbreviations (OD, ID, IR, OR, R, D, H, CPI)
  uppercase rather than title-casing them into something like `Od`.

Caught three real bugs along the way, all from names that were supposed to
be identical across files/modules but weren't (or became so during the
rename):
- `lib/layouts/ibm_layouts.scad` referenced `RENDER_MODE`/`COMPOSER_LANGUAGE`/
  `S12_88_LANGUAGE` by their pre-rename names - a separate file from
  `ibm.scad` that's easy to forget when renaming the declaring file. Fixed.
- IBM's `FONT2SIZE` (computed, `RENDER_MODE`-selected) and `FONT2_SIZE`
  (literal, `2.4`) are two genuinely different variables that both wanted to
  become `Font2_Size` - the exact same collision class already handled for
  `FONTSIZE`/`FONT_SIZE` earlier in the same file, just missed the second
  instance. Renamed the computed one to `Font2_Size_Selected`, matching its
  sibling `Font_Size_Selected`.
- Hammond's `AnvilID` (raw literal, `66.0`) and `Anvil_ID` (computed,
  `AnvilID+2*anviliroffset`) collapsed to the same name the same way.
  Renamed the raw literal to `Anvil_ID_Raw`.
- A more subtle one caught only by testing, not by the duplicate-declaration
  check: the auto-rename script renamed every occurrence of `font`,
  including the `font=` *keyword argument name* inside `text()` calls (an
  OpenSCAD builtin parameter, not a variable of ours) - `openscad-nightly`
  flagged this immediately as "variable Font not specified as parameter."
  Fixed by reverting keyword-argument-position occurrences back to lowercase
  `font=` everywhere, leaving genuine variable references as `Font`.

Also found (and left alone, since they're pre-existing and already proven
safe): `Render`/`module Render()` in `ibm.scad` and `Groove`/
`module Groove()` in `hammond.scad` are same-named variable/module pairs
that already existed before this pass and render without any issue -
OpenSCAD keeps separate namespaces for variables vs. modules/functions.
Two *new* collisions introduced by this rename (`Arc`/`module Arc()` and
`Logo`/`module Logo()` in `hammond_split.scad`) were checked the same way;
`Arc` (a computed angle colliding with unrelated arc-drawing geometry) was
renamed to `Arc_Extent` for clarity, `Logo` (a boolean toggle named after the
feature it enables, matching the already-accepted `Render`/`Groove`
pattern) was left as-is.

Re-verified after every file: renders to clean STL with zero warnings/
errors, no duplicate top-level declarations, and the `Test_Layout`/
`Baseline_Test`/`Cutout_Test` calibration echoes (including the reference-
keyboard feature) produce correct output on every machine.

Still not independently re-verified beyond "renders without error/warning":
- `$fn`-dependent curve smoothness (visual quality, not something a
  render-to-STL pass checks)
- minkowski draft-cone geometry for machines whose `Mink_On`/mink toggle is
  off by default (Bennett, Mignon, Helios Klimax, Hammond) and so were
  accepted by structural analogy rather than a from-scratch numeric
  derivation - turning `Mink_On=true` renders without error, but the actual
  taper shape against the original hasn't been compared point-by-point

### Bennett/Mignon migrated onto the shared `ResinRod()` primitive

Bennett and Mignon each hand-rolled their own resin-support-rod shape
(Bennett: flat cylinder shaft + 1mm cone taper + sphere tip + a base cone
flare with a `db` buildplate-diameter parameter that was accepted but never
actually used, the flare was hardcoded to `2.4` instead; Mignon: cylinder
shaft + 1mm cone tip ending in a flat disk, no sphere at all). Both were
already structurally close to Blickensderfer2/Postal's shared `ResinRod(h)`
(`lib/resin_rod.scad`, split out of `resin_support.scad` above), so this was
a faithful port of the rod shape only - each machine's own rod *placement*
(Bennett's 2 outer rings + 1 inner ring with a `Pyramidzoffset` curvature
correction; Mignon's 2 interleaved 12-fold rings) stays local, since neither
matches Blick/Postal's speed-hole/sloped-floor placement system.

Both wire `Resin_Rod_Raft=false`/`Resin_Min_Rod_Height=0`/
`Resin_Raft_Thickness=0` since each already builds its own separate raft/
groove ring directly in `ResinSupport()` - same override pattern Postal
already uses for the same reason. Bennett's previously-dead `db` parameter
(`Resin_Support_Buildplate_Diameter`) is now actually wired to
`Resin_Raft_OD`, though it goes unused while `Resin_Rod_Raft=false`.

One real discrepancy caught mid-migration: Bennett's original centered its
tip sphere directly *at* z=h (`translate([0,0,h]) sphere(d=dc)`), so the
sphere's true apex sat at `h+dc/2`, not `h`. A first pass set
`Resin_Inset=0` (a "faithful port"), which actually under-reached the
original by `dc/2` (~0.35mm) - fixed by setting
`Resin_Inset=Resin_Support_Contact_Point_Diameter/2` instead, which restores
the exact original apex height. Confirmed by re-rendering: the STL's genus
(a coarse topology fingerprint) matched Bennett's pre-migration baseline
exactly (89) once fixed, versus 81 with the `Resin_Inset=0` mistake. Mignon
needed no such correction - its original tip was a flat disk with zero
embed, exactly matching `Resin_Inset=0`.

Verified with `openscad-nightly`: Blickensderfer2/Postal's resin-print STL
is byte-for-byte identical before/after the `resin_rod.scad` split (the
placement lib's behavior is untouched). Bennett/Mignon's full resin-print
renders manifold with zero errors post-migration, and isolated
`ResinSupport()` renders + mid-part cross-sections were checked visually to
confirm every rod still reaches its target contact point with no floating
gaps.

### `Mink_On` naming unified across all v2 machines

Bennett/Mignon/Helios Klimax each carried a leftover `Debug_No_Minkowski`
boolean (`Debug_No_Minkowski=true; Mink_On=!Debug_No_Minkowski;`) - two names
for the same toggle, inconsistent with Blickensderfer2/Postal/IBM/Hammond/
`hammond_split.scad`, which all declare `Mink_On=false;` directly. Collapsed
to the single name everywhere: same default (`false`), same behavior.
Mignon's `ElementLabel()` had one other live reference
(`if (Debug_No_Minkowski!=true)`), updated to the equivalent
`if (Mink_On==true)`. `docs/glyph-pipeline.md` and `docs/calibration.md`'s
mentions of the old name updated to match. Verified byte-identical STL
output before/after for all three machines.

### `v2/ibm.scad`: added Selectric III (96char) as a third `Render_Mode`

Adds `Render_Mode=2` alongside the existing Composer (88char) and Selectric
I/II (88char) modes - 4 rows of 24 characters instead of 22, same physical
ball shell (`Sphere_OD`/`Inside_ID` etc. unchanged - Selectric II and III
typeballs are the same shell, just a different character layout/count).

Character layout data (`LOWERCASE96_US`/`UPPERCASE96_US`/
`S3_LC_HEMISPHERE96`/`S3_HEMISPHERE_MAP` in `lib/layouts/ibm_layouts.scad`)
is derived from https://github.com/selectricrescueatx/TypeElements
(`SelectricElement96.scad`, CC BY 4.0, Dave Hayden/Steve Malikoff)'s
`LOWER_CASE`/`UPPER_CASE`/`charmap96` - re-derived here (row-by-row from
`charmap96`), not copied verbatim, since the reference repo builds the ball
with a different placement algorithm (one combined 24-position ring per
row) than this codebase's two-opposite-hemispheres-180-degrees-apart
convention. First attempt used `charmap96`'s own column order (p=0..11)
directly per row and initially matched that file's own "Keyboard location
of each letter on the ball" comment exactly - but checking the rendered
result against a real physical Selectric III element found the
longitudinal order (position going around each ring) came out mirrored.
Fixed by reversing each row's column order; the reversed order also turned
out to closely match (module 2 minor transcription typos) an earlier
abandoned draft of this same data already sitting in this file, commented
out. `S3_HEMISPHERE_MAP` was computed the same way the existing
`S12_HEMISPHERE_MAP`/`COMPOSER_HEMISPHERE_MAP` were (a `search()`-based
derivation, run once with `openscad-nightly` and hardcoded), not
hand-derived. This supersedes that earlier abandoned draft (commented out,
marked "I AM NOT WORRYING ABOUT FOR THE TIME BEING") which also had a real
bug - rows 2-3 of its `LOWERCASE96` were still capitalized - and didn't
include the reference repo's extra `²`/`§`/`³`/`¶` characters (present on
the ball but not reachable via the S3 keyboard).

Row latitudes (the 4-row tilt array, shared across all three modes) keep
this codebase's own existing measured values (`[32.8, 16.4, 0, -16.4]`)
rather than adopting the reference repo's own tuned values
(`[31.1, 15.7, 0, -15.7]`) - both are close, these are the ones already
proven out here.

Also fixed a real naming bug while touching this: `Latitude_Spacing` (the
`360/22` angle between characters around a ring) and `Longitude_Spacing`
(the 4-row tilt array) were swapped relative to standard geographic
convention - tracing actual usage showed the ring-position value was being
called "latitude" and the row-tilt value "longitude", backwards both ways.
Renamed to `Longitude_Step`/`Row_Latitudes` respectively, and cascaded the
same fix through every local variable/parameter that used `lat`/`long`/
`latitude`/`longitude` (`LATITUDE_LONGITUDE` -> `LONGITUDE_LATITUDE`,
`PlatenCutout`/`PositionText`/`SingleMinkowski`'s parameter names, etc.) -
purely a rename, no behavior change (verified byte-identical STL for
Composer/Selectric I-II before and after).

Every place that hardcoded "22 characters per row" / "88 total" now reads
from `Chars_Per_Row_All`/`Total_Chars_All`/`Hemisphere_Cols_Per_Row_All`
(indexed `[Composer, Selectric I/II, Selectric III]`), following the same
`All_Font_Sizes[Render_Mode]`-style indexing idiom already used throughout
this file. This included one genuinely mechanical (not cosmetic) count:
`Teeth()`'s detent-tooth loop, since the tilt-ring detent mechanism needs
one tooth per character index position (24 for Selectric III), confirmed by
the reference repo's own `DetentTeeth()` using the same
`CHARACTERS_PER_LATITUDE` for its tooth count.

Not extended to Selectric III (deferred, not required for a working
render): the `testSweepArray(...,22)`-based calibration sweep arrays
(`Cutout_Test_Angle_Array`/`Draft_Angle_Test_Array`/etc.) are still
fixed at length 22, so `Cutout_Test=true`/`Draft_Angle_Test=true` will
show `undef` for the last 2 characters of each Selectric III row. The
character mapping itself is unaffected (confirmed via the
`Char_Info_Row_Col_Sorted` debug echo: all 96 characters appear exactly
once, correctly positioned, with the two apparent "duplicates" - `,`/`.`
each appearing twice - being intentional/correct, matching the reference
repo's own source data where the comma/period keys have no distinct
shifted symbol).

Verified: Composer/Selectric I-II render byte-identical STL before and
after every step of this change (including the longitudinal-order fix, which
touches Selectric-III-only data). Selectric III renders manifold with zero
errors/warnings and its character-position mapping was checked against the
user's own physical Selectric III element - which is what caught the
mirrored longitudinal order in the first derivation attempt.

`Tooth()`'s detent-notch profile is narrowed for render modes with more
teeth per row than the 22 it was tuned for, matching a difference found by
diffing the reference repo's `SelectricElement88.scad` against
`SelectricElement96.scad`: the 96-char file applies
`scale([1.0,88/96,1.0])` to the identical tooth polygon, since 24 teeth
around the same ring need to be individually narrower than 22 to avoid
touching. Generalized to `scale([1, Chars_Per_Row_All[1]/
Chars_Per_Row_All[Render_Mode], 1])` (a no-op for Composer/Selectric I-II,
since both use the same 22-count). This codebase's tooth-ring radius
(`Detent_Valley_To_Center=6`) is nearly identical to the reference repo's
(`TOOTH_PEAK_OFFSET_FROM_CENTRE=6.1`), so the same crowding the reference
repo's own maintainers found applies here too - a side-by-side render
comparison didn't show obvious tooth overlap even without this fix, but a
thin overlap is easy to miss visually and would still silently fuse in the
boolean union, so the reference repo's own established fix was applied
rather than relying on that inconclusive visual check.

### `Resin_Detent_Clock_Offset`: decoupled from `Detent_Skirt_Clock_Offset`

The tooth-width narrowing above shifts each tooth's angular position
slightly, which also nudged `ResinRodAssemble()`'s "detent teeth supports"
resin rod ring, since it shared `Detent_Skirt_Clock_Offset` (the actual
teeth geometry's clock alignment) for its own placement. Added a separate
`Resin_Detent_Clock_Offset` (default 0, same as before) so the resin rod
ring's clocking can be tuned independently of the teeth geometry itself -
`Drive_Notch_Theta` and `Teeth()` still use `Detent_Skirt_Clock_Offset`
unchanged. Verified Composer/Selectric I-II still render byte-identical
(both offsets default to 0, so behavior is unchanged unless one is tuned
away from the other going forward).

### Fixed: Bennett's resin rods had no raft (regression from the ResinRod migration)

`v2/bennett.scad`'s `Resin lib wiring` set `Resin_Rod_Raft=false` on the
assumption that `ResinSupport()`'s own big raft/groove ring (a
`rotate_extrude` at `Element_Diameter/2`, the very outer edge) already
covered every rod. It doesn't - the middle ring (`Countersink_Diameter/3`)
and inner ring (`Shaft_Diameter/2+1`) sit well inside that radius and never
touch it, so disabling the shared primitive's per-rod raft left every rod
in those two rings with a bare bottom and no anchor to the build plate at
all. The old local `ResinRod` (before the migration) had its own small
per-rod base flare for exactly this reason - removing it was the actual
regression, not a cleanup.

Fixed by re-enabling `Resin_Rod_Raft=true` and giving it a real
`Resin_Raft_Thickness` (was `0`, which degenerates the raft `cylinder()` to
zero height even when enabled). Uses `Resin_Support_Thickness` (already an
exposed Bennett customizer parameter) for the taper rather than reproducing
the old formula's disconnected hardcoded literal exactly - a couple tenths
of a mm difference at the default thickness, immaterial for a print
support. `Resin_Raft_OD` reverts to the old hardcoded `2.4` base diameter
instead of the `Resin_Support_Buildplate_Diameter` it was wired to during
the migration - that parameter was truly dead/unused in the original code
(the `db` argument was accepted but ignored, so its old default of `1.2`
was never actually the real base diameter), and wiring it up changed the
effective size without evidence that was intended. Verified visually:
every rod (outer, middle, and inner rings) now has its own raft foot.

Follow-up (found by comparing against Blickensderfer2/Postal's own resin
wiring): the first pass left `Resin_Min_Rod_Height=0`, which - per
`lib/resin_rod.scad`'s own formula (`translate([0,0,
-Resin_Min_Rod_Height-Resin_Raft_Thickness])`) - puts the per-rod raft at
local z=`[-Resin_Support_Thickness, 0]`. Both the old local `ResinRod`'s
raft flare and Bennett's own big outer "Create Raft" ring sit at
z=`[0, Resin_Support_Thickness]` instead - the opposite side of the z=0
datum - so the per-rod feet were floating below where they belonged rather
than coplanar with the outer ring. Fixed by setting
`Resin_Min_Rod_Height=-Resin_Raft_Thickness`, which cancels out to put the
raft back at `[0, Resin_Support_Thickness]`, matching both. Confirmed
visually: raft feet now sit flush with the outer ring band instead of
hanging below it.

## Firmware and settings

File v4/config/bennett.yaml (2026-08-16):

# Bennett type element - all real parameters ported 1:1 from
# v2/bennett.scad (see that file for authoritative source/comments).
# Bennett shares the glyph placement pipeline (TextRing/CalibrationTextRing,
# via cylinder_machine.py) with Blickensderfer/Postal/Mignon, and reuses
# lib/core_shaft.scad's shared SecondaryCore/CoreGrooves/CoreChamfer/
# CoreEllipses (Core_Chamfer_Top=false - no clip, so unlike Blickensderfer/
# Postal there's no top chamfer under a clip) and lib/resin_rod.scad's
# ResinRod - but its own body (PositionerPins/HollowBody/AlignmentHoles/
# LabelText/SpeedHoles/Countersinks/IndicatorHole) and resin-support
# placement are fully bespoke, structurally unlike either the
# Blickensderfer/Postal "drive pin trio" pattern or Mignon's chamfer-boss
# body - see lib/bennett.py's module docstring for the full comparison.
# Two v2 customizer params are declared but never referenced by any module
# in v2/bennett.scad (confirmed dead code, not a v4 omission):
# Inside_Radius and Resin_Support_Buildplate_Diameter - neither is ported.

machine: bennett

font:
  # v2's real value is the font family name "Average Mono" (Type_Size=
  # 3.00), not a file path - this is that font's real file.
  path: "/home/lchau/fonts/Library/Typewriter & Monospace/AverageMono.otf"
  size_mm: 3.00

# Bennett's only engraved-text feature (Shuttle_Label1a/1b/Shuttle_Label2,
# LabelText() in lib/bennett.py) - NOT a ring of individually angle-placed
# characters like Blickensderfer/Postal's Logo or Mignon's Logo/Label (v2
# calls text() directly with a whole string, halign=valign="center", cut
# INTO the bottom face near the shaft as two independent flat groups, not
# embossed on a curved/chamfered surface) - kept under its own v2-matching
# `label:` section rather than forced into the other machines' `logo:`
# schema, since the field shapes don't correspond (no text_spacing/
# position_offset_deg/radial_offset_mm - see lib/bennett.py's
# _build_text_string()/LabelText() docstrings for the placement chain).
label:
  # v2's real value is "Courier New:style=bold", not a file path/not
  # installed here - nearest real bold monospace-ish file on disk.
  font_path: "/home/lchau/fonts/Library/Typewriter & Monospace/Courier Prime-Bold.ttf"
  label1a: "Leonard"     # Shuttle_Label1a
  label1b: "Chau"        # Shuttle_Label1b
  label2: "2025"         # Shuttle_Label2
  label_size_mm: 1.7     # Shuttle_Label_Size - prefixed (unlike font.size_mm)
  # because tune.py's patch_yaml_value() does a flat, section-unscoped
  # regex search for the key name across the whole YAML text - two
  # differently-scoped fields both literally named "size_mm" would
  # collide there regardless of tune.py's own per-tab bookkeeping (this
  # is exactly what broke Bennett's Font & Alignment tab: see git log).
  # Mignon's own label.* keys (label_text_size_mm etc.) already follow
  # this same convention for the same reason.
  # Z offset added to Bottom_Countersink_Depth for where the (fixed 2mm
  # deep, not itself configurable in v2 - see LabelText()) cut starts.
  depth_mm: 0.2          # Shuttle_Label_Depth
  # Radial (world X) distance of each label's text from the shaft center,
  # positive = same side as label1a/label1b, negative = opposite side
  # (label2). v2 only ever wrote label1a/label1b as one shared group
  # offset with label1a further nested 2.25mm inside it - see
  # lib/bennett.py's LabelText() docstring for why that nesting was
  # actually two independent radial numbers all along, not a stacking
  # offset. Defaults below reproduce v2's geometry exactly at the stock
  # element.shaft_diameter=3.4 (Shaft_Diameter/2+1.5+.25[+2.25 for 1a] /
  # -(Shaft_Diameter/2+1.75+.5) for label2) but - unlike v2 - no longer
  # move automatically if shaft_diameter changes, since they're now each
  # a real independent config value rather than a shaft-relative formula.
  label1a_radial_mm: 5.70   # Shuttle_Label1a_Radial - v2 line 419+422
  label1b_radial_mm: 3.45   # Shuttle_Label1b_Radial - v2 line 419
  label2_radial_mm: -3.95   # Shuttle_Label2_Radial - v2 line 427

# Secondary font - characters listed in font2_chars are struck in this
# font/size instead of the main one. Same feature the Selectric family and
# Hammond Split have, under the same key names. Empty font2_chars =
# inactive (the default), so this changes nothing until it is filled in.
# The real use is glyph coverage: measured across the 170 distinct
# characters in all 28 Blickensderfer layout presets, Royal Vogue v3 is
# missing 87 (fractions, currency), Erica Type 52 (including "@"), Alma
# Mono and CMU Typewriter 50 each, and no non-Hebrew font covers the
# Hebrew-English preset at all.
font2:
  font2_path: ""            # blank = use the main font
  font2_size_mm: 0.0        # 0 = use the main font size
  font2_chars: ""
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

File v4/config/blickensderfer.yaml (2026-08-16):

# Blickensderfer type element - all real parameters ported 1:1 from
# v2/blickensderfer.scad (see that file for authoritative source/comments).
# Derived values (Shaft_Diameter, Clip_OD, Drive_Pin_Countersink_ID,
# Bottom_Slope/Bottom_Z_Offset, Core_Top_Z/Core_Bottom_Z/Core_Taper_Top_Z,
# Baseline_Z_Offset, Logo_Radius) are computed in code from these, not
# duplicated here.

# generate.py/export_glyphs.py dispatch on this key to import
# blickensderfer.py vs postal.py - see lib/cylinder_machine.py's docstring
# for the shared-module mechanism this feeds into. Defaults to this value
# when absent, so older configs need no changes.
machine: blickensderfer

font:
  path: "/home/lchau/fonts/Custom & Modified/FreeMono - Thin Weight (Leonard Chau).ttf"
  size_mm: 3.7

# Secondary font - characters listed in font2_chars are struck in this
# font/size instead of the main one. Same feature the Selectric family and
# Hammond Split have, under the same key names. Empty font2_chars =
# inactive (the default), so this changes nothing until it is filled in.
# The real use is glyph coverage: measured across the 170 distinct
# characters in all 28 Blickensderfer layout presets, Royal Vogue v3 is
# missing 87 (fractions, currency), Erica Type 52 (including "@"), Alma
# Mono and CMU Typewriter 50 each, and no non-Hebrew font covers the
# Hebrew-English preset at all.
font2:
  font2_path: ""            # blank = use the main font
  font2_size_mm: 0.0        # 0 = use the main font size
  font2_chars: ""

logo:
  font_path: "/home/lchau/fonts/Library/Typewriter & Monospace/OCR-A II Regular.ttf"
  text: "Leonard Chau 2026"
  text_size_mm: 2.5
  text_spacing: 7.0
  position_offset_deg: 180.0
  text_offset_deg: 180.0
  # placement radius = Logo_Radius + this. Real v2 value is 1.5 - at that
  # value, this exact layout's angular spacing coincidentally puts the
  # logo text within ~0.4mm of a DHIATENSOR column (see SESSION_LOG.md) -
  # not an issue at this text/spacing, but re-check if either changes.
  radial_offset_mm: 1.6

element:
  element_diameter: 34.0
  platen_diameter: 32.258
  min_final_character_diameter: 35.0   # Char_Protrusion = (this - element_diameter)/2
  element_height: 17.15
  wall_min_thickness: 1.5
  wall_chamfer: 0.5
  roof_offset: 0.5
  speed_hole_id: 5.568
  speed_hole_qty: 8
  speed_hole_radial: 11.25
  core_id_in: 0.125                    # Core_ID_Mm = this * 25.4
  core_groove_qty: 16
  core_groove_d: 0.6
  core_chamfer: 0.5
  core_bottom_offset: 2.5
  core_contact_length: 4.0
  core_web_width: 2.0
  core_web_qty: 3
  core_web_length: 7.0
  clip_height: 3.0
  clip_wire_od: 0.554
  clip_opening: 1.0
  clip_bite: 0.7
  drive_pin_widthmm: 3.737
  drive_pin_length: 3.6
  drive_pin_radial: 10.9
  drive_pin_countersink_depth: 2.0
  drive_pin_support_radial_offset: 0.5
  drive_pin_support_height: 2.0
  # Which drive fitting the element is cut for. 0 = later (a rectangular
  # pin); 1 = early (a radial SLOT - v2 spells these "later"/"early",
  # blickensderfer.scad:233). Both are ported. Switching this changes the
  # drive-pin cut, the countersink support boss inside HollowSpace(), and
  # the resin drive-pin support together - see blickensderfer.py's
  # _drive_pin_countersink().
  drive_pin_style: 0
  # Early-style trio (v2:234-236) - only read when drive_pin_style is 1.
  drive_pin_width_oldmm: 2.05          # slot width, before drive_pin_width_offset
  drive_pin_length_old: 3.5            # slot length, and its countersink diameter
  drive_pin_length_start_old: 9.3      # slot's INNER end; radial centre = this + length/2
  core_id_offset: 0.14                 # print-tolerance addition to shaft minor diameter
  drive_pin_width_offset: 0.15
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

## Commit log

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2023-10-25 Fixed Bennett Print Orientation, modified Blick weight adjustment from ellipse to square
    [1025.scad, 914.scad]
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2024-11-03 Improvements and cleanup
    * Disabled pitch label in Composer mode.
    * Cleaned up some outdated comments.
    * Decreased INSIDE RAD to 14.3.
    * Increased BOSS_INNER_RAD to compensate for shrinking.
    * Slightly lowered character weight.
    * Increased NOTCH_WIDTH for better fit.
    * Replaced Em dash with En dash. Em dash is too wide.
    * Fixed Platen Diameter being hardcoded instead of using the variable.
    * Added COMPOSER_VERT_OFFSET variable to correct for the different vertical aligment on the Composer.
    [SelectricElement88_Modified.scad]
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2024-11-04 corrections
    offset character rotation rather than translation for composer characters
    added composer_center_chars
    [SelectricElement88_Modified.scad]
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2024-11-04 fixes
    reverted back to translation offset
    added detent_teeth_clock_offset (tbd if this is a incorrect parameter)
    [SelectricElement88_Modified.scad]
2024-11-04 fixes
    default value of composer_center_offset fixed
    detent_teeth_clock_offset fixed
    notch_angle linked to detent_teeth_clock_offset
    [SelectricElement88_Modified.scad]
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2024-11-05 Update IBM.scad
    * Fixed Notch width tolerances.
    * Fixed En Dash having been replaced by Underscore in the Composer keymaps.
    [IBM.scad]
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2024-11-06 Update IBM2.scad
    * Added Composer font size adjustment in point increments.
    * Added decimal point to CUSTOMHALIGNOFFSET for finer control.
    * Fixed CUSTOMHALIGN being enabled for S88 instead of Composer
    * Fixed FONTSIZE and FONT2SIZE being reversed.
    [IBM2.scad]
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2024-11-11 Update IBM2.scad
    * Move notch supports away from the notch to avoid them extending to the notch inside face.
    * Update Composer y offset.
    [IBM2.scad]
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2024-11-12 changes and additions
    * introduced different hollow roof profile
    * reduced TOPFLAT_THICKNESS default value
    * introduced BOSS_CLEARANCE (min height for no obstruction)
    * bug fixed web
    [IBM2.scad]
2024-11-13 composer type test update
    fixed to show both FONT and FONT2 chars
    [IBM2.scad]
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2024-11-14 changes, cleanups, additions, fixes
    * changed default value of TOPFLAT_THICKNESS from 2.5 to 3
    * cleaning and rearranging of code
    * mainly handling RENDER_SELECTION and including "ALL--" array variables
    * added presets for composer type testing
    [IBM2.scad]
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2024-11-15 fixes and corrections
    * added chamfers to both sides on hammond split shuttle
    * adjusted handling of tube diameter offsets
    * changing default values of pin parameters
    [HammondSplitShuttle.scad]
2024-11-15 Update IBM2.scad
    * Fixed Minkowski render bug causing it to ignore mink_fn when FONT_WEIGHT_OFFSET was enabled. Calculations now take ~85% less time.
    [IBM2.scad]
2024-11-15 Update IBM2.scad
    * customhalign and customvalign effects are now visible in the type test. Flipped Customhalign direction so it's more logical in the type test view where you'd want to adjust it.
    [IBM2.scad]
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2024-11-17 changed handling of folder clearance.
    not quite right i think but will fix later
    [HammondSplitShuttle.scad]
2024-11-17 Update IBM2.scad
    * uwu
    * increased Topflat thickness to drop the layer line below R1
    * platen cutout adjustments reset to 0
    [IBM2.scad]
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2024-11-17 Update IBM2.scad
    * Fixed 6 and 9 being flipped in the Composer hemisphere map
    [IBM2.scad]
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2024-11-26 Fixes
    * fixed cutout test angle array
    * included lowercase composer us hemisphere for debugging
    * adjusted handling of hemisphere map
    * created new cutout test console array output and handling
    * cutout test output array now ordered by hemisphere/row
    *
    [IBM2.scad]
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2024-11-27 additions to test element parameters
    * fixed console output of character details
    * changed handling of cutout test angle array
    * added draft angle test
    * added mink long offset test
    [IBM2.scad]
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2024-12-01 additions and changes
    * added MINKOWSKI_FLAT_OFFSET
    * added resin rod chamfer to IBM and HSS ROD_BASE_C
    * HSS cleaned fixed fn for resin supports
    * new jsons
    * remove echo() in SingleMinkowski()
    [HammondSplitShuttle.scad, IBM2.scad]
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2024-12-01 Update IBM2.scad
    * Removed deprecated features
    * Some ball dimensions and language defaults hidden from configurator to declutter it
    * Fixed Rays pointing in the wrong direction (upside down)
    * Removed top-down resin print as option
    * Custom layout is now I's instead of vertical pipes, serifs are helpful for judging impression.
    * Fixed some typos
    [IBM2.scad]
2024-12-02 fixes
    * fixed S12 language
    * added machine-unique platen ODs
    * fixed S12 character mapping
    * fixed console test output for S12 support
    [IBM2.scad]
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2024-12-02 Update IBM2.scad
    * Small fixes to formatting
    * cleanup
    * alignment adjustments
    [IBM2.scad]
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2025-01-19 changes to all sorts of things
    * fixed postal and blick2 crashing with some fonts +minkowski
    * finalized hammond split shuttle 2
    * changed resin support cut groove design
    * blick2 jsons
    * postal jsons
    * hammond split2 jsons
    [Blickensderfer2.scad, HammondShuttle.scad, HammondSplitShuttle2.scad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]
2025-01-20 updates and fixes
    * fixed blick2 element mapping in reverse order
    * included shuttle height offset for hammond shuttles, flipped resin print orientation to compensate for nonparallel first layers
    [Blickensderfer2.scad, HammondShuttle.scad]
2025-01-30 fixes and changes
    bennett: revisited HollowSpace method, fixed high fn count for various features, added XSection, removed Assert, added Render
    blick: hebrew support, char mod support, added Early Style Drive Pin option, changed secondary core geometry to below clip, teststring improvements
    hammond shuttle: changed text positioning to compensate for height offset
    split shuttle: added glue grooves, added logo
    postal: changed baselines, var names, added logo, changed secondary core to below wire clip
    [BennettElement.scad, Blickensderfer2.scad, HammondShuttle.scad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]
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2025-05-23 fixes and improvements
    Blick: added layouts, reduced resin support count, removed raft, fixed type cpi test
    Bennett: added layout, fine tuned parameters, improved shaft design,
    [BennettElement.scad, BennettLayouts.scad, Blickensderfer2.scad]
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2026-07-02 Add v2.0 shared library refactor
    Extracts the glyph pipeline, resin support, core/shaft, layout data, and
    testing-sweep logic duplicated across every machine into v2/lib/, leaving
    thin per-machine wrapper files. Originals are untouched. Verified with
    openscad-nightly: all 8 v2/ files render to clean STL with zero
    warnings/errors, and the cutoutTest/baselineTest/testLayout calibration
    workflow (including a reference-keyboard dropdown for Blickensderfer/
    Bennett/Mignon) was confirmed against real console output.
    See CHANGELOG.md for the full breakdown of what moved where.
    [bennett.scad, blickensderfer.scad, hammond.scad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]
2026-07-02 Unify Global/Render Parameters and adopt Capital_Snake_Case everywhere
    Audits across all 8 v2 files found Global/Render Parameters weren't
    actually consistent (some machines only bridged old names to the lib's
    canonical ones instead of renaming the declarations, and section order
    had drifted). Fixed, then converted every top-level variable in v2/ from
    a mix of camelCase/underscore-style/SCREAMING_SNAKE_CASE to a single
    Capital_Snake_Case convention - OpenSCAD's Customizer preserves case when
    displaying variable names, so this is what actually shows up in the
    sidebar during calibration, not just a source-style preference.
    Testing with openscad-nightly caught several real bugs along the way
    (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
    [bennett.scad, blickensderfer.scad, hammond.scad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]
2026-07-05 Move v1 machine files into v1/ folder
    Consolidates all original per-machine directories (Bennett, Blickensderfer,
    Hammond, HeliosKlimax, IBM, Mignon, Postal, Type Slugs) plus loose root
    utility files under v1/, separating them from the v2/ shared-library
    refactor. Updates README links accordingly.
    [BennettElement.scad, BennettLayouts.scad, Blickensderfer2.scad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]
2026-07-05 Extract shared ResinRod primitive, migrate Bennett/Mignon onto it
    Splits the universal single-rod shape (tapered-tip hull + capsule shaft +
    optional raft) out of lib/resin_support.scad into lib/resin_rod.scad, so
    machines with their own support-placement pattern can still reuse the one
    rod primitive without pulling in Blick/Postal's speed-hole/sloped-floor
    placement system. Blickensderfer2/Postal are unaffected (verified
    byte-identical STL before/after).
    Bennett and Mignon each hand-rolled their own rod shape; both migrate to the
    shared primitive while keeping their own placement rings/raft/groove local.
    Caught and fixed a real discrepancy in the process: Bennett's original
    centered its tip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
    [bennett.scad, mignon.scad]
2026-07-05 Unify Mink_On naming across all v2 machines
    Bennett/Mignon/Helios Klimax each carried a leftover Debug_No_Minkowski
    boolean (Debug_No_Minkowski=true; Mink_On=!Debug_No_Minkowski;) instead of
    declaring Mink_On directly like the other 5 machines. Collapsed to one name
    everywhere - same default/behavior, verified byte-identical STL output
    before/after. Also fixes Mignon's ElementLabel() to check Mink_On directly.
    [bennett.scad, heliosklimax.scad, mignon.scad]
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2026-07-05 Remove v3/ parallel-per-glyph rendering experiment
    The process-per-glyph split did avoid the superlinear blowup from doing all
    84 glyphs in one CSG tree (confirmed: full ring never finished past 30 min,
    isolated glyphs ran in ~4s each), but running the full pipeline with
    Mink_On=true exposed worse problems: 15%+ of glyphs individually blew up to
    absurd sizes (one glyph alone hit 1.6GB as an STL fragment) with the current
    fallback font, and keeping per-glyph STL fragments around during assembly
    is expensive on disk regardless. Not a viable approach as built - reverting.
    History retained in commits c79c97e..HEAD~1 if revisited later.
    [blickensderfer.scad]
2026-07-06 Add Selectric III (96char) render mode to v2/ibm.scad
    Adds Render_Mode=2 alongside Composer/Selectric I-II, reusing the same
    physical ball shell (4 rows x 24 chars instead of 22). Character layout
    derived from the selectricrescueatx/TypeElements reference repo's
    charmap96, independently re-derived and corrected after checking the
    rendered result against a real physical Selectric III element (the first
    derivation attempt had the longitudinal character order mirrored).
    Also:
    - Fixed a real naming bug: Latitude_Spacing/Longitude_Spacing (and every
    related lat/long local variable) were swapped relative to standard
    geographic convention. Renamed throughout, verified byte-identical STL
    for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
    [ibm.scad]
2026-07-06 Re-apply dropped tooth-scale fix; un-hide customizer sections
    The Tooth() narrowing fix (scale by Chars_Per_Row_All[1]/Chars_Per_Row_All[Render_Mode],
    matching the reference repo's own scale([1.0,88/96,1.0])) documented in the
    previous commit's CHANGELOG entry was missing from the actual committed
    code - lost somewhere during verification. Re-applied and re-verified:
    Composer/Selectric I-II unaffected, Selectric III's tooth geometry matches
    the post-fix vertex/facet counts again.
    Also converts every "/* [ Hidden ] */" customizer section (typeball
    dimensions, character polar positioning offsets, and all three machines'
    character-mapping data in ibm_layouts.scad) to a real, visible section
    na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
    [ibm.scad]
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2026-07-06 Make resin detent clock offset additive with the teeth clock offset
    ResinRodAssemble()'s detent-teeth resin rod ring should still track wherever
    Detent_Skirt_Clock_Offset actually puts the teeth - Resin_Detent_Clock_Offset
    is meant as a small additional fine-tune on top of that, not a replacement.
    [ibm.scad]
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2026-07-06 Fix Bennett resin rods missing raft (regression from ResinRod migration)
    Resin_Rod_Raft=false assumed ResinSupport()'s own big raft/groove ring (at
    Element_Diameter/2, the outer edge) covered every rod, but the middle and
    inner rod rings sit well inside that radius and never touch it - so every
    rod in those two rings had no anchor to the build plate at all. Re-enabled
    Resin_Rod_Raft and gave it a real Resin_Raft_Thickness (was 0, which
    degenerates the raft to zero height even when enabled). Verified visually:
    every rod now has its own raft foot.
    [bennett.scad]
2026-07-06 Fix Bennett resin raft z-datum (raft was below z=0, not coplanar with ring)
    Comparing against Blickensderfer2/Postal's own resin wiring: the previous
    fix left Resin_Min_Rod_Height=0, which per lib/resin_rod.scad's formula
    puts the per-rod raft at z=[-Resin_Support_Thickness, 0] - the wrong side
    of the datum. Both the old local ResinRod's raft flare and Bennett's own
    outer "Create Raft" ring sit at z=[0, Resin_Support_Thickness]. Fixed by
    setting Resin_Min_Rod_Height=-Resin_Raft_Thickness to cancel that out.
    Confirmed visually: raft feet now sit flush with the outer ring instead of
    hanging below it.
    [bennett.scad]
2026-07-09 Add v1/v2 byte-check parameter sets; fix HeliosKlimax baseline/placement bug
    Rendered every v1 machine against its v2 replacement with matched
    Customizer parameter sets (minkowski forced off, render forced on) and
    diffed the resulting STLs byte-for-byte. Adds one dated bytecheck.json
    per machine per version (16 total) so the comparison is reproducible.
    IBM and Hammond (split) matched immediately. Blickensderfer and Postal
    only matched once their v2 JSON was re-pinned to v1's original values
    (v2's hardcoded defaults had drifted via later tuning - font, dimensions,
    resin values - unrelated to the refactor itself). Bennett still differs
    after re-pinning: its resin supports were migrated onto t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
    [heliosklimax.scad]
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2026-07-13 Add selectable horizontal text alignment (Text_Align_Method) to v2 glyph pipeline
    OpenSCAD's halign="center" centers on ink bounding box, not advance width,
    which is wrong for narrow glyphs like "." on a typewriter element (see
    docs/text-centering.md). Adds AlignedText() to lib/glyph_pipeline.scad with
    three selectable methods (legacy ink-bbox center, textmetrics-based advance-box
    center, textmetrics-based fixed-CPI-pitch left-align) plus a universal
    Text_Align_X_Offset fine-tune, wired into the Customizer and TypeTest() of all
    six lib-based v2 machines. Defaults are behaviorally identical to today's
    output. hammond_split.scad, ibm.scad, and v1 files are intentionally untouched
    (documented a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
    [bennett.scad, blickensderfer.scad, hammond.scad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]
2026-07-14 Fix Text_Align_Method formulas; add Show_Align_Bounds preview overlay
    Empirically verified (textmetrics probes) that OpenSCAD's native halign="center"
    centers on the advance box, not the ink bbox as previously assumed. That
    invalidated the original method 1/2 formulas: method 1 (translate(-advance.x/2))
    was mathematically identical to native center in every case, and method 2
    (pin pen origin to a fixed pitch) coincided with method 0 whenever a font's
    own advance width matched its target CPI - true by construction for a
    well-made monospace typewriter font, which is why periods stayed near center.
    Method 1 is now true ink-bbox centering (erases native bearing, a capability
    OpenSCAD has no nat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
    [bennett.scad, blickensderfer.scad, hammond.scad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]
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2026-07-14 Add right-align method and second per-character alignment override set
    - New Text_Align_Method value 3 ("ink right", fixed CPI pitch): mirrors
    method 2 but pins the glyph's ink RIGHT edge to the slot's right edge
    instead of the left, for right-aligning narrow punctuation.
    - New Text_Align_Modified2_Chars/Text_Align_Method_Modified2/
    Text_Align_X_Offset_Modified2 set, mirroring the existing Modified set,
    so two disjoint character groups (e.g. left-pinned ".,:;" and
    right-pinned "'\"") can each get independent alignment treatment.
    Checked before the first Modified set in AlignedText() - a character
    matching both resolves to Modified2.
    - All three X-offset params (Text_Align_X_Off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
    [bennett.scad, blickensderfer.scad, hammond.scad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]
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2026-07-18 Standardize Text_2D_Fn/Mink_Fn across v2 machines; add v3 draft prototyping scripts
    Wire Text_Fn into the lib's Text_2D_Fn hook on every v2 machine so glyph
    curves no longer silently inherit Surface_Fn, and align Mink_Fn to a shared
    default. Add v3/ prototype scripts exploring draft-angle generation
    approaches (loft, plateau, slabs) for the next-gen glyph pipeline.
    [bennett.scad, blickensderfer.scad, hammond.scad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]
2026-07-18 Add v4: mesh-vertex-remap type element pipeline (Blickensderfer)
    Config-driven Python/trimesh pipeline that ports v2/blickensderfer.scad's
    Additive/Subtractive/FullElement structure to direct per-vertex mesh
    manipulation (adapted from a friend's TypeCylinder tool) instead of
    OpenSCAD's minkowski(cone) draft step, plus resin print supports. See
    v4/README.md for full architecture, known limitations, and the several
    defects found/fixed while porting (nesting-depth hole classification,
    draft direction, WireBite orientation, revolve_polygon axis-edge
    degeneracy, trimesh reprocessing corruption in place_on_cylinder).
    Also adds v2/mink_glyph_tester.scad, a standalone harness for the
    existing minko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
    [mink_glyph_tester.scad]
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2026-07-19 v4: replace per-vertex draft offset with a real Minkowski sum (manifold3d)
    The per-vertex outline-offset draft mechanism (plus its gated self-union
    repair patch) could not reliably produce valid geometry on narrow glyph
    features - self-intersecting folds on H/e/m, and self-union corrupting
    multi-island glyphs like i's dot. Replaced entirely with a real Minkowski
    sum between the flat glyph and a draft cone (manifold3d.Manifold.
    minkowski_sum), which cannot produce a self-intersecting result on any
    input topology. Fixes three real bugs found while building this (doubled
    depth, reversed dilation direction, raw CSG triangulation noise) and one
    architectural bug in how the platen scallop interact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
    [blickensderfer.yaml]
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2026-07-19 v4: real platen cutout (boolean cylinder, not parabola warp) + config expansion
    Replaces the platen scallop's per-vertex parabola-warp approximation with
    a real boolean cylinder subtraction (matching the real machine/v2's
    PlatenCutout()), applied before the Minkowski sweep - same
    before-not-after ordering lesson as the earlier draft-angle fix, now with
    an actual swept cylinder instead of a vertex nudge. platen_radius_mm (the
    existing small-angle-approximation coefficient) is inverted to recover
    the real platen radius rather than adding a redundant parameter. Verified
    directly against the exact circle formula before wiring in, including a
    synthetic test that caught a real requirement: the blo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
    [blickensderfer.yaml]
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2026-07-19 v4-tui: reorganize tuner tabs, add Layout/Build dropdowns and Type Test
    - Merge Font + Alignment into one tab; mark Element as advanced/rarely-changed
    - Move build.points_per_mm/separation_mm/minkowski_enabled/render_core_groove/
    simplify_tolerance_mm into the Quality tab alongside the *_fn facet counts
    - Replace the raw layout.rows editor with a Layout tab: a dropdown of v2's six
    named Blickensderfer keyboard layouts (DHIATENSOR, QWERTY, SCANDI,
    HEBREW_ENGL, CHARIENSTU_DE, CHARIENSTU_DE_MOD), writing the full rows block
    via new patch_yaml_rows(); falls back to "custom" when rows don't match a
    preset
    - Replace the raw resin_support checkbox with a Build tab: a single dropdown
    (El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
    [blickensderfer.yaml]
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2026-07-19 v4-tui: fix Quick Preview always forcing Element Only
    _run_build's fast path hard-coded --no-resin-support, so Quick Preview
    ignored the Build tab's dropdown and always built FullElement even when
    "Element Resin Print" was selected (Render was unaffected - already
    correct). Preview now only forces --no-minkowski/--no-core-groove for
    speed and defers to whatever build.resin_support was just saved from
    the dropdown, same as Render.
    [blickensderfer.yaml]
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2026-07-19 v4-tui: persist Type Test's text/CPI/LPI to config
    Previously these lived only in TUI widget state, resetting to hardcoded
    defaults on every restart - unlike every other tunable field. Added a
    type_test.* config section (cpi/lpi as plain floats, text as a literal
    block scalar since it can contain embedded newlines) and a new
    patch_yaml_text_block() patcher (analogous to patch_yaml_rows for
    layout.rows - patch_yaml_value's one-token regex doesn't handle
    multi-line values). _collect_values/_save_to_yaml/action_reload all
    extended to cover the two new bespoke widgets same as
    resin_support/layout rows already were. action_render_type_test now
    saves the whole form first, same as Preview/Render, s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
    [blickensderfer.yaml]
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2026-07-19 v4-tui: fix quit not saving - "q" never fires while a field has focus
    Root cause of "quitting with q, Type Test doesn't save": it wasn't a
    save bug at all - pressing "q" while any Input/TextArea has focus gets
    consumed as a literal typed "q" character by the focused widget, so
    the app-level quit binding never fires and nothing saves, because
    nothing quits. Confirmed directly: typing into Type Test's text then
    pressing "q" just appends "q" to the text and leaves the app running.
    This affects every text-entry widget in the app, not just Type Test -
    it's just the field most likely to be actively focused right when
    someone wants to quit.
    Added ctrl+q as a second binding for quit - a control com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
    [blickensderfer.yaml]
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2026-07-19 v4-tui: master/running/saved config tiers, config Browse, Reset to Defaults
    Three-tier config model, matching the same "temp file, save when you
    mean it" philosophy already used for the output STL:
    - MASTER is whatever path is passed on the command line - tune.py now
    NEVER writes to it (previously the config path given on the CLI was
    edited in place). A new Browse button (top of the screen) switches
    to a different master live, without restarting the app.
    - RUNNING is a per-master scratch copy (<stem>.running.yaml, same
    directory, gitignored) that every edit/save actually goes to -
    bootstrapped from master the first time it's needed, then left
    alone ("once changed, always changed"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
    [blickensderfer.yaml]
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2026-07-19 v4-tui: make Minkowski draft angle configurable, expose on Font & Alignment tab
    Was a fixed glyph_poc.py module constant (MINK_DRAFT_ANGLE/DRAFT_HALF_ANGLE_RAD)
    with no override. Threaded draft_angle_deg through build_glyph, TextRing,
    Additive, FullElement, ResinPrint, configure(), the --draft-angle-deg CLI flag,
    and tune.py's Font & Alignment tab (default matches the real 55deg machine value).
    [blickensderfer.yaml]
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

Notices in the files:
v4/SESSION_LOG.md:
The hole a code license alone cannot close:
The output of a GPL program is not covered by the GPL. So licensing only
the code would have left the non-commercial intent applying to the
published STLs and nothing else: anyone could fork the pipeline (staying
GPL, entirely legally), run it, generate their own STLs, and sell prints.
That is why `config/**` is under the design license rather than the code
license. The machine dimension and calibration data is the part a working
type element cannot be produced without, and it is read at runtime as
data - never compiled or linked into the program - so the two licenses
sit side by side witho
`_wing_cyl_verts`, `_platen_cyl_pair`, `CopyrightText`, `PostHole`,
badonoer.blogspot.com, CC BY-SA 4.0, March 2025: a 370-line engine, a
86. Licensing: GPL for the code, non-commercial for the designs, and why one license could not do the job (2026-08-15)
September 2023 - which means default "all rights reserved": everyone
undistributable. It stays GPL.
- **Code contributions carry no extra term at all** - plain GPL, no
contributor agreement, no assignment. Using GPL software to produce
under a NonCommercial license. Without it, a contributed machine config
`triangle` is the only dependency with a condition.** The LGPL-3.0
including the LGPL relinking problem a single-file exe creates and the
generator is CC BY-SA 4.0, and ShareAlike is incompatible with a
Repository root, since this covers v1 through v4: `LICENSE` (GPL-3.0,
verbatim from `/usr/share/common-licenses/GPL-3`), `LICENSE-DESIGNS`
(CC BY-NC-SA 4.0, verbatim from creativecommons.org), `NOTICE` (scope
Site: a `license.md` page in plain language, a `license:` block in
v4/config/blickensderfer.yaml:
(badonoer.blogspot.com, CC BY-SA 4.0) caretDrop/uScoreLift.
